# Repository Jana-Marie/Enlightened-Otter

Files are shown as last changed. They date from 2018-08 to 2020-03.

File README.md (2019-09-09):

# Enlightened-Otter

Enlightened-Otter is an Open-Source and OSHW work-light for hacker/maker events like the chaos communication congress. It is based upon a STM32F334 with its 
high resolution timer as dual boost 
converter. The main goal is to provide cordless, high CRI, high brightness, flicker-free illumination with a variable color temperature. This is achieved by using LEDs with high a CRI (>93, STW9Q14C) and 
the boost 
converter operating at a frequency of up to 850khz. The PCB also features USB-C (power profile 1) to deliver enough power to charge the 18650 type batteries as well as keep up operation of the boost converter.

Enlightened-Otter can be screwed onto an empty bottle of Mate (or similar), therefore serving with a very small footprint.

## Specs

|								| Typical Value |
| ---		| ---	|
| I*out* (per channel)	 		| 0-500mA 		|
| V*out* (per channel)			| 0-18.5V 		|
| P*out* (per channel)			| 0-7.5W*		|
| Illuminance (3500k @400mA)	| 1600lx*  		|
| Illuminance (6500k @400mA)	| 2000lx* 		|
| V*in* (USB) 					| 4.8-14V  		|
| I*in* (USB) 					| 3A  			|
| V*bat* 						| 3.8V 			|
| I*bat* (max)					| 5A  			|
| Boost frequency				| 500khz**		|
| I*ripple* (@2.5kHz)			| < 0.5mA 		|

\* Needs to be measured again
 
\** Needs to be evaluated again

## Building and flashing

Change *Inc/defines.h* to fit your desires, then build with

`make clean all`

and flash it via Ozone or st-utils

`st-flash --reset write build/*.bin 0x8000000`

## Images V2.1

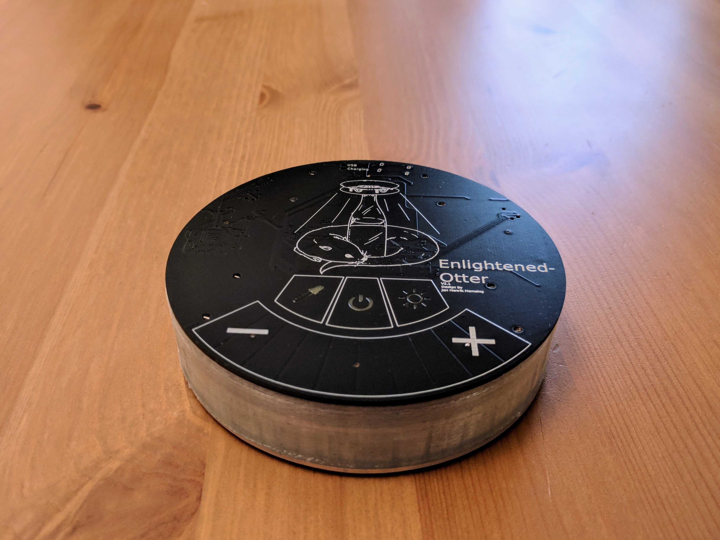
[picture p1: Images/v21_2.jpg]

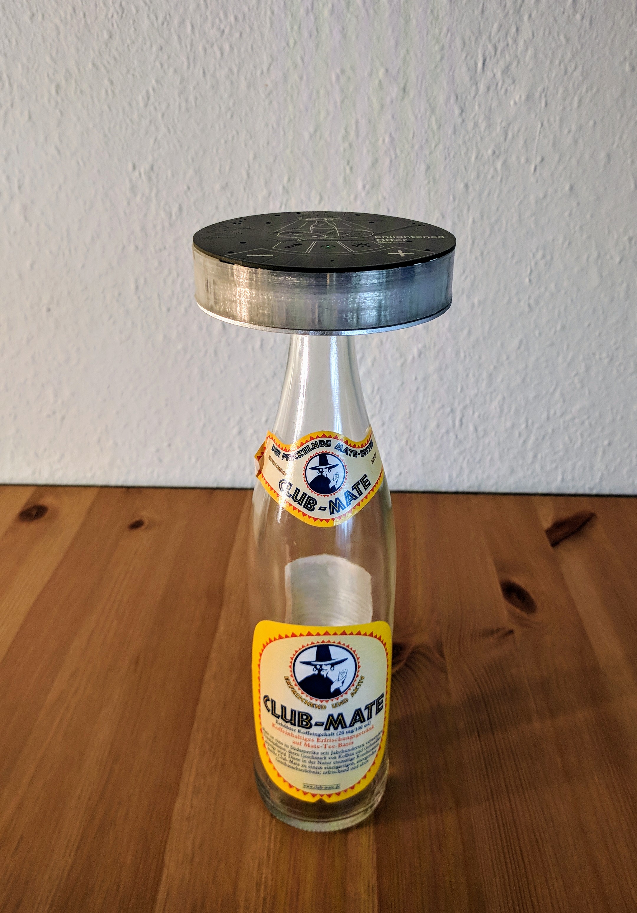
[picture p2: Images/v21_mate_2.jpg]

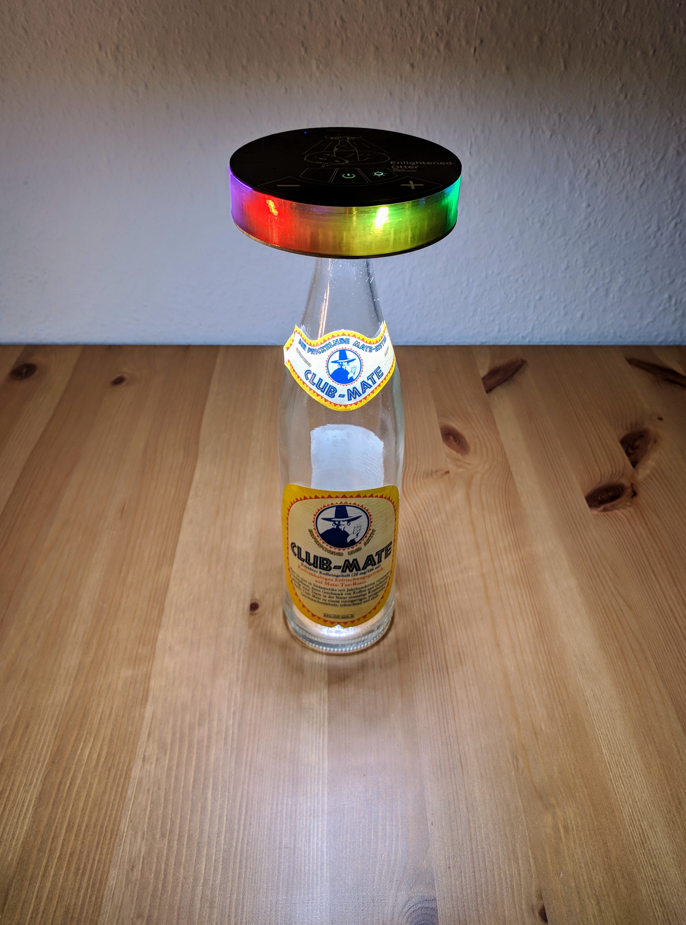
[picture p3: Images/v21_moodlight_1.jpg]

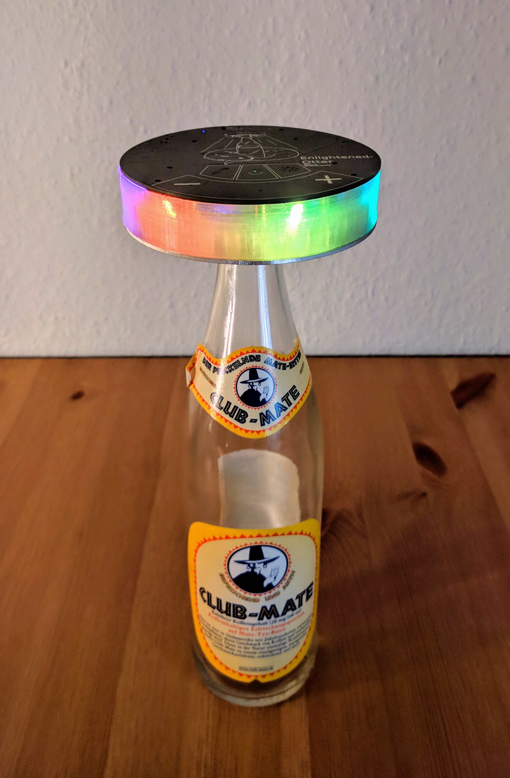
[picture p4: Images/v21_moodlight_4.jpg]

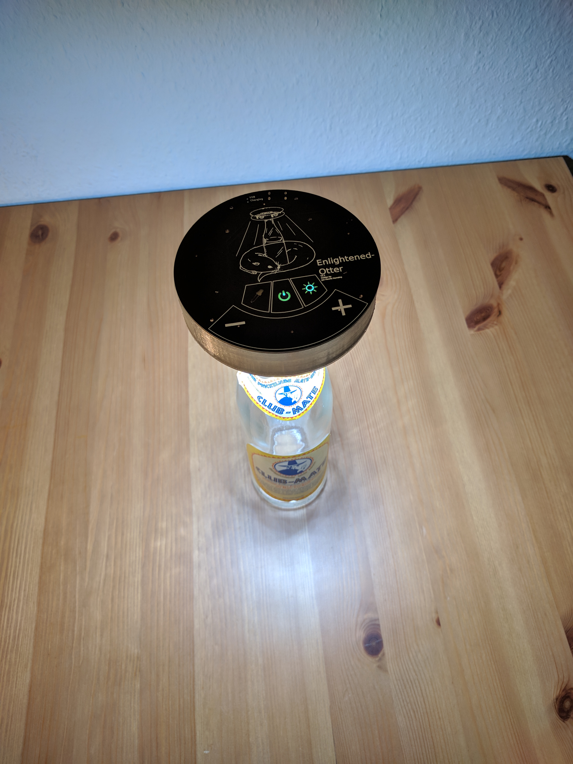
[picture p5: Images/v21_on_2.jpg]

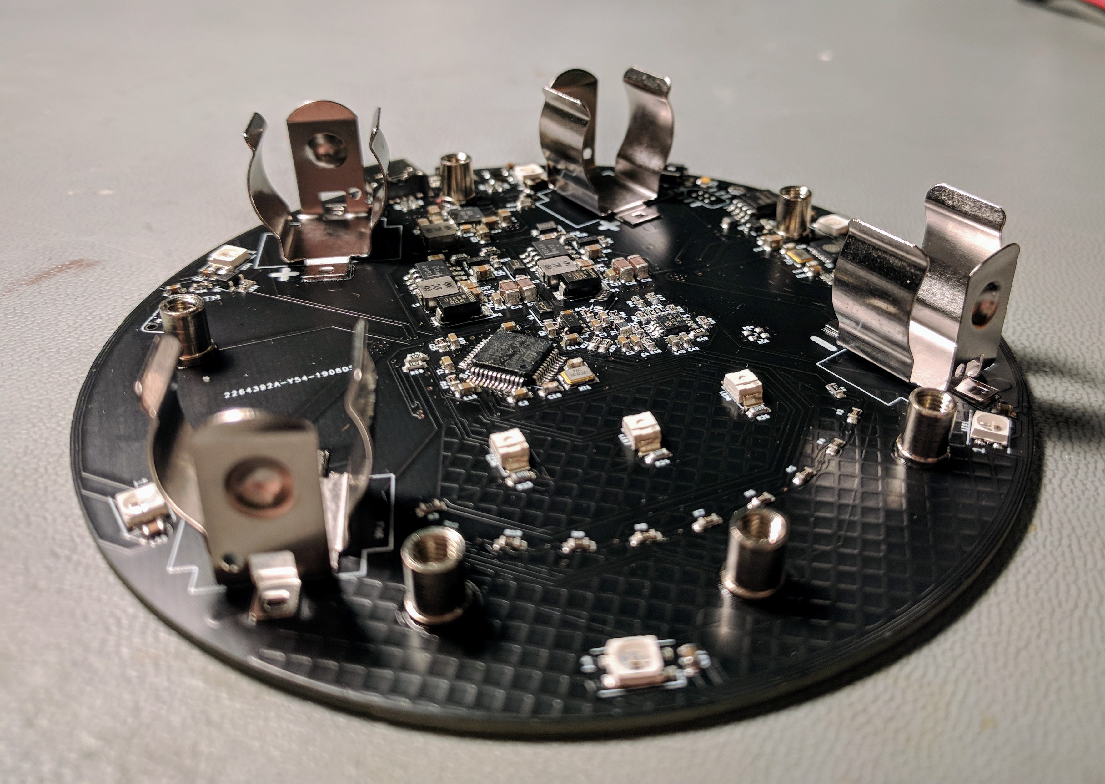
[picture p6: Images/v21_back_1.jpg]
V2.1 Back

## Images V2.0

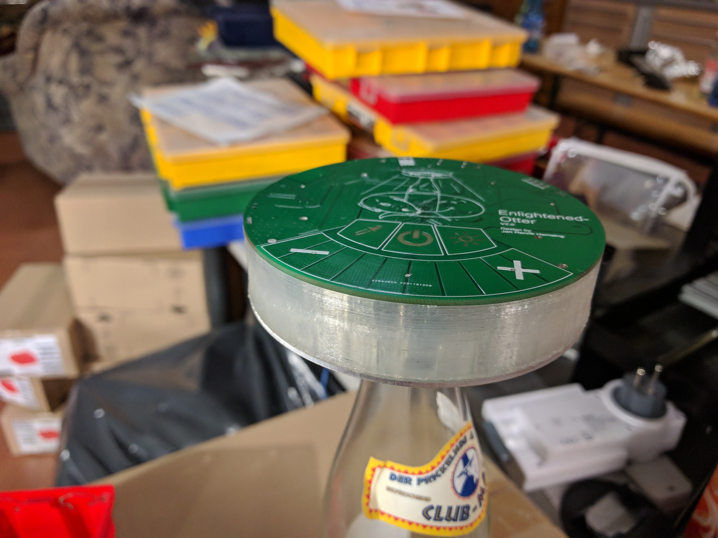
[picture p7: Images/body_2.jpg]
V2.0 Body


## Images V1.1

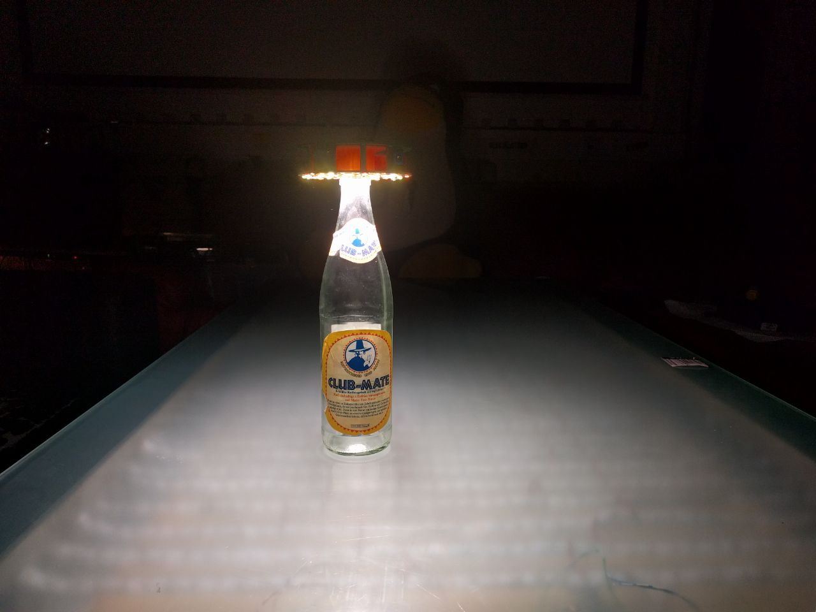
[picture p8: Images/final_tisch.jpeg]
Battery 1

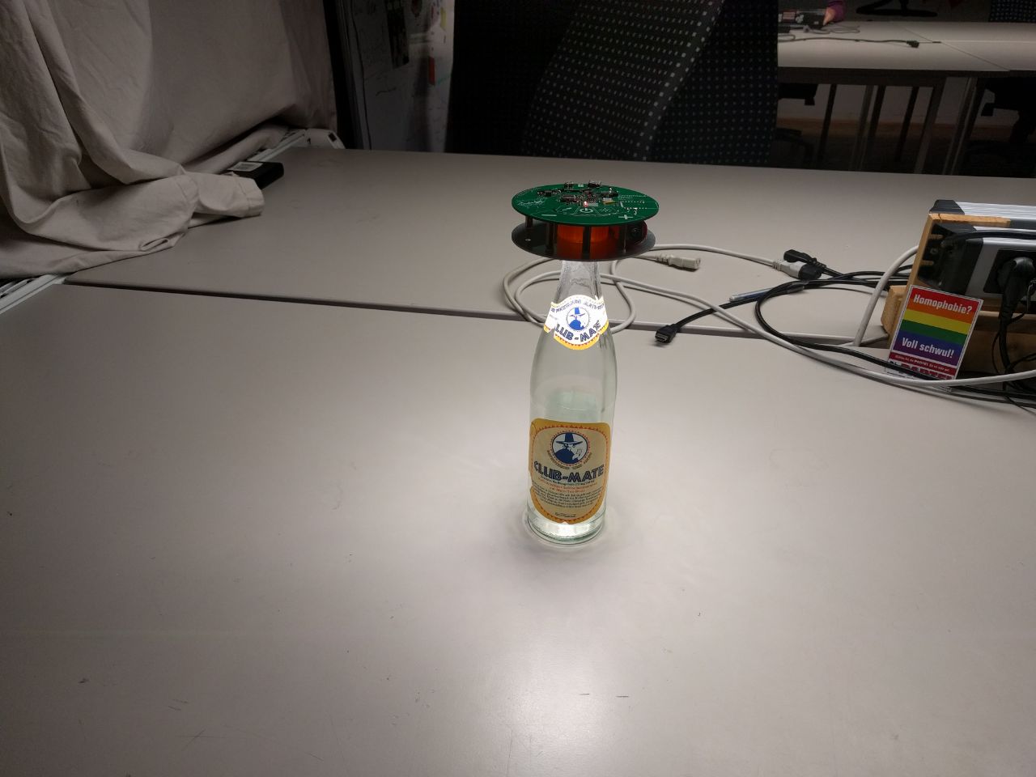
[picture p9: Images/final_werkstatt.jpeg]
Battery 2


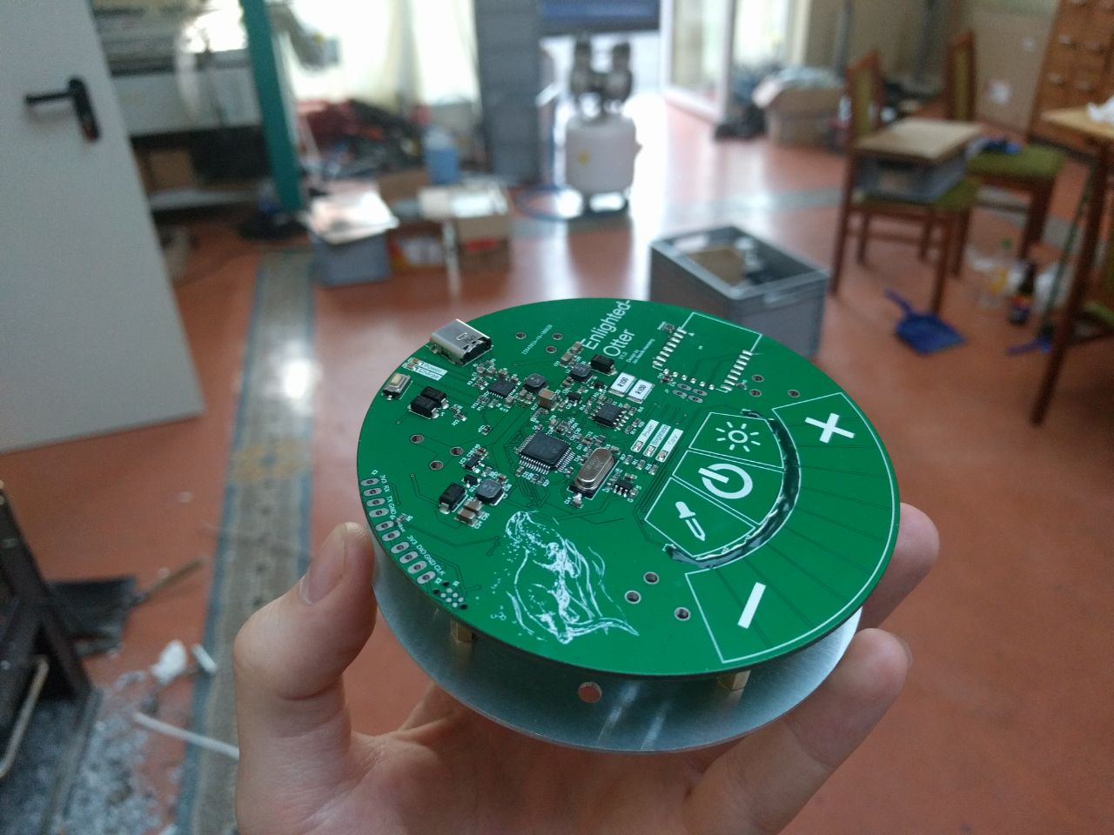
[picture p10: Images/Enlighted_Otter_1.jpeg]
Top View

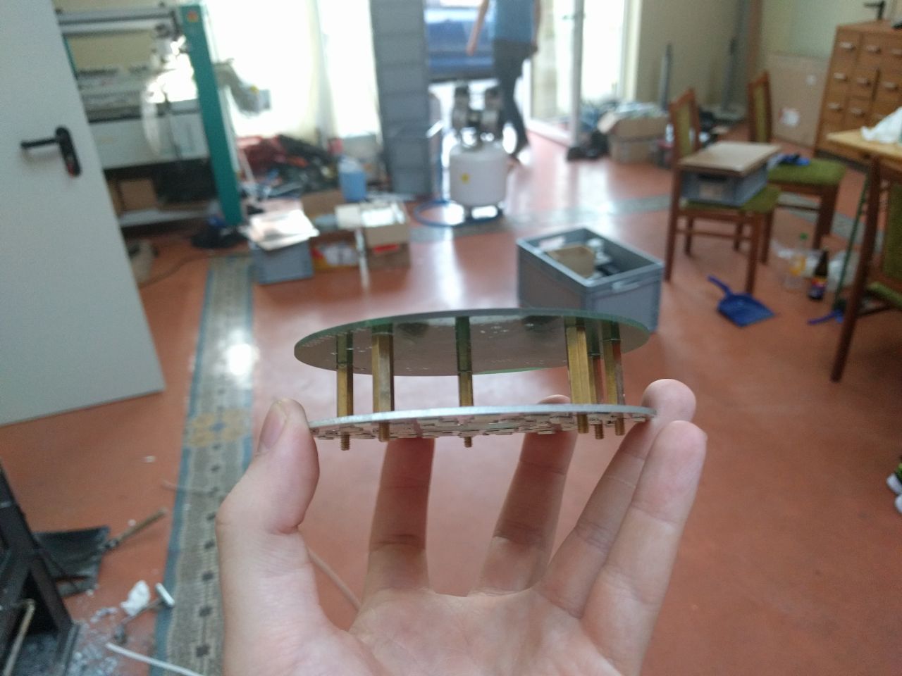
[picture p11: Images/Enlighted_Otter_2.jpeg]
Side View

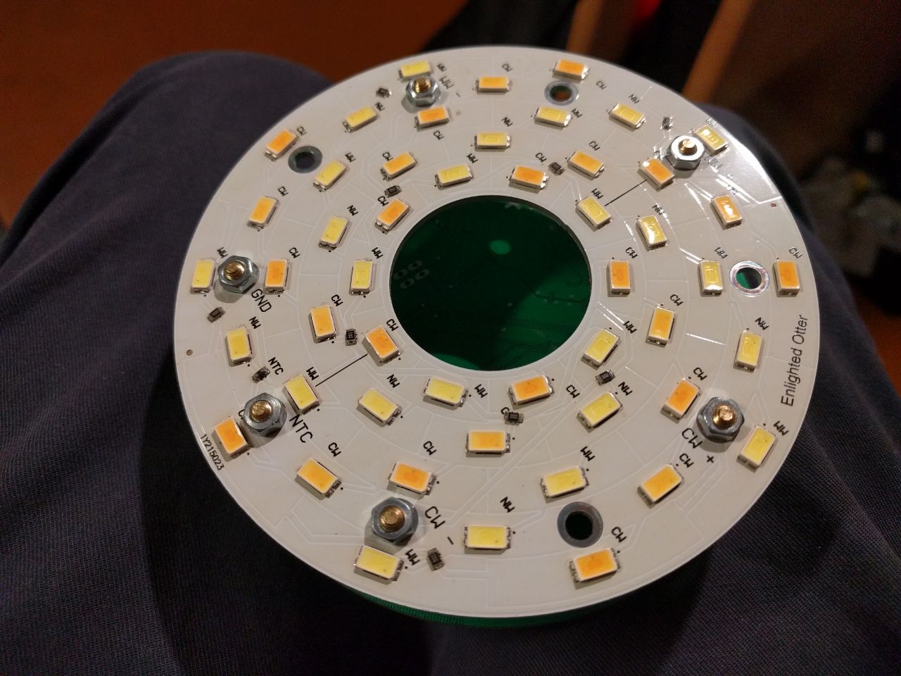
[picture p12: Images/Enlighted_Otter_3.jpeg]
Bottom View


## Videos

Click to play

#### On a Bottle

Finished Prototype (https://twitter.com/JanHenrikH/status/1033489392109797377)

#### Boost converter operation

Boost 1 (https://youtu.be/A-QjU9mWTO4)

#### TSC operation

TSC 1 (https://youtu.be/ADD4yiM9S0Q)

#### LED brightness test

LED 1 (https://youtu.be/DC_eAY72nbw)

## Known Bugs

- Touch does not work when licked (tested by @NiklasFauth)
	- Workaround: Do not lick PCB

## Planning

### Folder structure

- **Src/** : Contains the source files to build the firmware
- **Drivers/** : Contains the STM library files
- **Inc/** : Contains the header files as well as the customization file for the firmare
- **Tools/** : Contains python scripts to generate specific code
- **HW/** : Contains the Schematic, Gerber and other Hawrdware files
- **Images/** : Contains the images used in this repo
- **3D Files/** : Contains the 3D file to be printed as inlet as well as its source
- **/** : Contains other build files e.g. Makefile, linkerscript

### Current state:

PCB V2.1 is here, V2.11 is ordered.

Complete power redesign. HW is flashable, both boost converter work properly up to a current of ~500mA, current regulation works on both boost converters ( < +-0.5mA up to 500mA, regulation frequency is 2.5khz), RT9466 seems to do its job, does work properly on 
batteries, not on USB. Measuring thought the RT does not work, Power down does. LED outputs and Touch inputs work, has correct fault handling.
Advanced User interface is also working, current and color can be set via touch input. Soft on/off works fine. Gamma correcture is applied.
The whole PCB can be shut down by holding the power button.

HW regulates after boot while main loop is basically empty \o/

### To do:

- [ ] measuring throught the RT does not work
- [ ] ADC1 wrong values -> investigate
- [ ] test esp8266
- [ ] implement esp8266
- [ ] visualize battery voltage -> moodlight LEDs
- [ ] Overtemp protection
- [ ] Find more to do's

### Done:

- [x] Implement moodlight LEDs
- [x] touch slider is not super responsive -> investigate
- [x] "Mobile handling"
	- [x] Touch is not that responsive
	- [x] Added filters to touch input
	- [x] Battery low alarm/turnoff -> is implemented, doesnt work, see RT9466 measuring
- [x] everything is super slow when Itarget is 0.0 -> investigate
- [x] UVP
- [x] Port firmware to V2.1
- [x] RT cannot be turned off or cannot charge batteries - investigate
- [x] Optimize code
	- [x] make it less ugly
	- [x] now make it faster
- [x] Test I2C - broken?
	- writing works, reading is buggy, switch to dma
	- [x] implemented DMA
	- [x] Receiving data does not work properly, data is present but not written into the variable
		- switched msb and lsb -.-
- [x] rewrite gamma correction
	- [x] use old one, but interpolate between points
		- didnt work properly, will do later
	- [x] Test it
- [x] find MPP
	- is at ~500khz
- [x] Fix regulator above 180mA
	- is flickering quite alot above 180mA
	- [x] Rewrite regulation, seems to be flickering
		- was gamma correction causing that problem
- [x] HW
	-  See HW/README.md
- [x] Make user Interface more responsive
- [x] Order new PCB (V1.1)
- [x] 3D Design
- [x] get rid of flicker at 0.5-2.5mA 
- [x] temperature calculation
- [x] get rid of global variables
	- moved them into structs
- [x] make the code more Timer/Interrupt based
	- [x] HRTIM
	- [x] HRTIM FLT
	- [x] ADC
	- [x] TSC
	- [x] I2C/UART
	- [x] Regulator
	- [x] UI
- [x] gamma correction
	- [x] write tool to generate gamma correction curve
	- [x] Implement it
	- [x] Test/debug it
- [x] Fix the HRTIM FLT1 line
- [x] Test Injected ADC
	- [x] ADC tested and seems to work just fine
	- [x] Add moving average filter to smooth out ADC values
	- [x] Add JEOC Interrupt
- [x] current calculation
- [x] Fix/write TSC controller
	- [x] Add second TSC bank
	- [x] Make it interrupt based
		- [x] write code
		- [x] Test that
- [x] Fix I2C timing/Interrupt issue
- [x] Get HRTIM to run
- [x] Get the LED's to light up
- [x] Write regulator
	- [x] Write simple, working I regulator
	- [x] Make it cycle time independent
	- [x] Make regulator interrupt based
	- [x] Write a better PI regulator
- [x] Basic TSC,UART,DAC,COMP,I2C and GPIO functionality
- [x] Write the user interface
	- [x] Make it usable
- [x] Readout of touchslider
- [x] Be an otter
- [x] PCB does not burn

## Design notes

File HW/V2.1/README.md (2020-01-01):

### Assemby instructions

Everything can be assembled as per manufacturer except for the following parts.

 - LED1,LED2,LED3 are per BOM sidemounted LEDs but they have to be rotated by 90 degrees and treated as reverse mount leds.
 - The studs cannot stand by themselfes, thus they have to be supported while reflowing
 - D7,D8 are normal 0805 LEDs but also reverse mounted
 
 - After reflowing the batteries can be inserted, EO should boot up and the middle led should light up. EO can now be flashed via Tag-connect
 - before adding the LED pcb it is mandatory to turn off EO!
 - Insulating washers (TO220 isolators) have to be added to all studs except for the GND stud, a non isolating washer has to be addded here
 - Use conducting screws and don't tightem them too much, try to reduce stress introduced into the pcb

### Changelog HW 2.11:

- re-routed everything, this time with good power design
- made pads for studs larger in diameter
- switched to kicad

V2.1

### Todo list

- [x] SW 2.1
- [ ] SW 2.11
- [ ] Test LEDS and ESP
  - [x] LEDS
  - [ ] ESP

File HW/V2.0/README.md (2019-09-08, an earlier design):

### Changelog HW 2.0:

- Moved all parts to the bottom side
- Changed battery clips to SMD
- Added fuses
- Removed GND-Plane around the Touch-Pads
- Better power plane splitting
- Changed ESP footprint
- Added moodlight leds

Assembled HW 2.0, seems to be much sturdier, everything looking good. GND-Plane is broken, NTC return GND is broken. Tocuh performance is much better, analog performance seems to be much better (needs to measured). Current goes now up to 499mA

### Todo list

- [ ] SW 2.0
	- [x] fix i2c
	- [x] take measurements, configure EO
		- looks good so far
	- [x] fix auto turnoff
	- [ ] No current > 499mA (EO will turn off)
	- [ ] Test LEDS and ESP
		- [x] LEDS
		- [ ] ESP
	- [x] fix touch direction and intensity

- [x] HW 2.0
	- [x] move 254TR closer together
	- [x] move parts to the bottom side
	- [x] add esd protection resistors
		- touch
		- ntc
	- [x] fix usb plug
	- [x] Optimize values in circuit
	- [x] fix touch
		- round planes, remove ground
		- Needs to be tested
	- [ ] Fix GND-Plane
	- [ ] FIX values as in "Noted"
	- [ ] FIX NTC-GND

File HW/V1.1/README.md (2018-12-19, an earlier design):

### Changelog HW 1.1:

- Fixed tha battery clip position
- Gate drivers are now powered by the boost converters, thus they are bootstrapping themselfes
- VIN measurement is not needed anymore, hardware removed
- Added mosfet to power rail of ESP
- Fixed USB Footprint
- Added pullup to NTC
- Added Gate pulldowns
- Added USB pulldowns
- Fixed Schematic symbols and values
- Increased Gate resistors
- Added Bootstrap diodes

### Todo list

- [ ] HW 1.1 (again)
	- [ ] Optimize values in circuit
	- most 47k to 33k
	- there are too many different capacitor values
	- [x] Order MIC5504-3.0

- [x] HW 1.1
	- [x] Add bootstrap diodes to start the gate drivers
	- [x] Increase Gate resistor to at least 56 Ohm and maybe add gate capacitor
	- [x] Move 18650 clips to fit battery
	- dont fit the battery, move by 1-2mm
	- [x] Add pullup to NTC (LED)
	- 10k
	- [x] Check USB footprint
	- Part didnt fit footprint that well, already changed but not tested!
	- [x] Remove VIN measurement
	- not needed anymore
	- [x] Add CC1,CC2 pulldown resistors
	- Had only one and CC1/2 connected together, ofc that didn't work
	- [x] Check for analog design improvements
	- Analog design seems to be okay by now, will check later again :3
	- pushed something here and there, i guess its fine now
	- [x] Gate pulldowns
	- Gate driver has no pulldowns, unknown behaviour while not driven
	- [x] Reduce Boost inductance
	- 15uH is too high, 3.3uH is better, also increase dc-current, maybe use this inductor https://de.rs-online.com/web/p/drahtgewickelte-smd-induktivitaten/9236194/
	- [x] Change voltage regulator to 3.0V type
	- Is still 3.3V type in schematic, 3.0V was used for testing
	- [x] Divide Vin voltage divider resistance by 10
	- ~~Resistance seems to be too high, measuring falsifies the result~~ measured to fast, meh! Is fixed now
	- [x] Add Mosfet to turn ESP off
	- ESP will be turned on all the time, add sleepmode and/or switched power 
	- [x] Check schematic symbols
	- Mosfets and inductors have the wrong part numbers (mosfet has to be DMN3404L-7, inductor to be determined)
	- [ ] Export PCB design files to kicad and publish
	- Also export Gerber?
	- [x] Fix OTG mode
		- ~~Device enters not automatically OTG mode, can be done in software or with hardware IO. Problem: OTG/USB voltage is needed for the mosfet drivers. Thus USB has to be rpesent or OTG has 
to be turned on. OTG being turned on means, that on USB power it can't know that it has to move abck to charger mode. Idea 1: use a diode behind the USB plug drive OTG mode from IO and set IO with VUSB 
-> meh Idea 2: move Vgatedriver to VMID, VMID has OTG capabilities~~
		- VSupply of the Gate driver aro to be connected to the outputs of the boost converters. Circuitry gets more effizient when boost converter is running
		- maybe check if there is a cheaper battery management IC as OTG is not needed anymore

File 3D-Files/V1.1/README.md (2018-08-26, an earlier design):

## 3D printed insert

The 3D printed insert should fit a "Club Mate" bottle as well as most glass limonade bottles.

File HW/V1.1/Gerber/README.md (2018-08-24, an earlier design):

## Gerber V1.1

Gerber files are provided "as is" and without warranty.

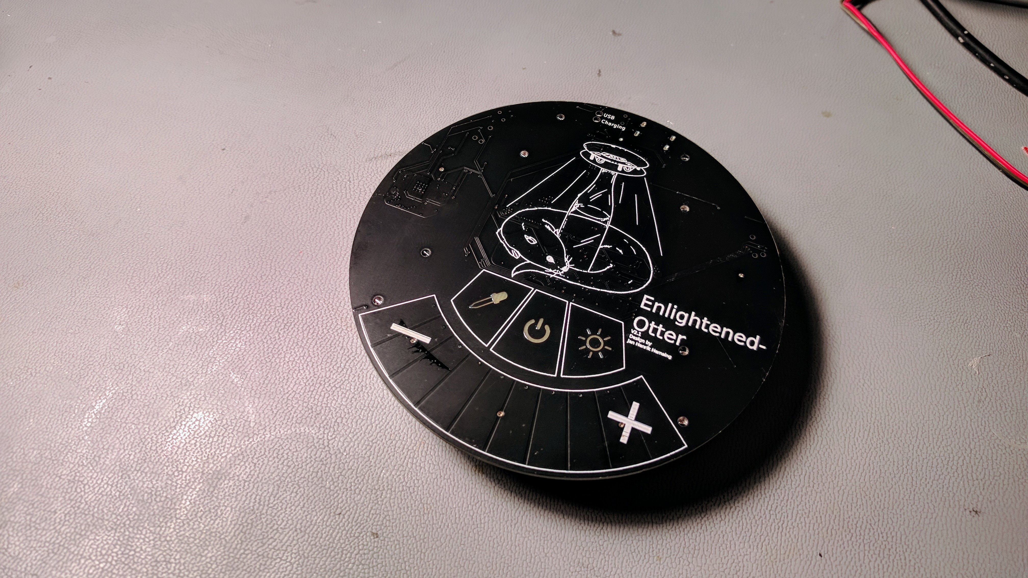
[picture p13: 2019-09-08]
Images/v21_front_1.jpg

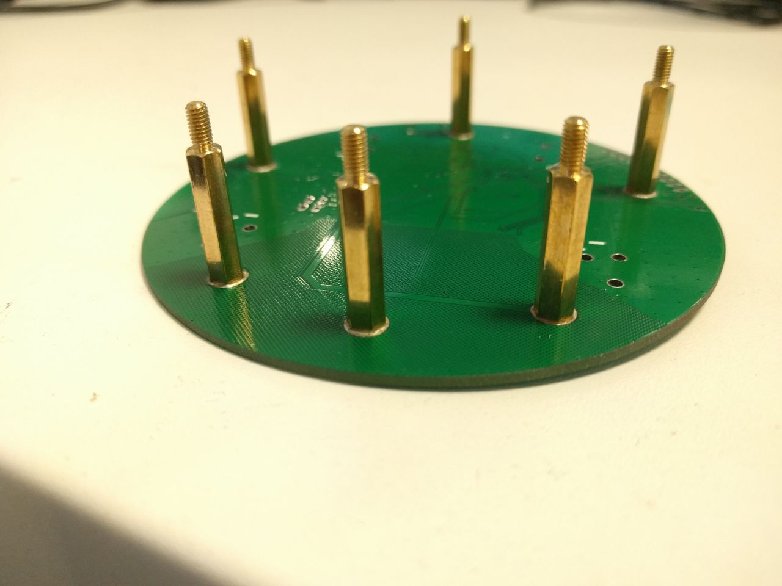
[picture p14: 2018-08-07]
Images/spacer_2.jpeg

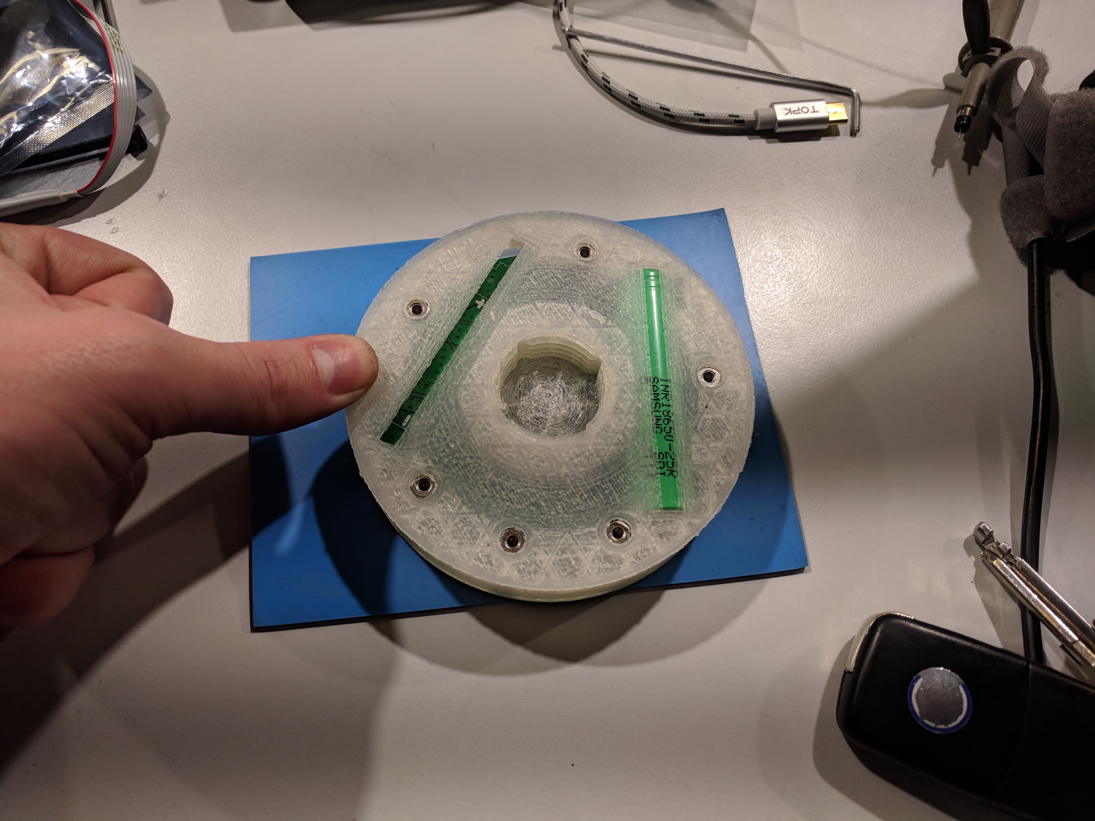
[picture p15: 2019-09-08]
Images/body_1.jpg

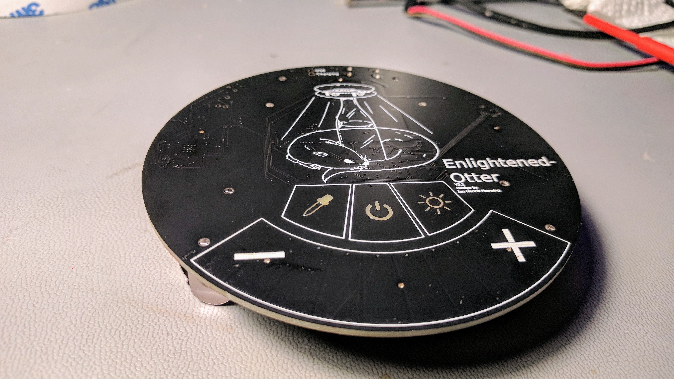
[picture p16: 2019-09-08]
Images/v21_front_2.jpg

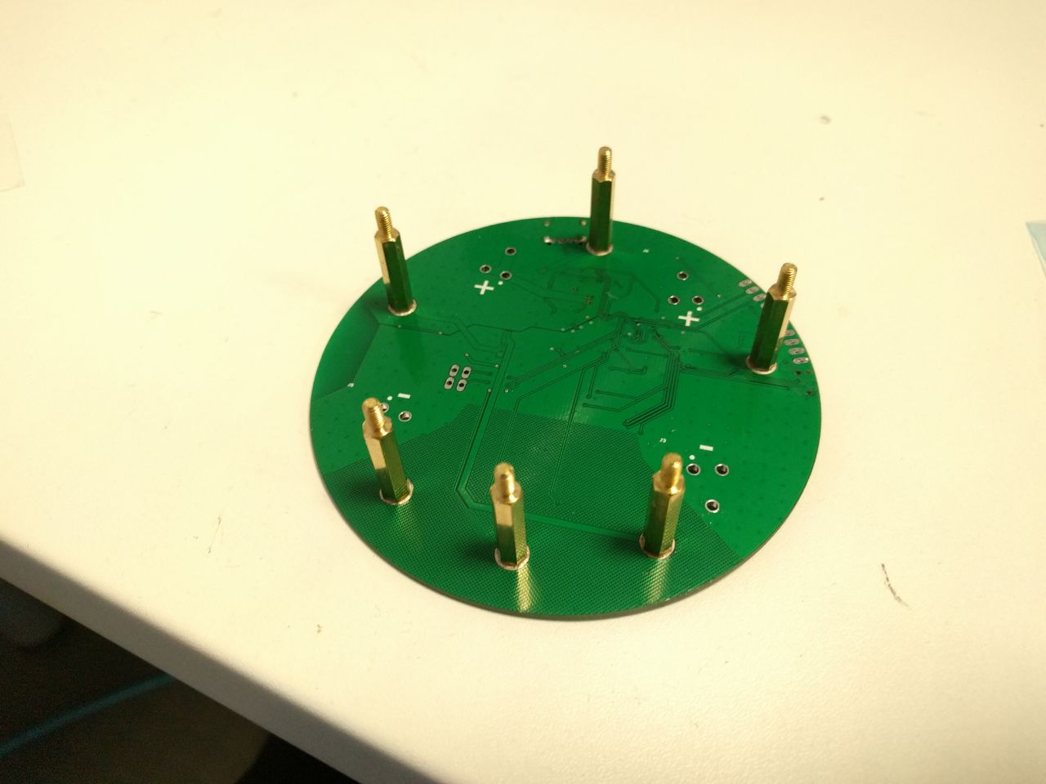
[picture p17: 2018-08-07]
Images/spacer_1.jpeg

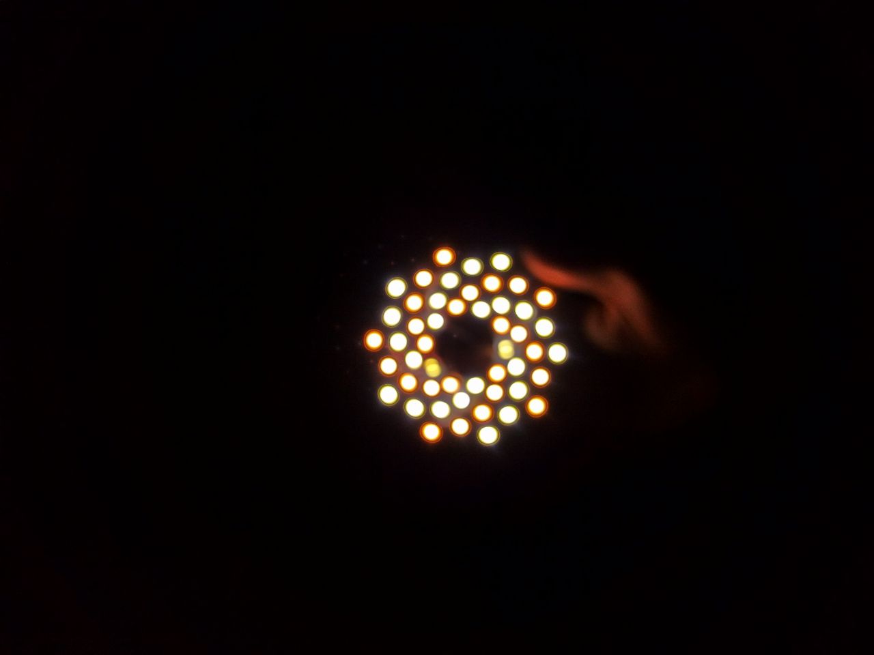
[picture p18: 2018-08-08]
Images/led_1.jpeg

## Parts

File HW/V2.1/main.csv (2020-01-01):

Comment | Designator | Footprint | LCSC
254 Keystone | 254_1,254_2 | otter:254
AN9520 | ANT1 | otter:AN9520_Rainsun
M3 Screw | AnodeW1,AnodeC1,KathodeW1,KathodeC1,gnd1,ntc1 | otter:M3_Screw
18p 50V | C12,C10,C9,C44,C39,C46 | Capacitor_SMD:C_0603_1608Metric
82n | C15,C11 | Capacitor_SMD:C_0603_1608Metric
47nF 16V | C18 | Capacitor_SMD:C_0603_1608Metric
10u 25V | C21,C24,C23,C19,C20,C17,C33,C54,C52,C53,C26,C51,C32,C22,C14 | Capacitor_SMD:C_0805_2012Metric
100n 50V | C25,C37,C30,C34,C27,C49,C47,C45,C43,C31,C57,C4,C16,C1,C2,C5,C6,C13,C48,C50,C56,C55,C38,C58 | Capacitor_SMD:C_0603_1608Metric
4.7u 50V | C28,C29,C35,C36 | Capacitor_SMD:C_1206_3216Metric
1u 25v | C3,C7 | Capacitor_SMD:C_0603_1608Metric
10n 50V | C41,C40,C42 | Capacitor_SMD:C_0603_1608Metric
1u 25V | C8 | Capacitor_SMD:C_0603_1608Metric
SS310 | D1,D3 | Diode_SMD:D_SMA
SK210 | D2,D4,D6,D5,D10 | Diode_SMD:D_SOD-123F
Red 0805 | D8,D7 | otter:LED_Reverse
Red 0603 | D9 | LED_SMD:LED_0603_1608Metric
Ferret | FB1,FB2 | Inductor_SMD:L_0805_2012Metric
RT9466 | IC1 | Package_DFN_QFN:QFN-24-1EP_4x4mm_P0.5mm_EP2.6x2.6mm
MIC4416 | IC3,IC2 | Package_TO_SOT_SMD:SOT-143
USB-C 6 Pin | J4 | otter:USB-C_Power
4.7u 3.5A 74438357047 | L3,L2, L1 | Inductor_SMD:L_Taiyo-Yuden_MD-4040
SK6812 Mini | LED1,LED2,LED3,LED4,LED5,LED9 | otter:sk6812mini
99-213SUBP/S3052/TR8 | LED6,LED7,LED8 | otter:LED_1206_3216_BACK
DNP | NTC1 | Resistor_SMD:R_0603_1608Metric
FDN360P | Q1,Q4 | Package_TO_SOT_SMD:SOT-23
NTMS4816NR2G | Q2,Q3 | Package_SO:SO-8_3.9x4.9mm_P1.27mm
1.5k | R27,R28 | Resistor_SMD:R_0603_1608Metric
300 | R29 | Resistor_SMD:R_0603_1608Metric
28k | R3,R4,R5,R11,R10,R9,R8,R7,R6 | Resistor_SMD:R_0603_1608Metric
5.1k | R30,R26,R50,R1,R2 | Resistor_SMD:R_0603_1608Metric
0 | R31,R34 | Resistor_SMD:R_1206_3216Metric
220k | R33,R32,R45,R44,R39,R36 | Resistor_SMD:R_0603_1608Metric
6.2 | R35,R38 | Resistor_SMD:R_0603_1608Metric
1k | R42,R41,R25,R24,R23,R51 | Resistor_SMD:R_0603_1608Metric
47k | R43,R37,R40,R58,R57,R21,R18 | Resistor_SMD:R_0603_1608Metric
220m | R47,R46 | Resistor_SMD:R_0603_1608Metric
12k | R49,R48,R53,R12,R14,R15,R16,R52 | Resistor_SMD:R_0603_1608Metric
0 | R55,R54 | Resistor_SMD:R_0603_1608Metric
10k | RT1,RT2,R20,R22,R19,R17,R13,R56 | Resistor_SMD:R_0603_1608Metric
Panasonic EVQPUL EVQPUC | T2 | Button_Switch_SMD:Panasonic_EVQPUL_EVQPUC
STM32F334C8T6 | U1 | Package_QFP:TQFP-48_7x7mm_P0.5mm
MIC5501-3.0V | U2 | Package_TO_SOT_SMD:SOT-23-5
BY25Q64ASSIG | U3 | otter:SSOP-8_5.25x5.24mm_P1.27mm_WIDE_MULTI
MCP6L2T-E/MS | U4 | Package_SO:MSOP-8_3x3mm_P0.65mm
ESP8266EX | U5 | Package_DFN_QFN:QFN-32-1EP_5x5mm_P0.5mm_EP3.45x3.45mm
BS801B | U6 | Package_TO_SOT_SMD:SOT-23-6
6.00MHz 3225 | XT1,XT2 | otter:Oscillator_3225

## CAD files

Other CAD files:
3D-Files/V1.1/thread.scad

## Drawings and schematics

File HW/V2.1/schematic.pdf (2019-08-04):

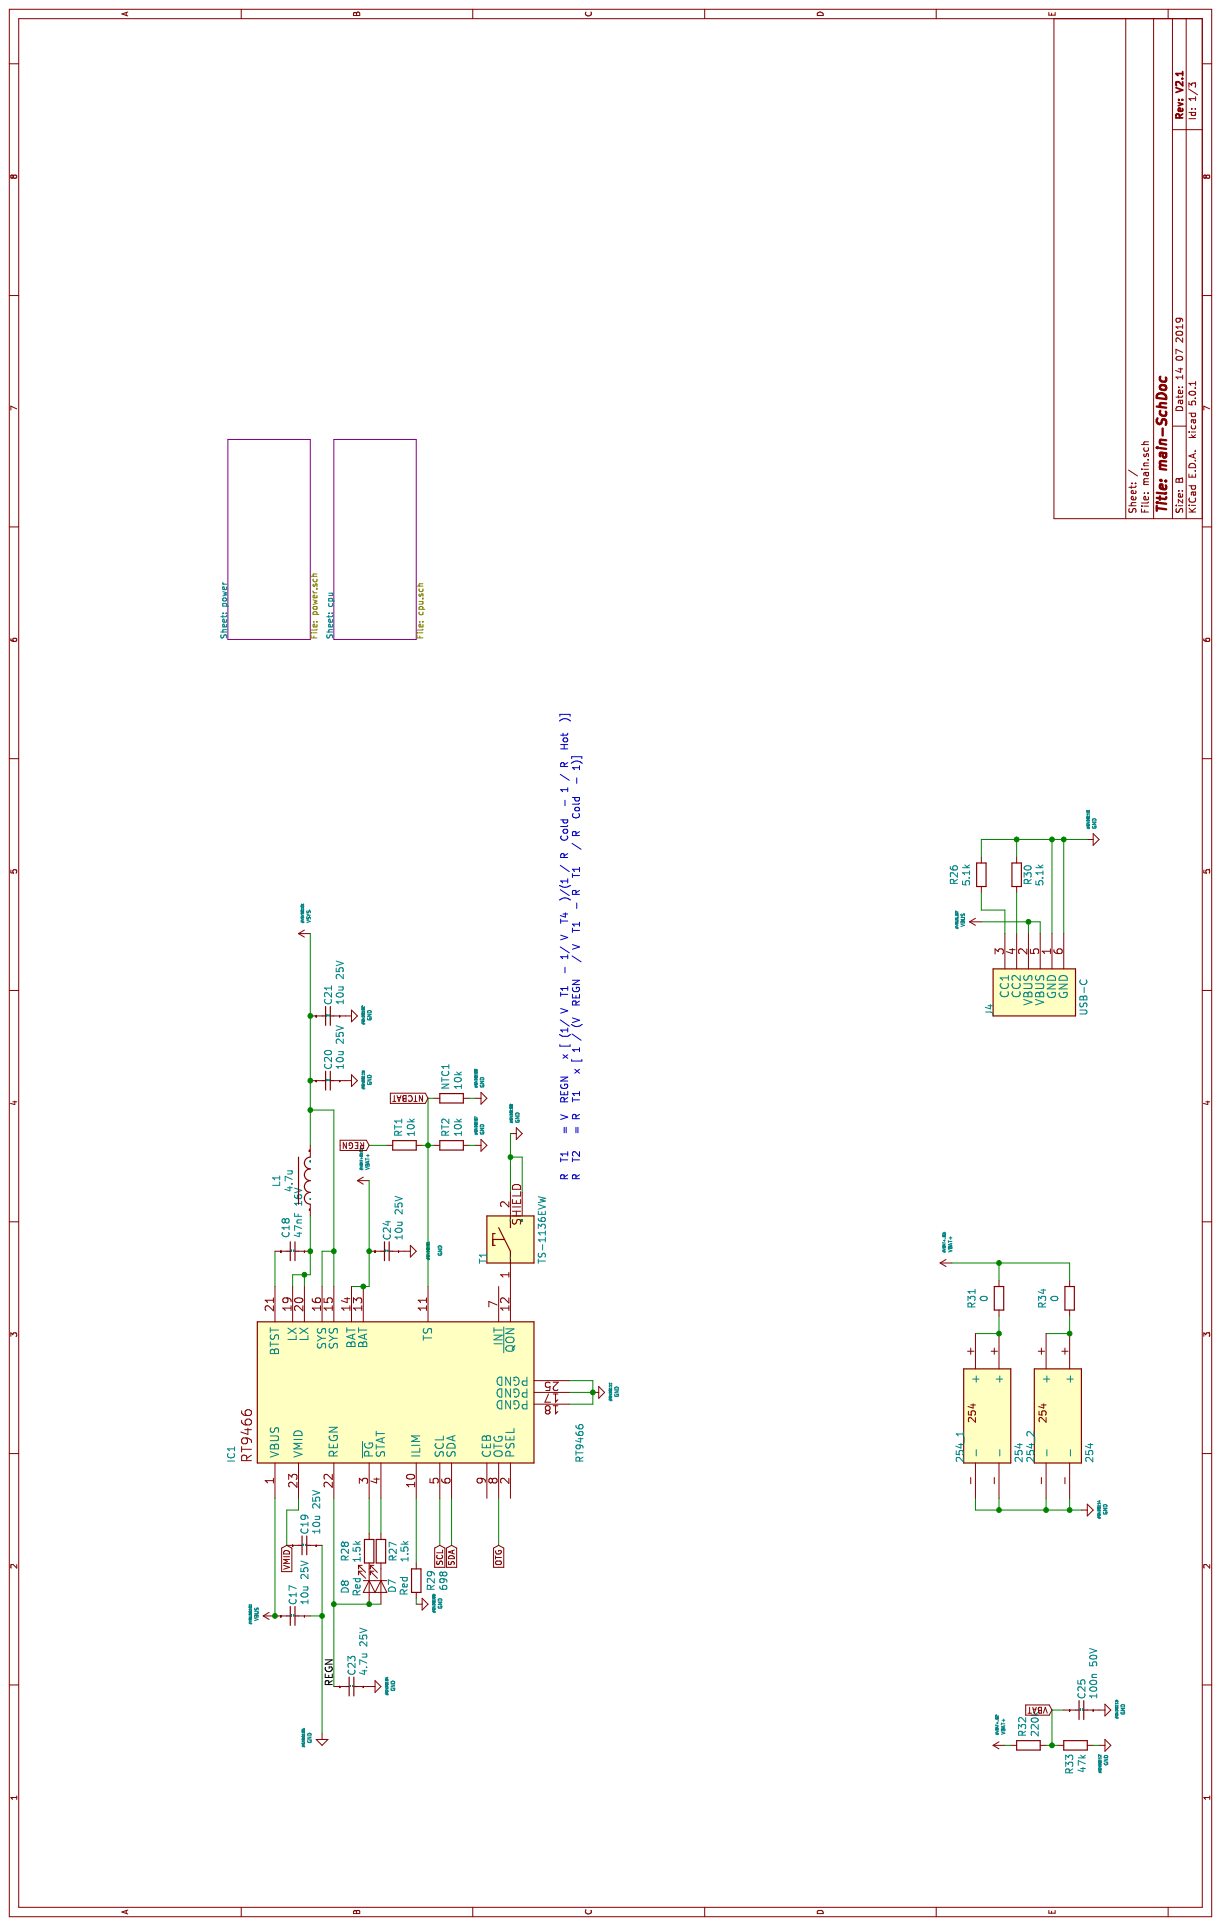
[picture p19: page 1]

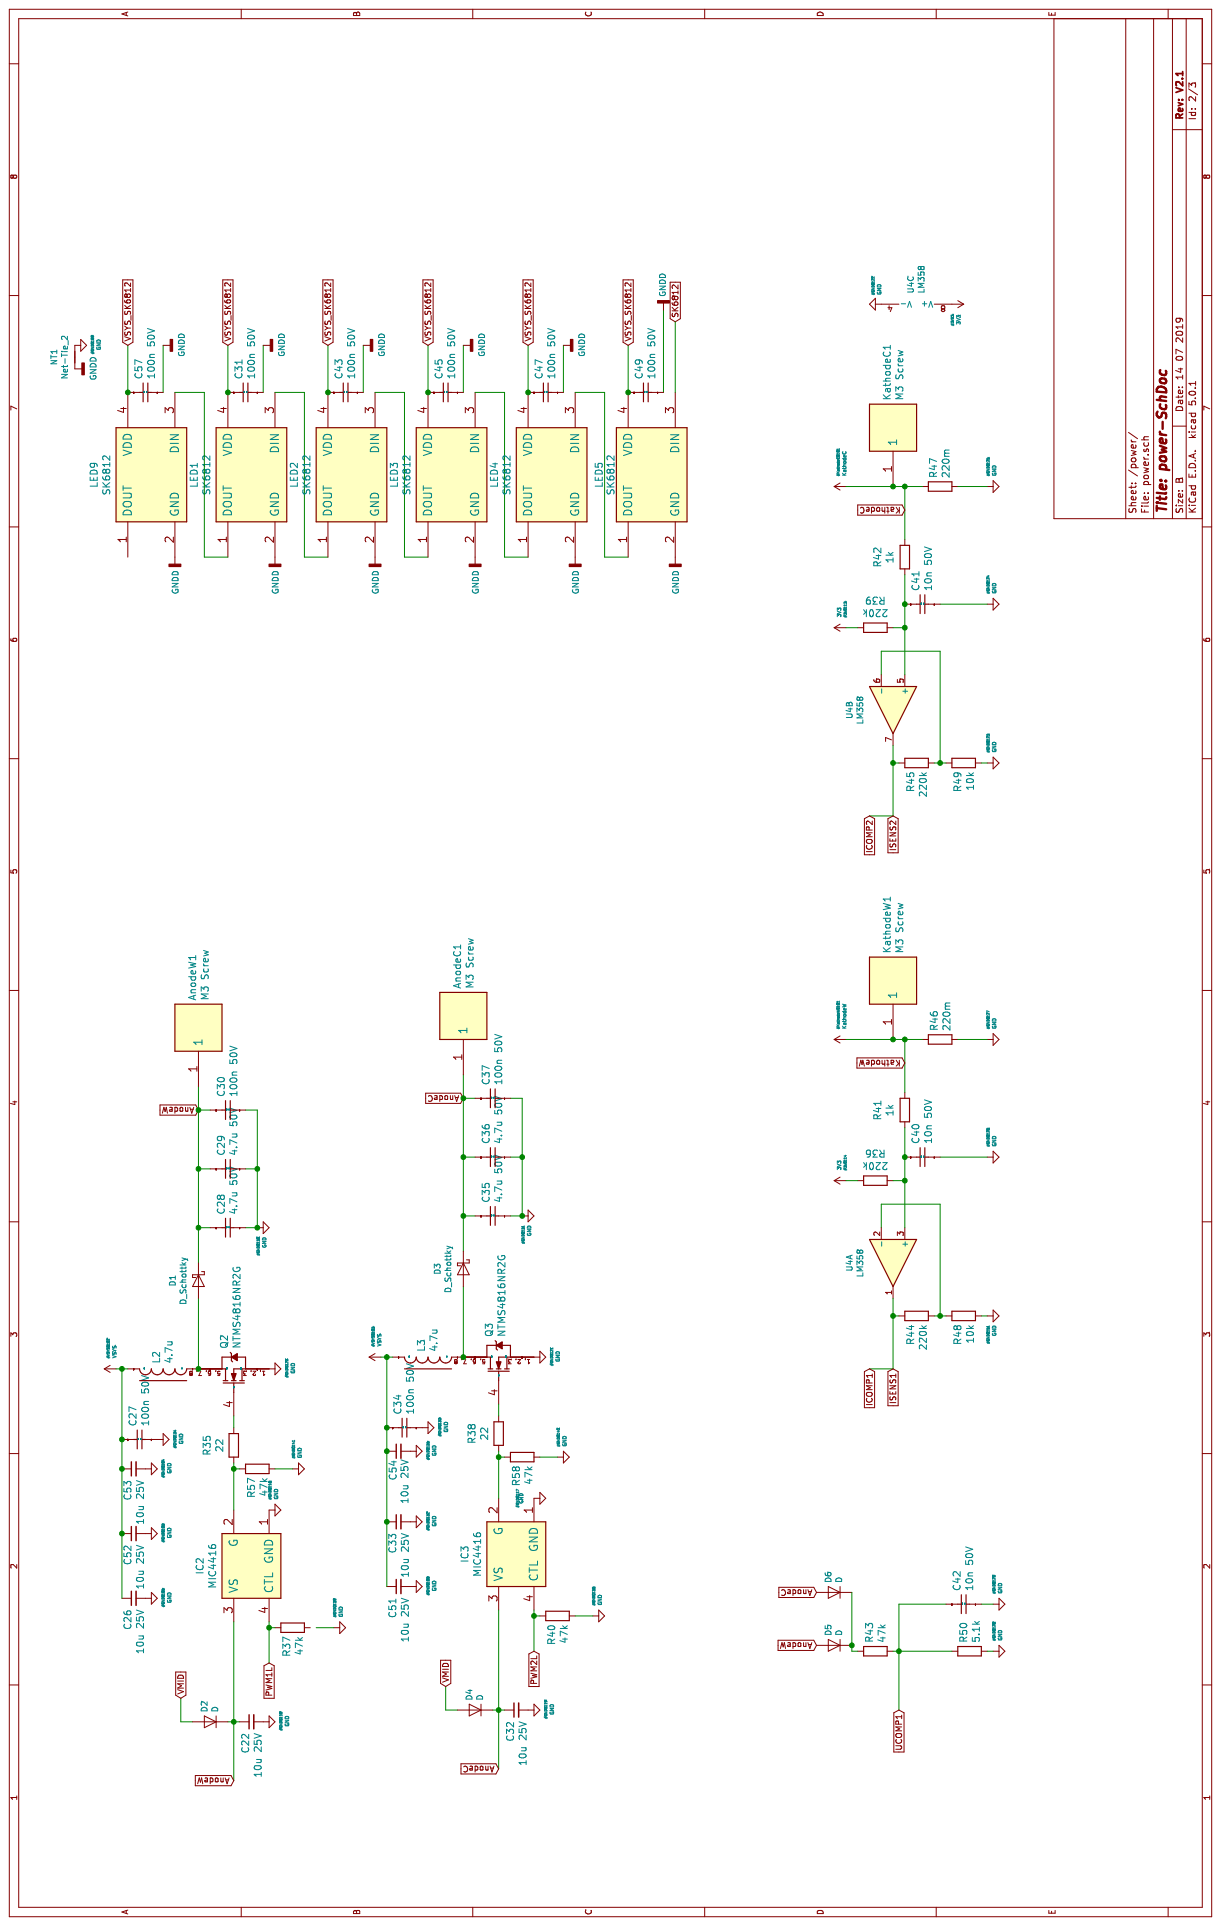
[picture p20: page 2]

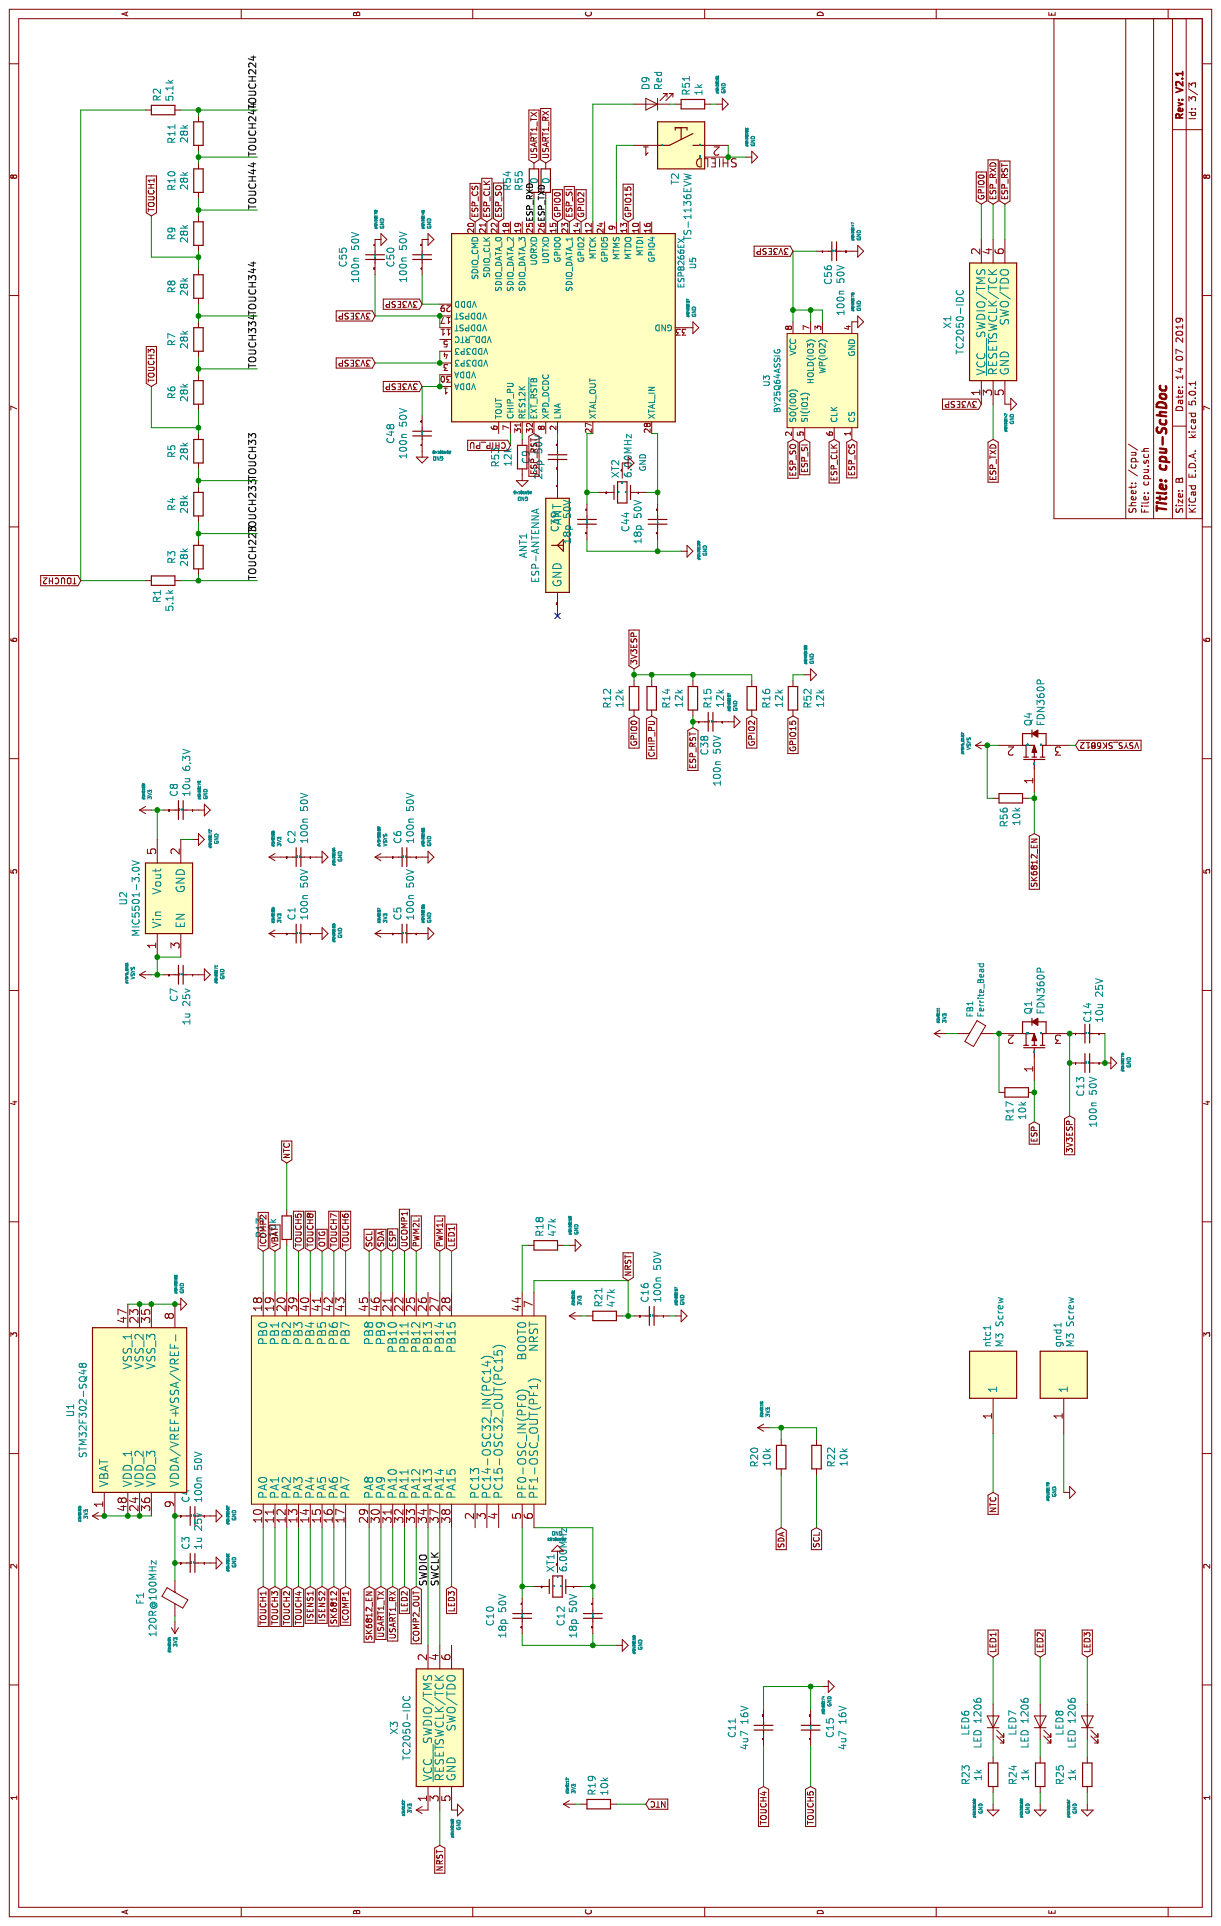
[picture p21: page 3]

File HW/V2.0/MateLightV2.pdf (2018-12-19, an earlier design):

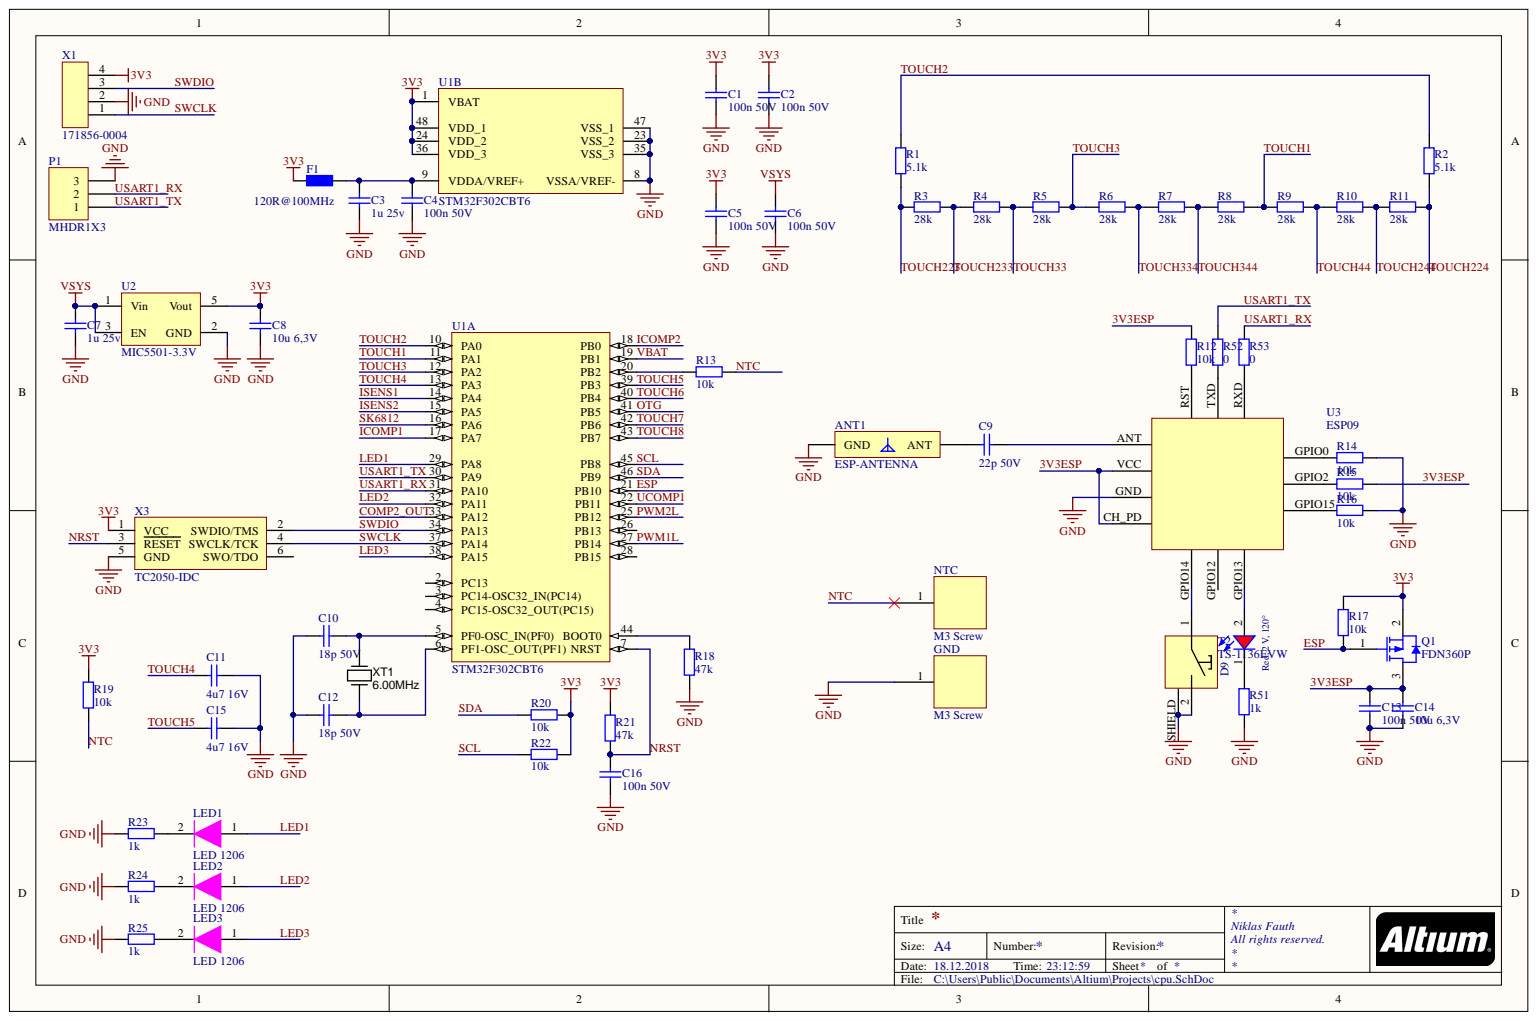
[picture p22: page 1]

2 VCC 1 GND

* Title | * Niklas Fauth All rights reserved. * *

Size: A4 | Number: * | Revision: *
Date: 18.12.2018 Time: 23:12:59 | | Sheet * of *

C:\Users\Public\Documents\Altium\Projects\cpu.SchDoc

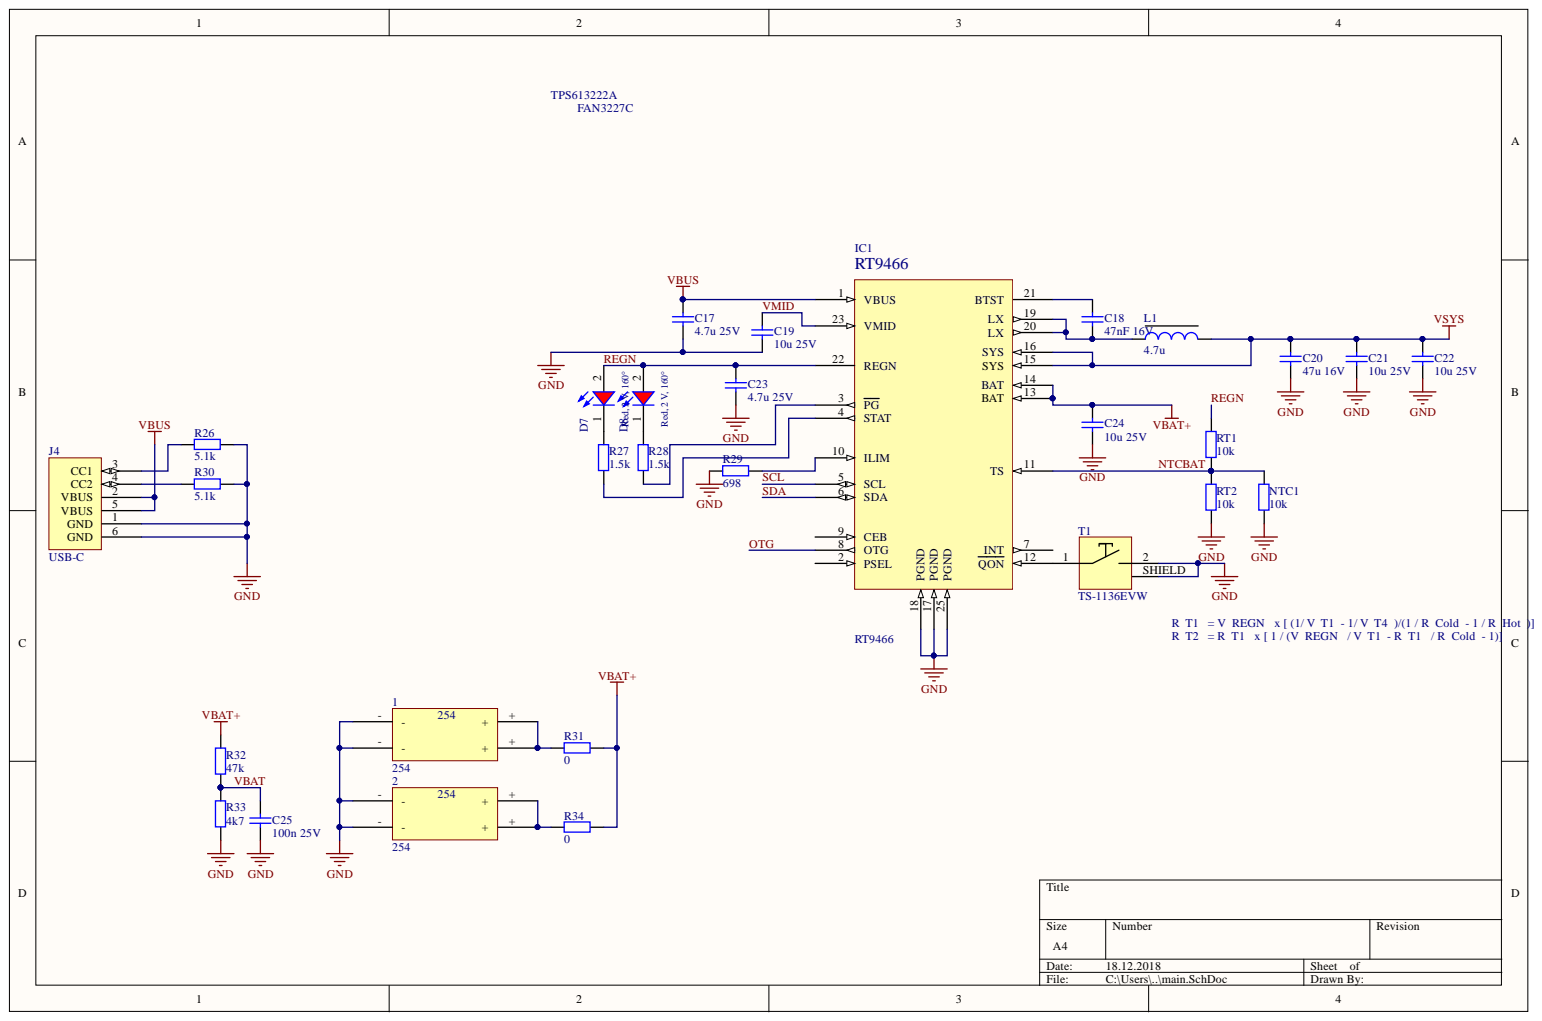
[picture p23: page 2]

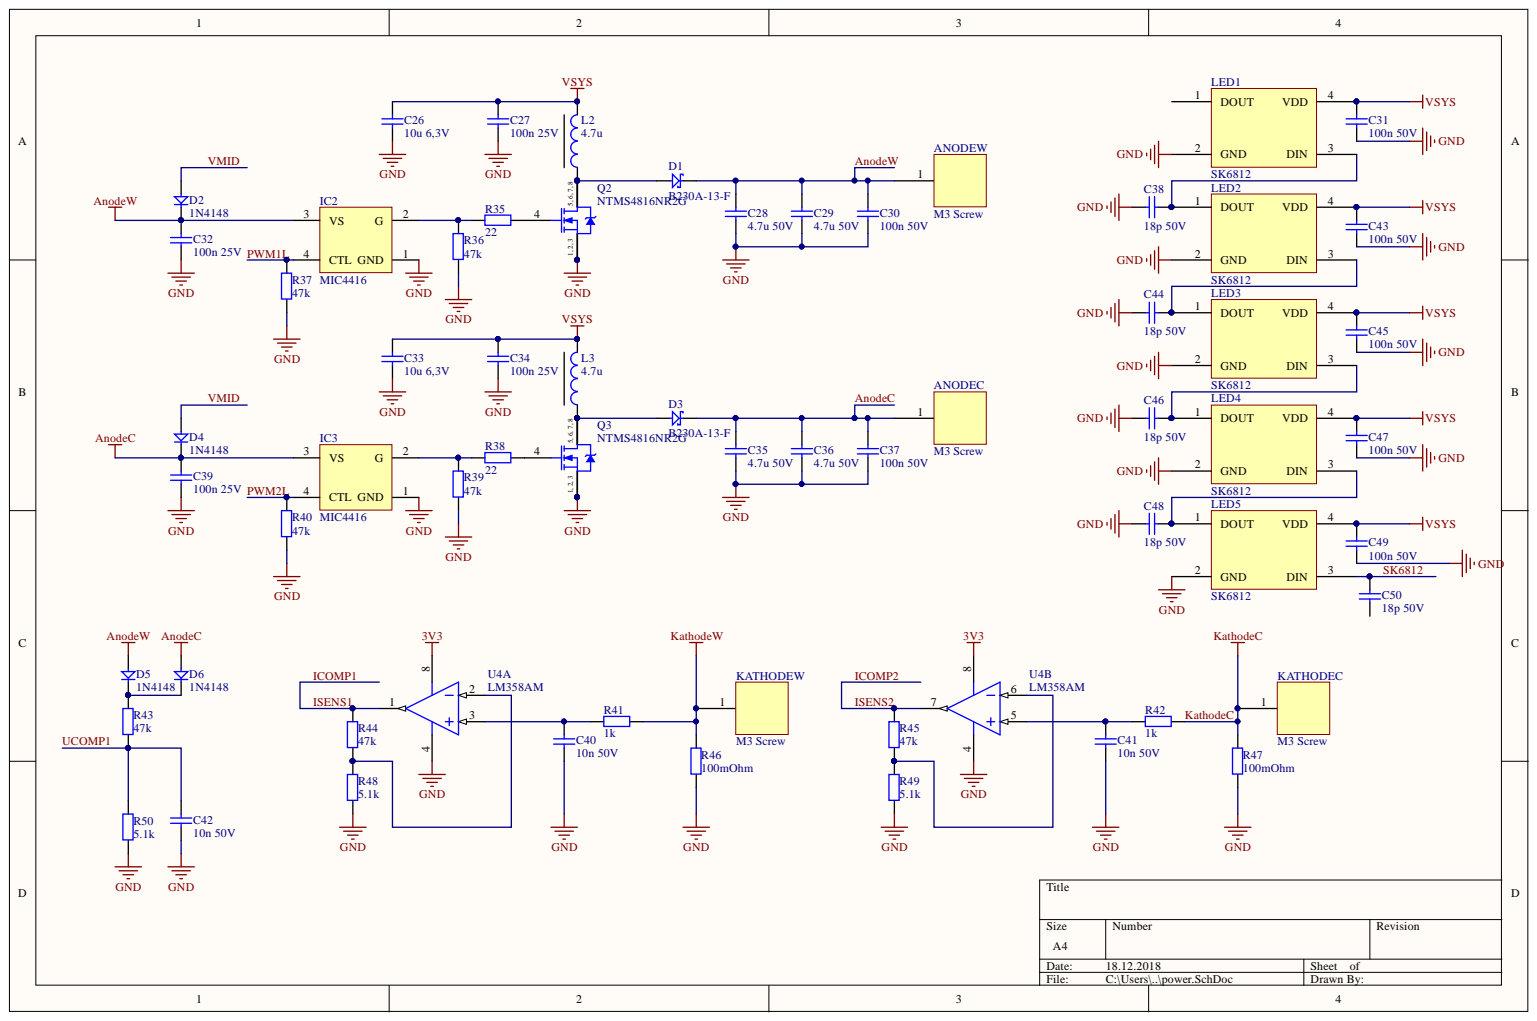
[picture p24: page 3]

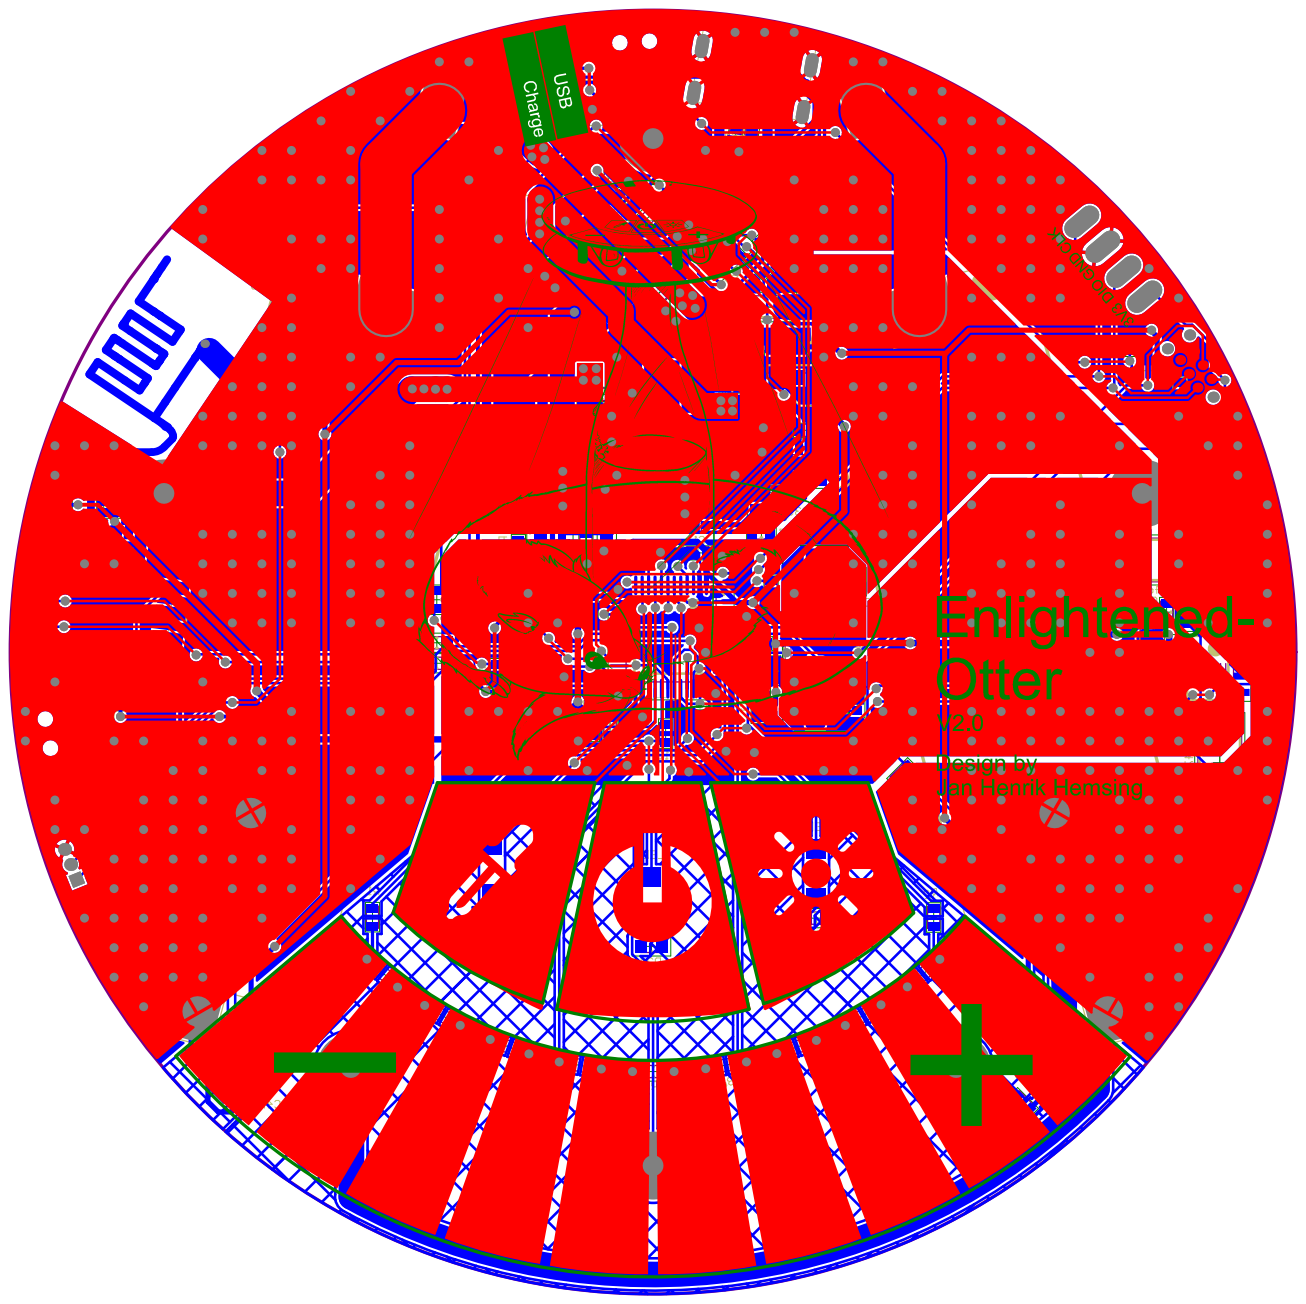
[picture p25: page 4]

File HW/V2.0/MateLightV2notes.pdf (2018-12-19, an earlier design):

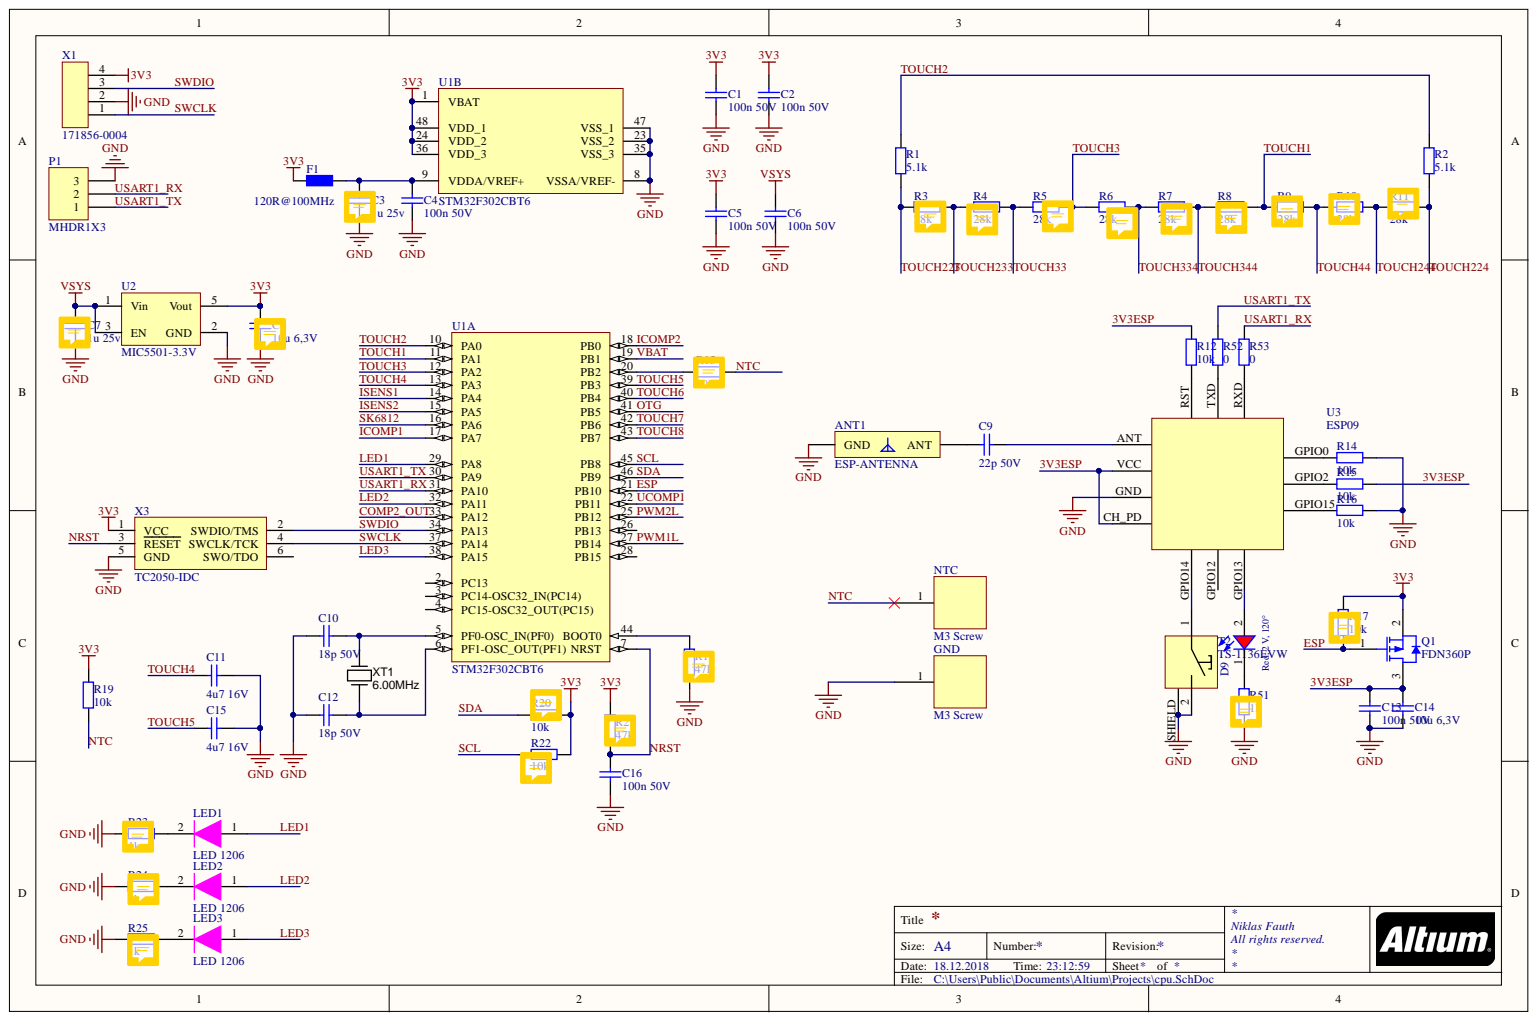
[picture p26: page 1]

2 VCC 1 GND

* Title | * Niklas Fauth All rights reserved. * *

Size: A4 | Number: * | Revision: *
Date: 18.12.2018 Time: 23:12:59 | | Sheet * of *

C:\Users\Public\Documents\Altium\Projects\cpu.SchDoc

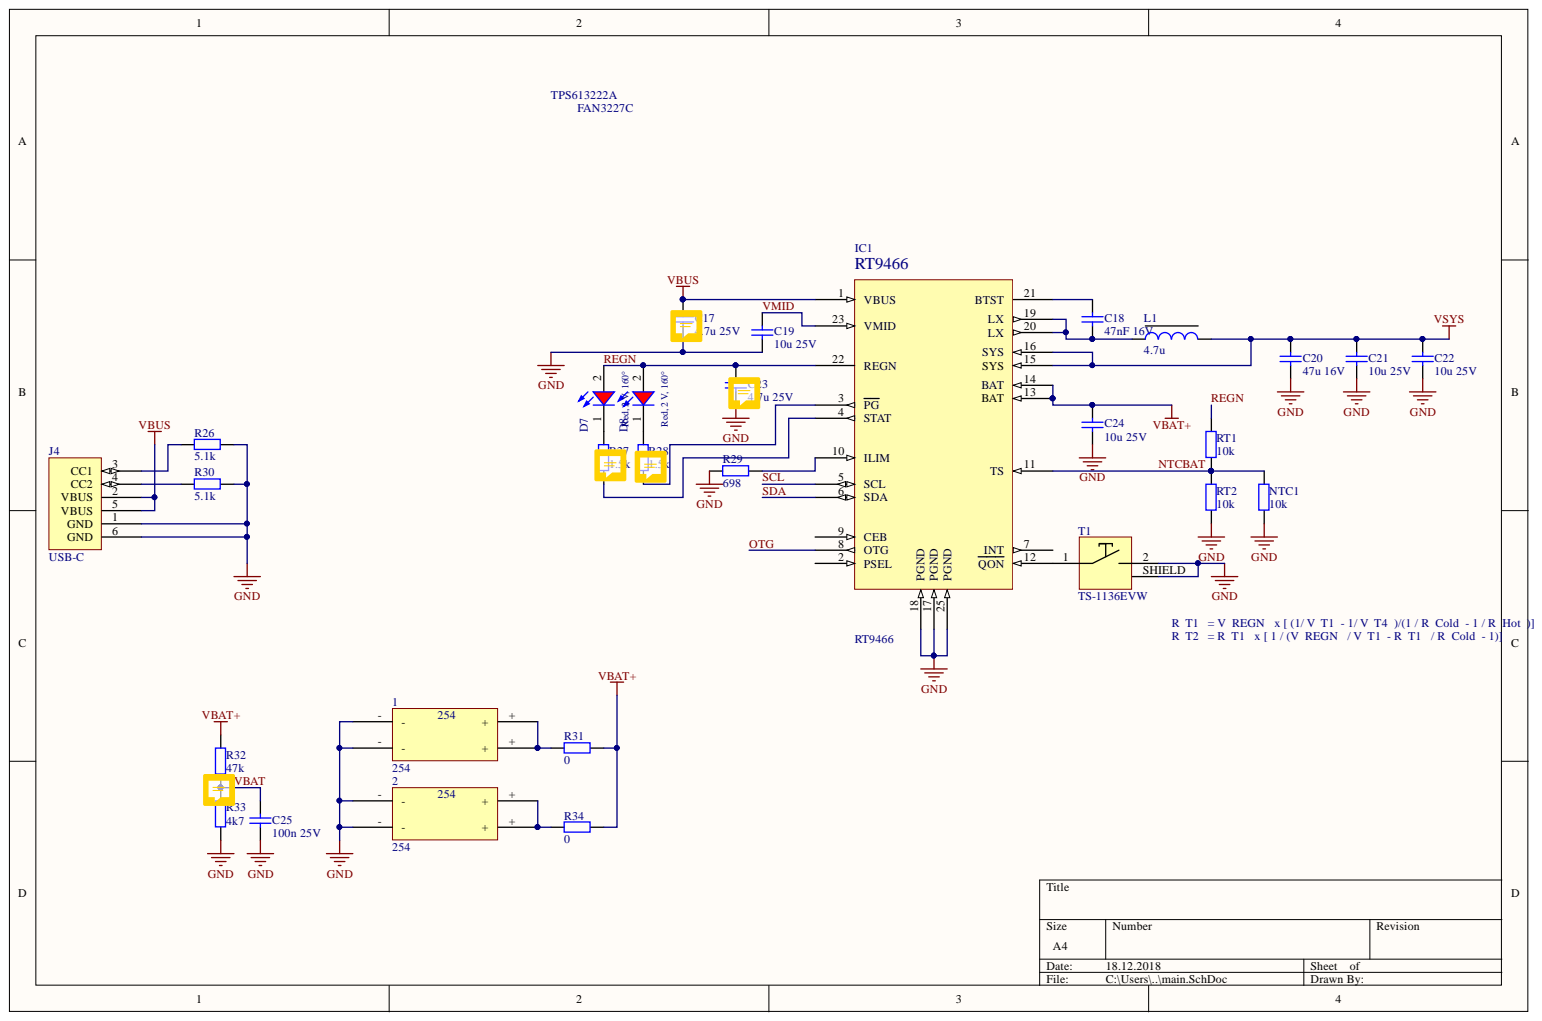
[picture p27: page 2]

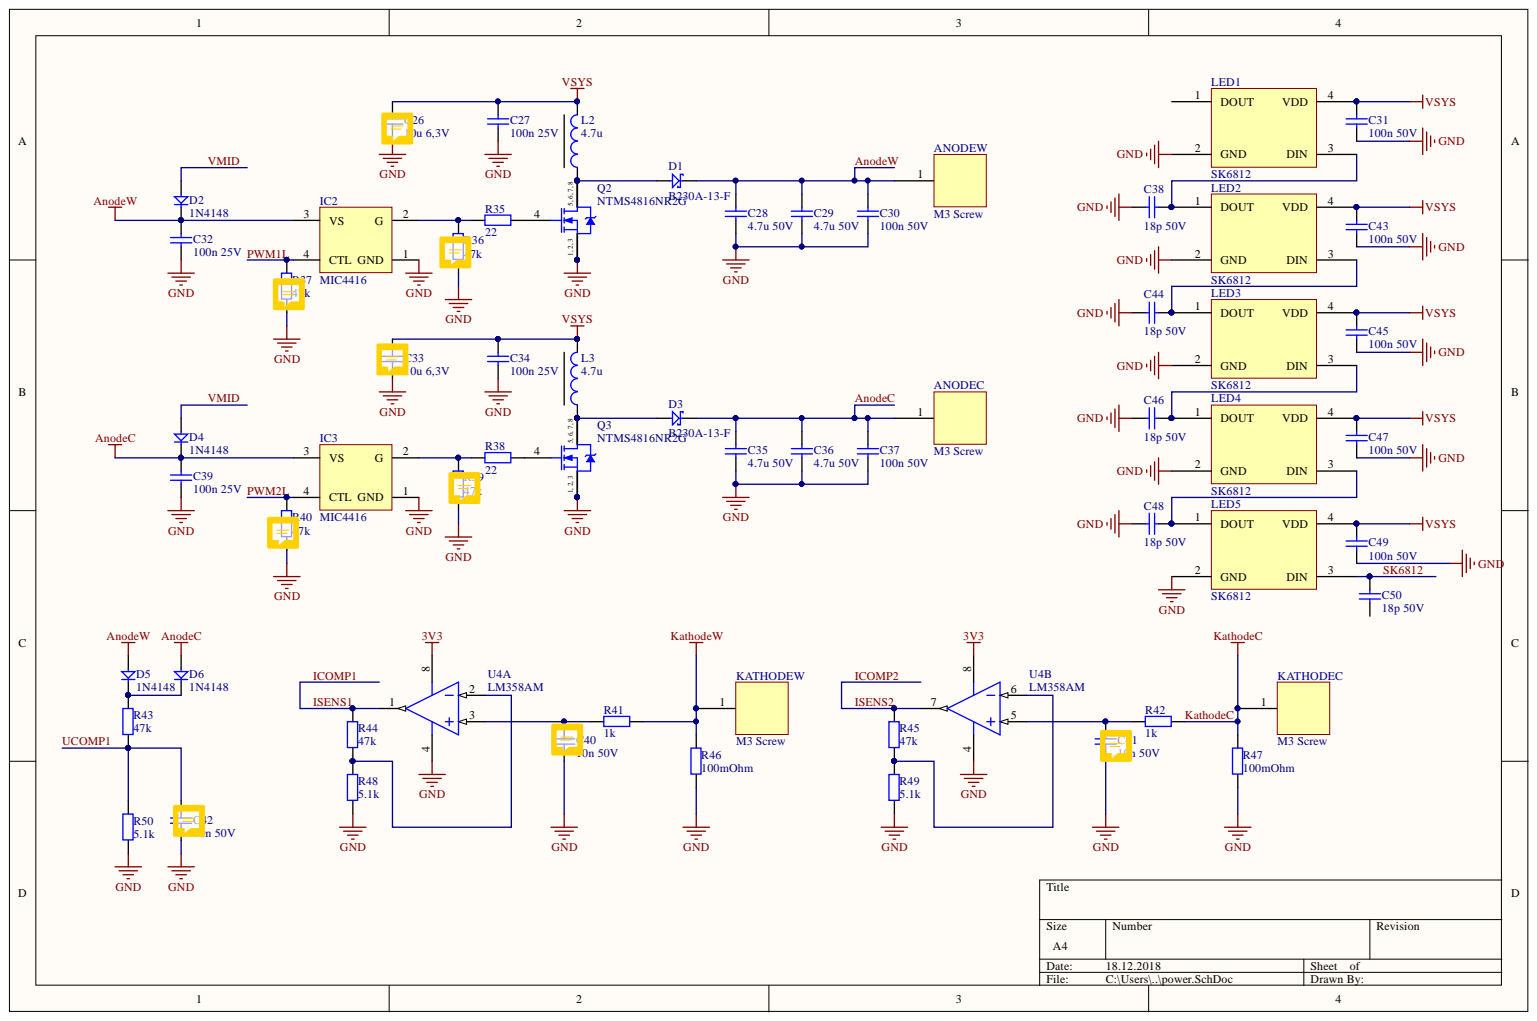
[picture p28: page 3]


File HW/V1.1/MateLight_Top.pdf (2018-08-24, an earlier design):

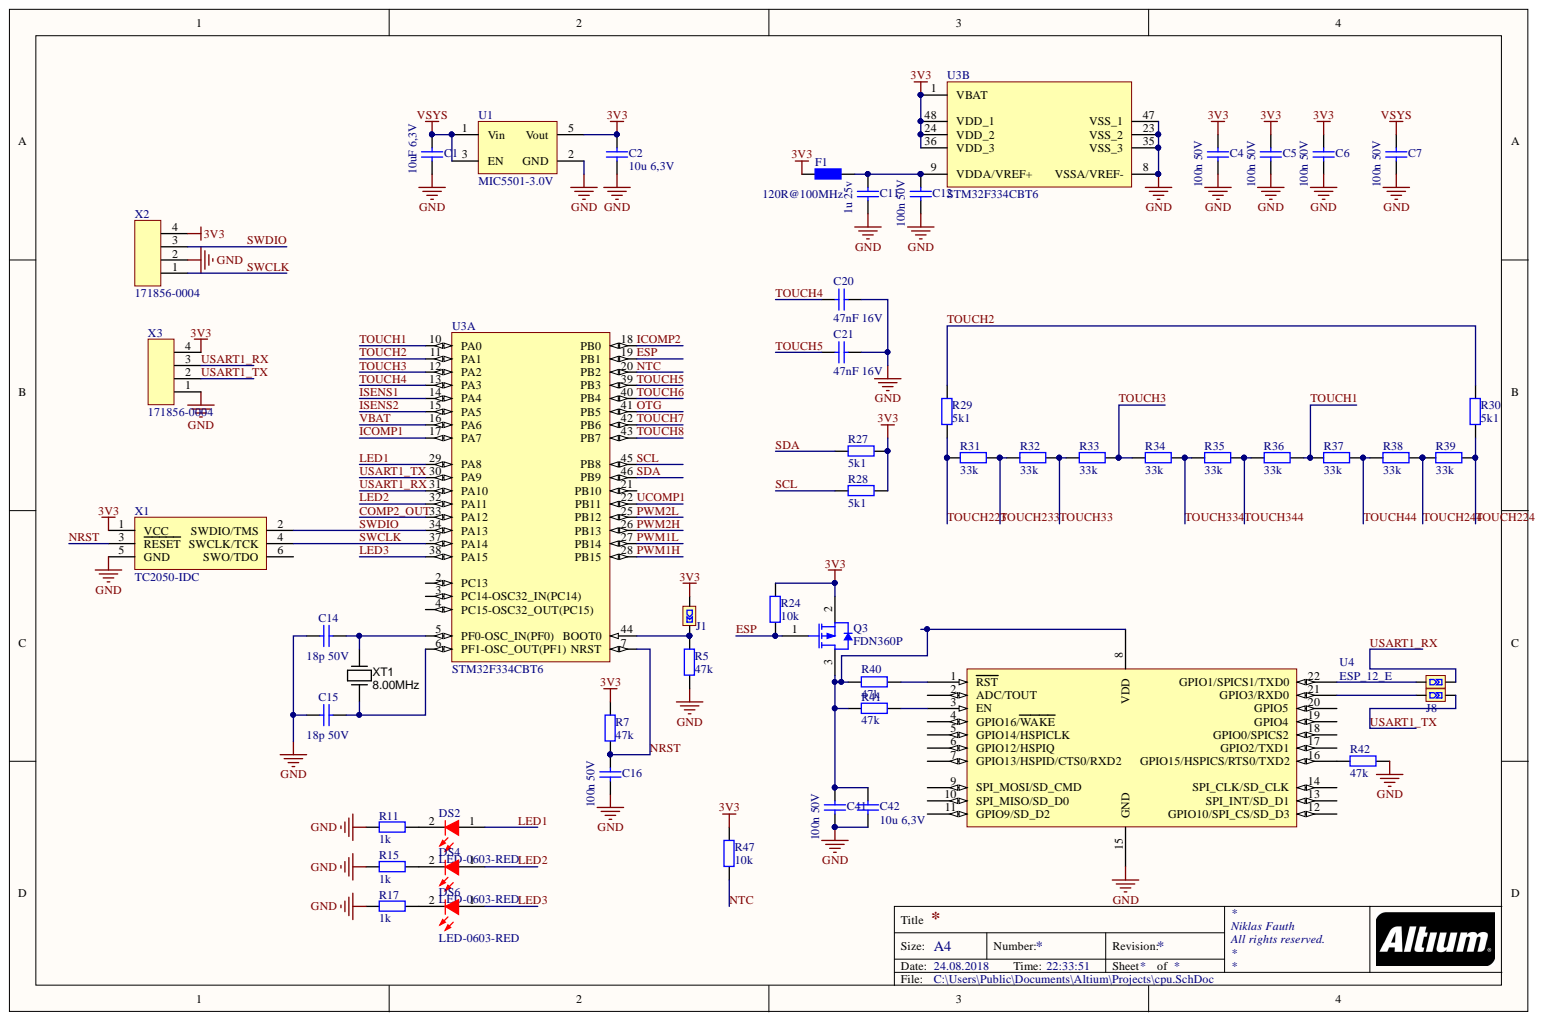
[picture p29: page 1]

R41 47k | ADC/TOUT 2 | J7

EN 3 | | USART1_TX

* Title | * Niklas Fauth All rights reserved. * *

Size: A4 | Number: * | Revision: *
Date: 24.08.2018 Time: 22:33:51 | | Sheet * of *

C:\Users\Public\Documents\Altium\Projects\cpu.SchDoc

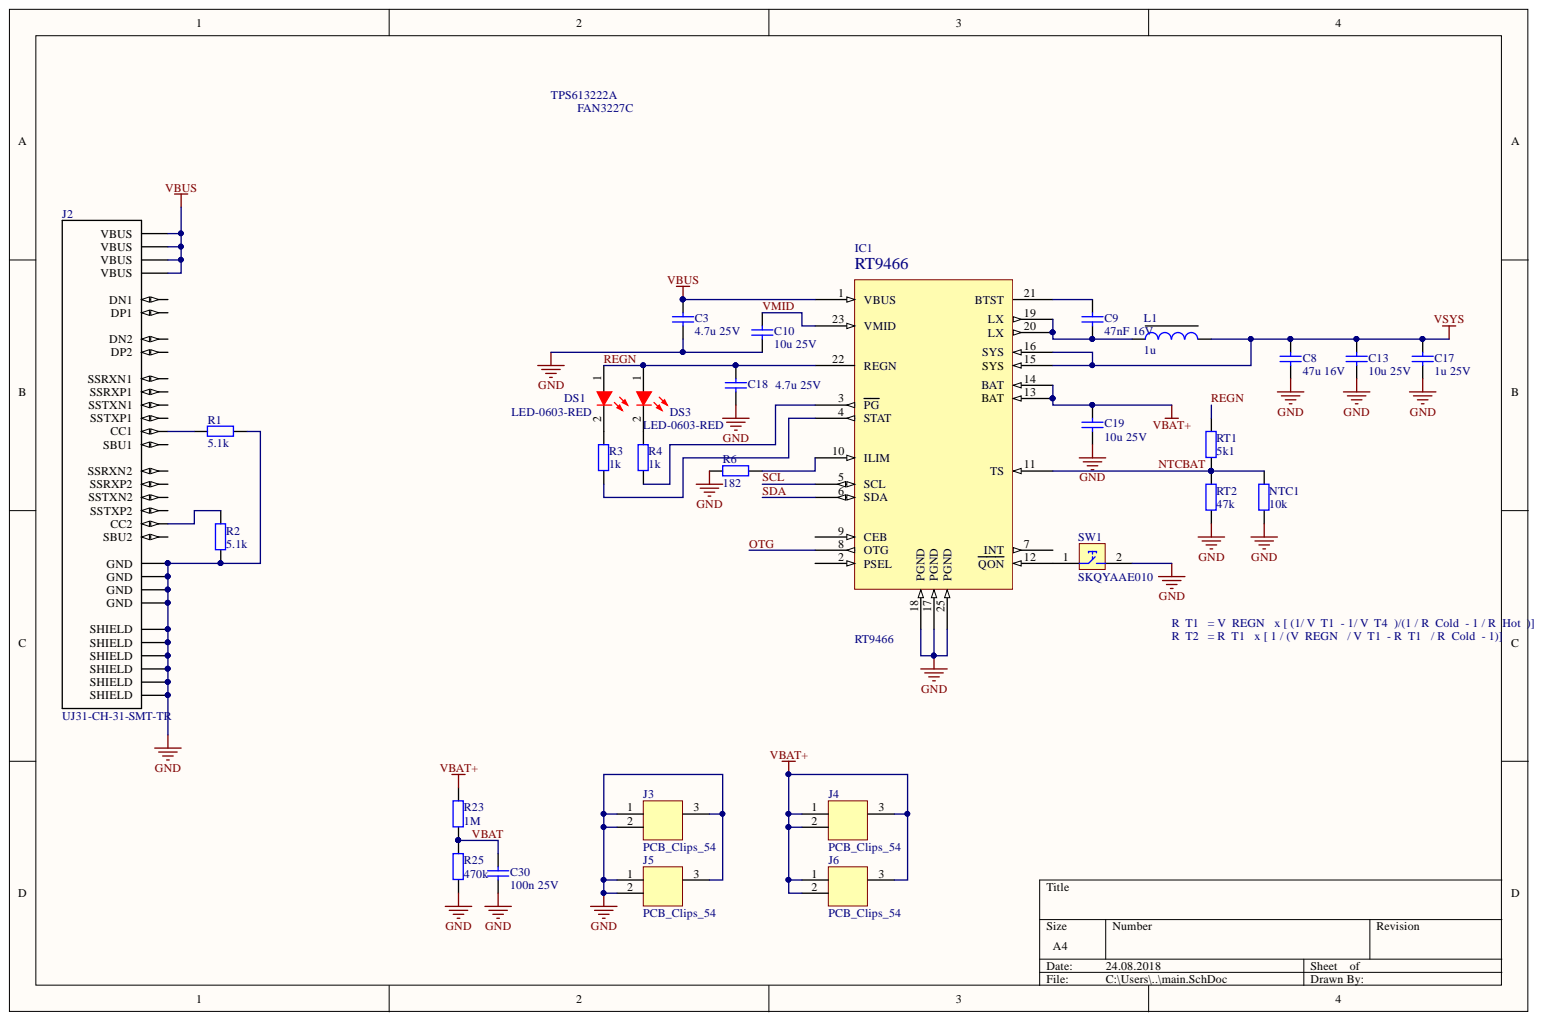
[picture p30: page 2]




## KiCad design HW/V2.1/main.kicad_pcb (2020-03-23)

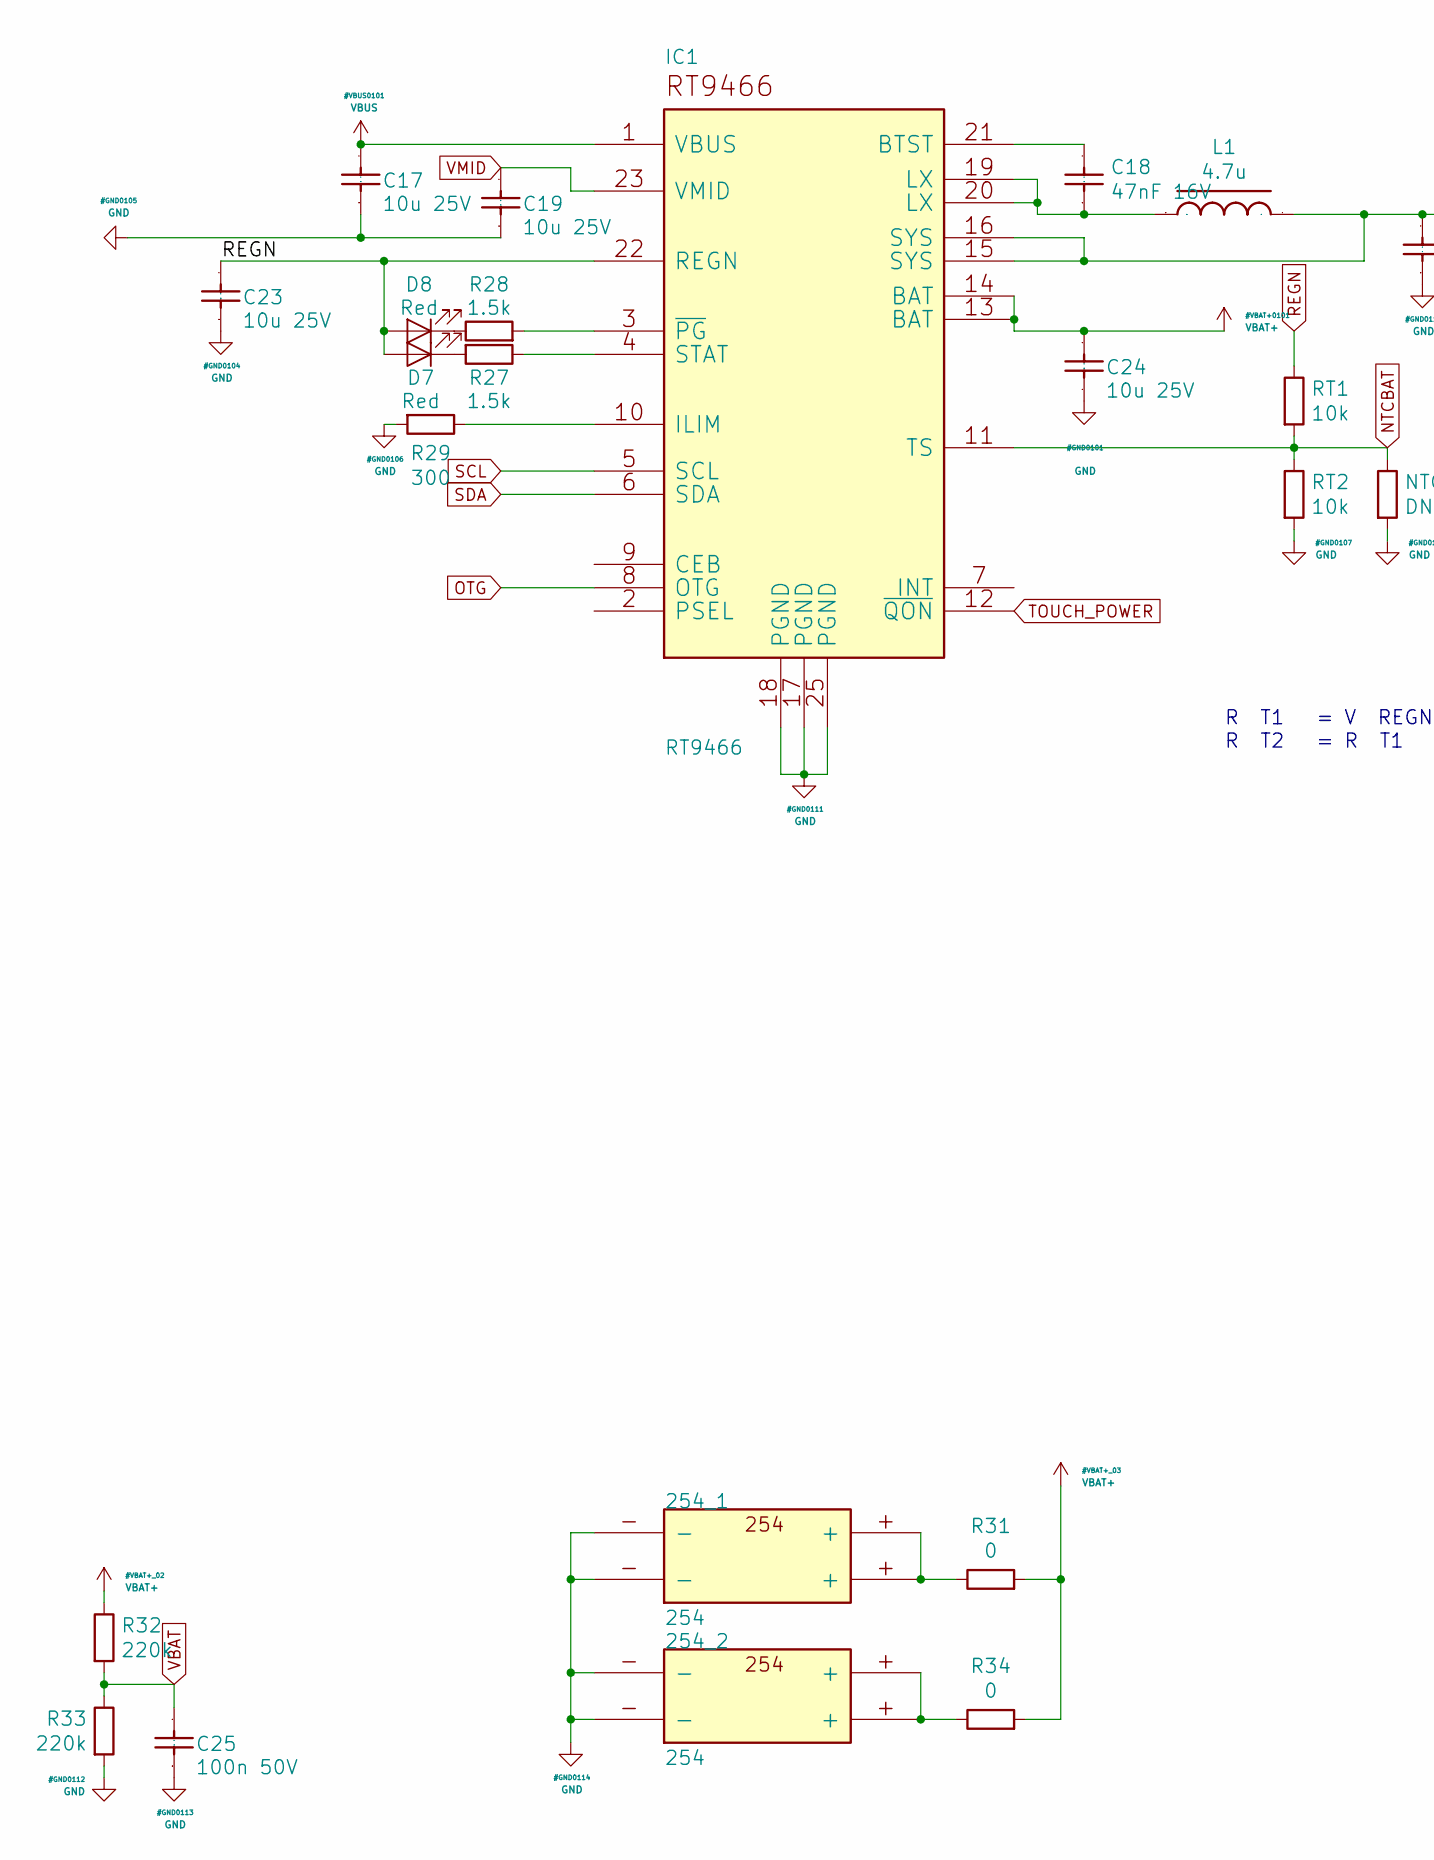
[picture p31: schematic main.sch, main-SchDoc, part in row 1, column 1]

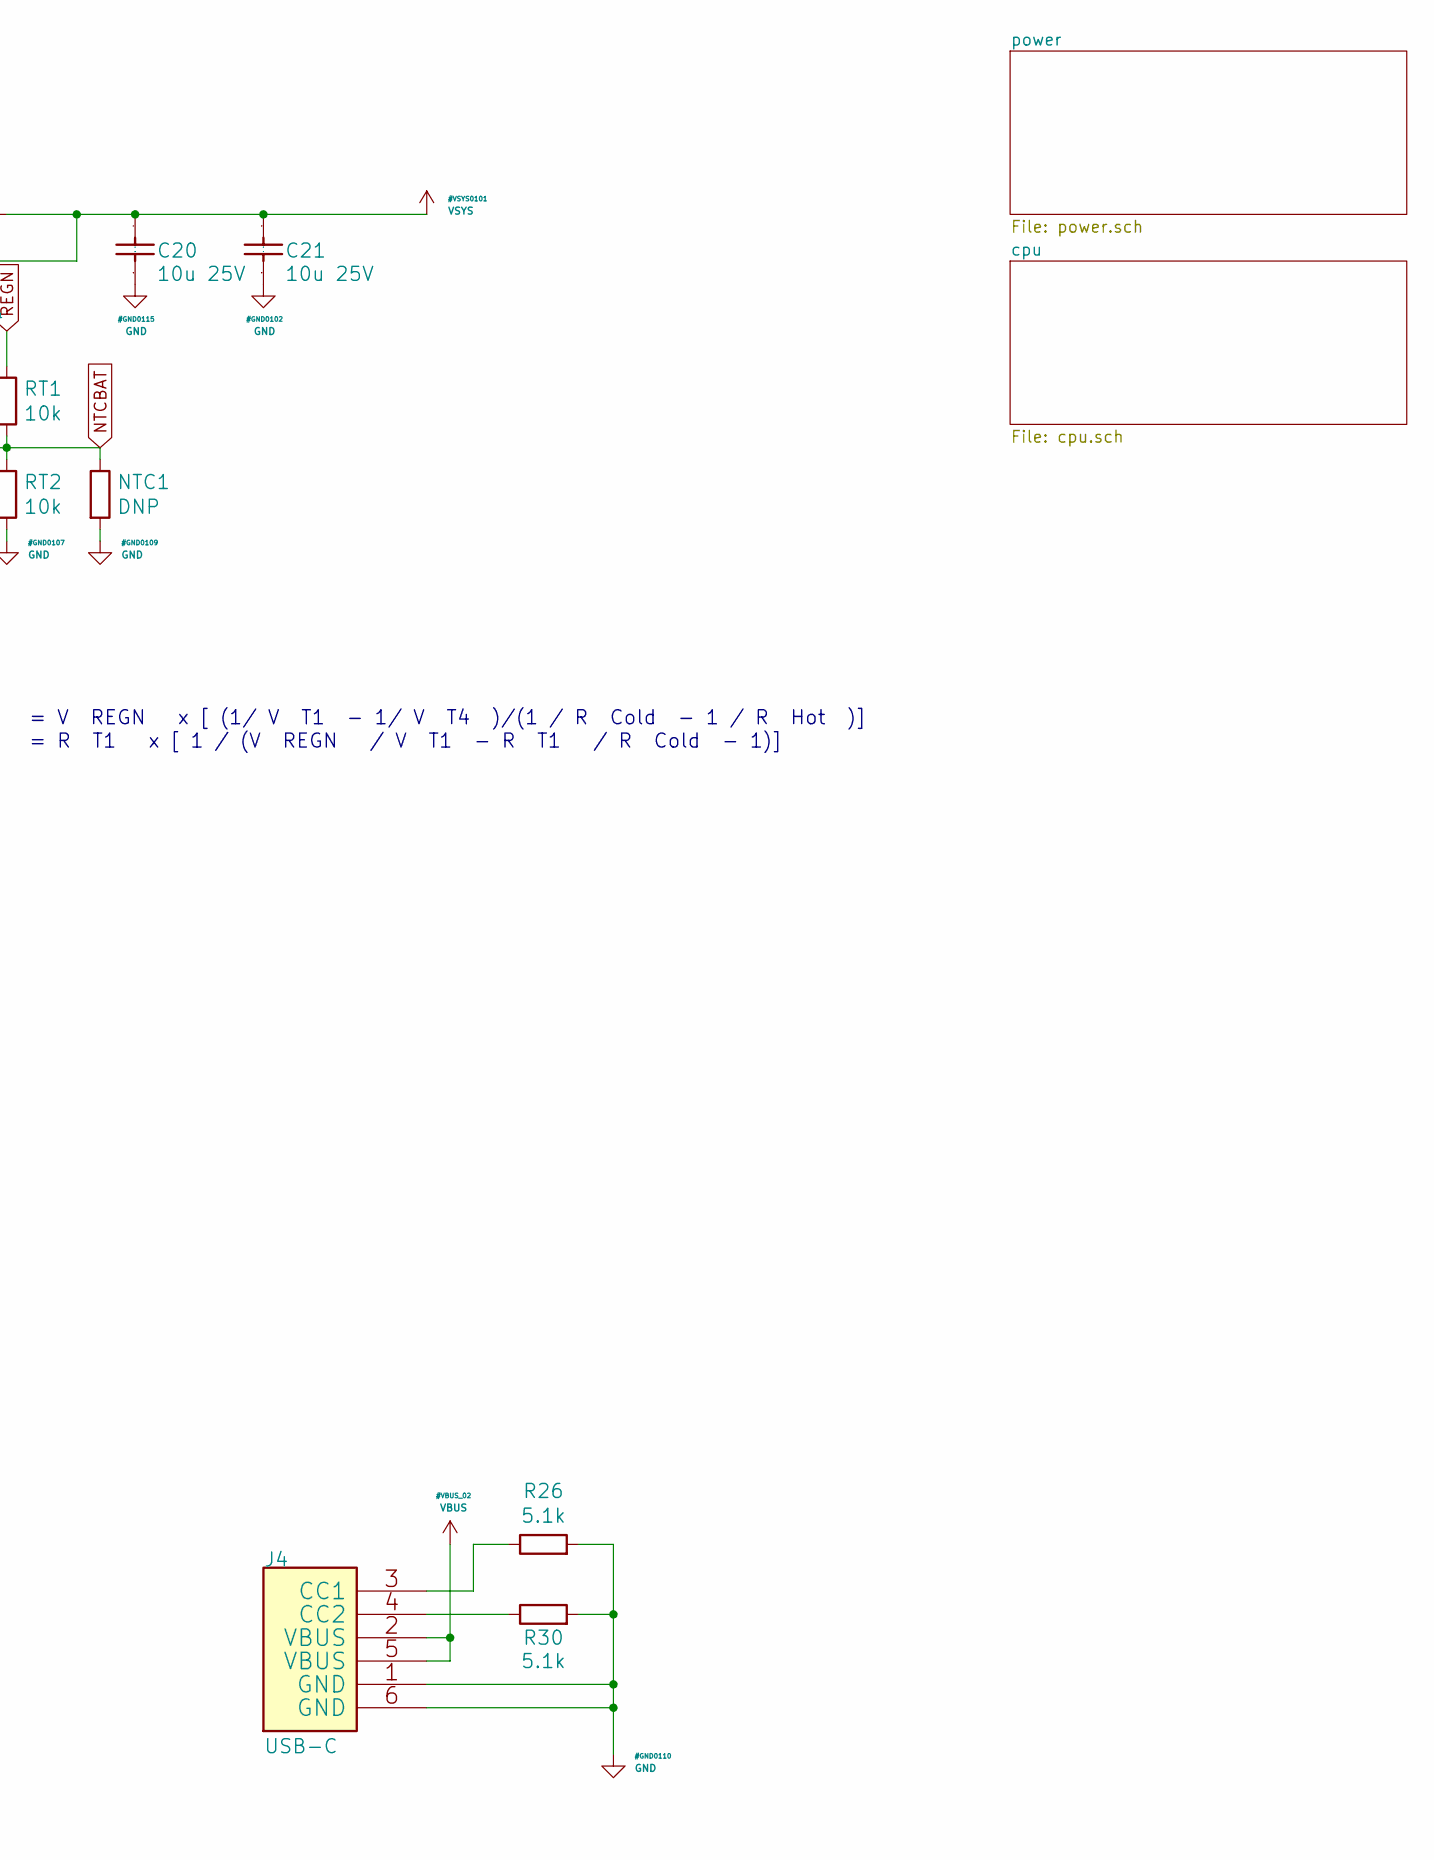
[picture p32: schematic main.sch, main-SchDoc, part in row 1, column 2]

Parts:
254_1, 254_2: 254
C17, C19, C20, C21, C23, C24: 10u 25V; C_0805_2012Metric
C18: 47nF 16V; C_0603_1608Metric
C25: 100n 50V; C_0603_1608Metric
D7, D8: Red; LED_Reverse
IC1: RT9466; QFN-24-1EP_4x4mm_P0.5mm_EP2.6x2.6mm
J4: USB-C; USB-C_Power
L1: 4.7u; L_Taiyo-Yuden_MD-4040
NTC1: DNP; R_0603_1608Metric
R26, R30: 5.1k; R_0603_1608Metric
R27, R28: 1.5k; R_0603_1608Metric
R29: 300; R_0603_1608Metric
R31, R34: 0; R_1206_3216Metric
R32, R33: 220k; R_0603_1608Metric
RT1, RT2: 10k; R_0603_1608Metric

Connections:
GND: 254_1.-, 254_2.-, C17.1, C19.1, C20.1, C21.1, C23.1, C24.1, C25.1, IC1.17 (PGND), IC1.18 (PGND), IC1.25 (PGND), J4.1 (GND), J4.6 (GND), NTC1.2, R26.2, R29.2, R30.2, R33.2, RT2.2; also elsewhere on the board
NTCBAT: IC1.11 (TS), NTC1.1, RT1.2, RT2.1
unnamed: 254_1.+, R31.1
unnamed: 254_2.+, R34.1
unnamed: C18.1, IC1.19 (LX), IC1.20 (LX), L1.1
unnamed: C18.2, IC1.21 (BTST)
unnamed: D7.1 (K), R27.2
unnamed: D8.1 (K), R28.1
unnamed: IC1.3 (~PG), R28.2
unnamed: IC1.4 (STAT), R27.1
unnamed: IC1.10 (ILIM), R29.1
unnamed: J4.3 (CC1), R26.1
unnamed: J4.4 (CC2), R30.1
OTG: IC1.8 (OTG); also elsewhere on the board
REGN: C23.2, D7.2 (A), D8.2 (A), IC1.22 (REGN), RT1.1
SCL: IC1.5 (SCL); also elsewhere on the board
SDA: IC1.6 (SDA); also elsewhere on the board
TOUCH_POWER: IC1.12 (~QON); also elsewhere on the board
VBAT: C25.2, R32.2, R33.1; also elsewhere on the board
VBAT+: C24.2, IC1.13 (BAT), IC1.14 (BAT), R31.2, R32.1, R34.2; also elsewhere on the board
VBUS: C17.2, IC1.1 (VBUS), J4.2 (VBUS), J4.5 (VBUS)
VMID: C19.2, IC1.23 (VMID); also elsewhere on the board
VSYS: C20.2, C21.2, IC1.15 (SYS), IC1.16 (SYS), L1.2; also elsewhere on the board

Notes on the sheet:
R T1 = V REGN x [ (1/ V T1 - 1/ V T4 )/(1 / R Cold - 1 / R Hot )]
R T2 = R T1 x [ 1 / (V REGN / V T1 - R T1 / R Cold - 1)]

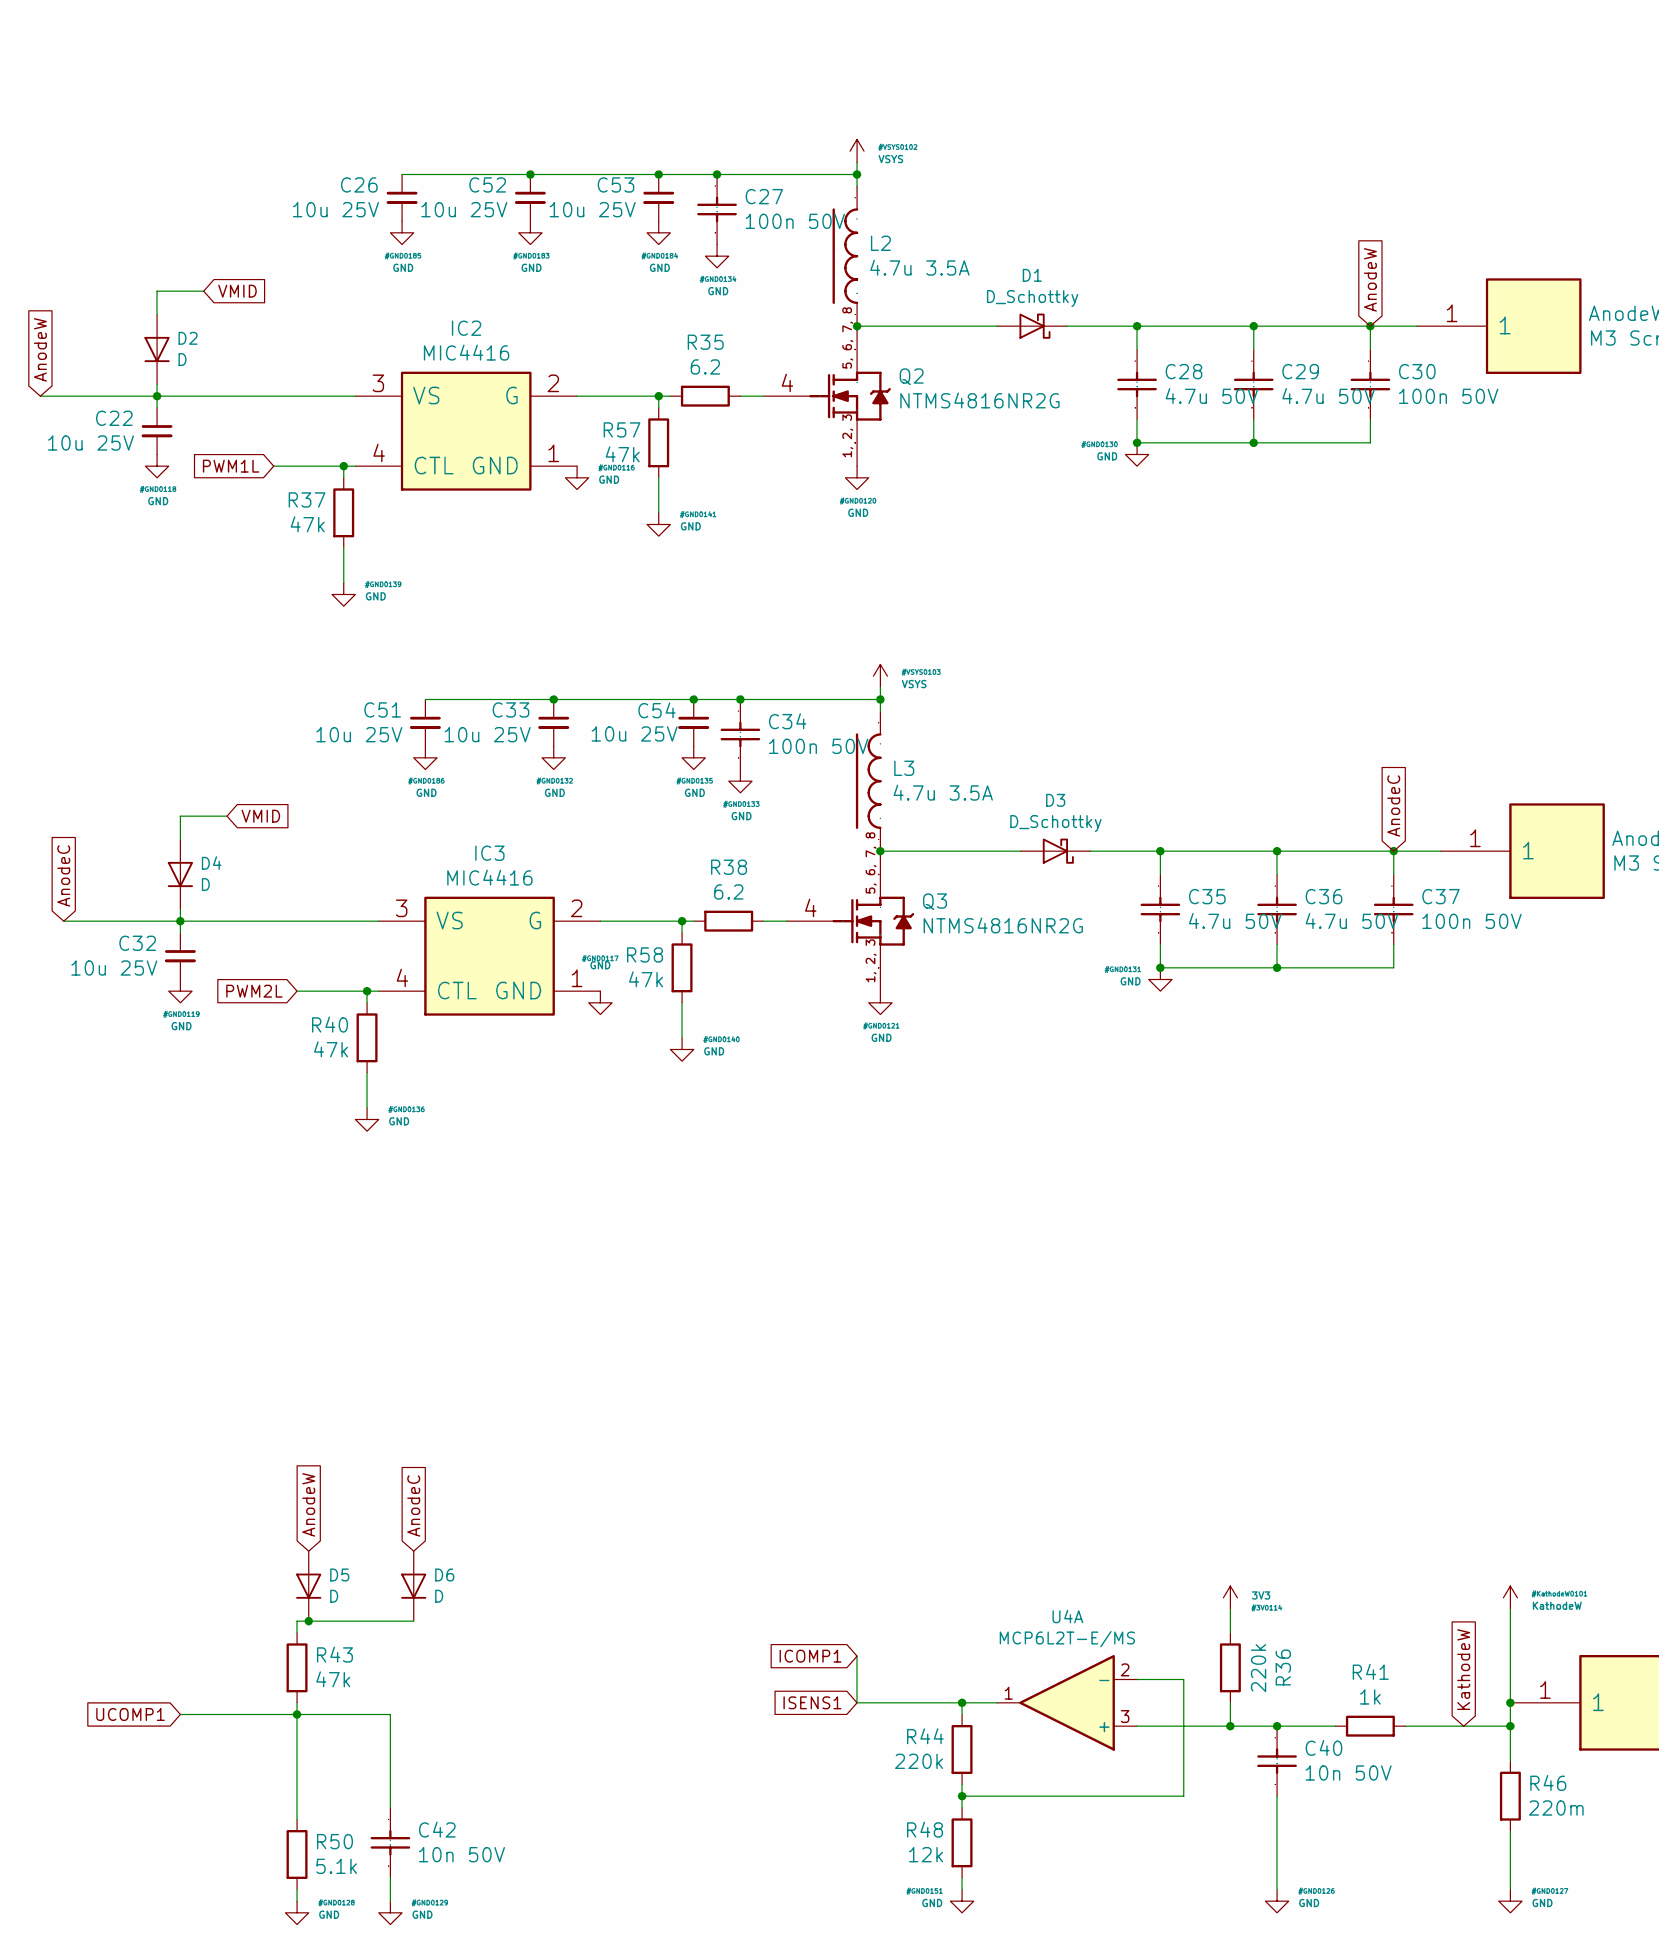
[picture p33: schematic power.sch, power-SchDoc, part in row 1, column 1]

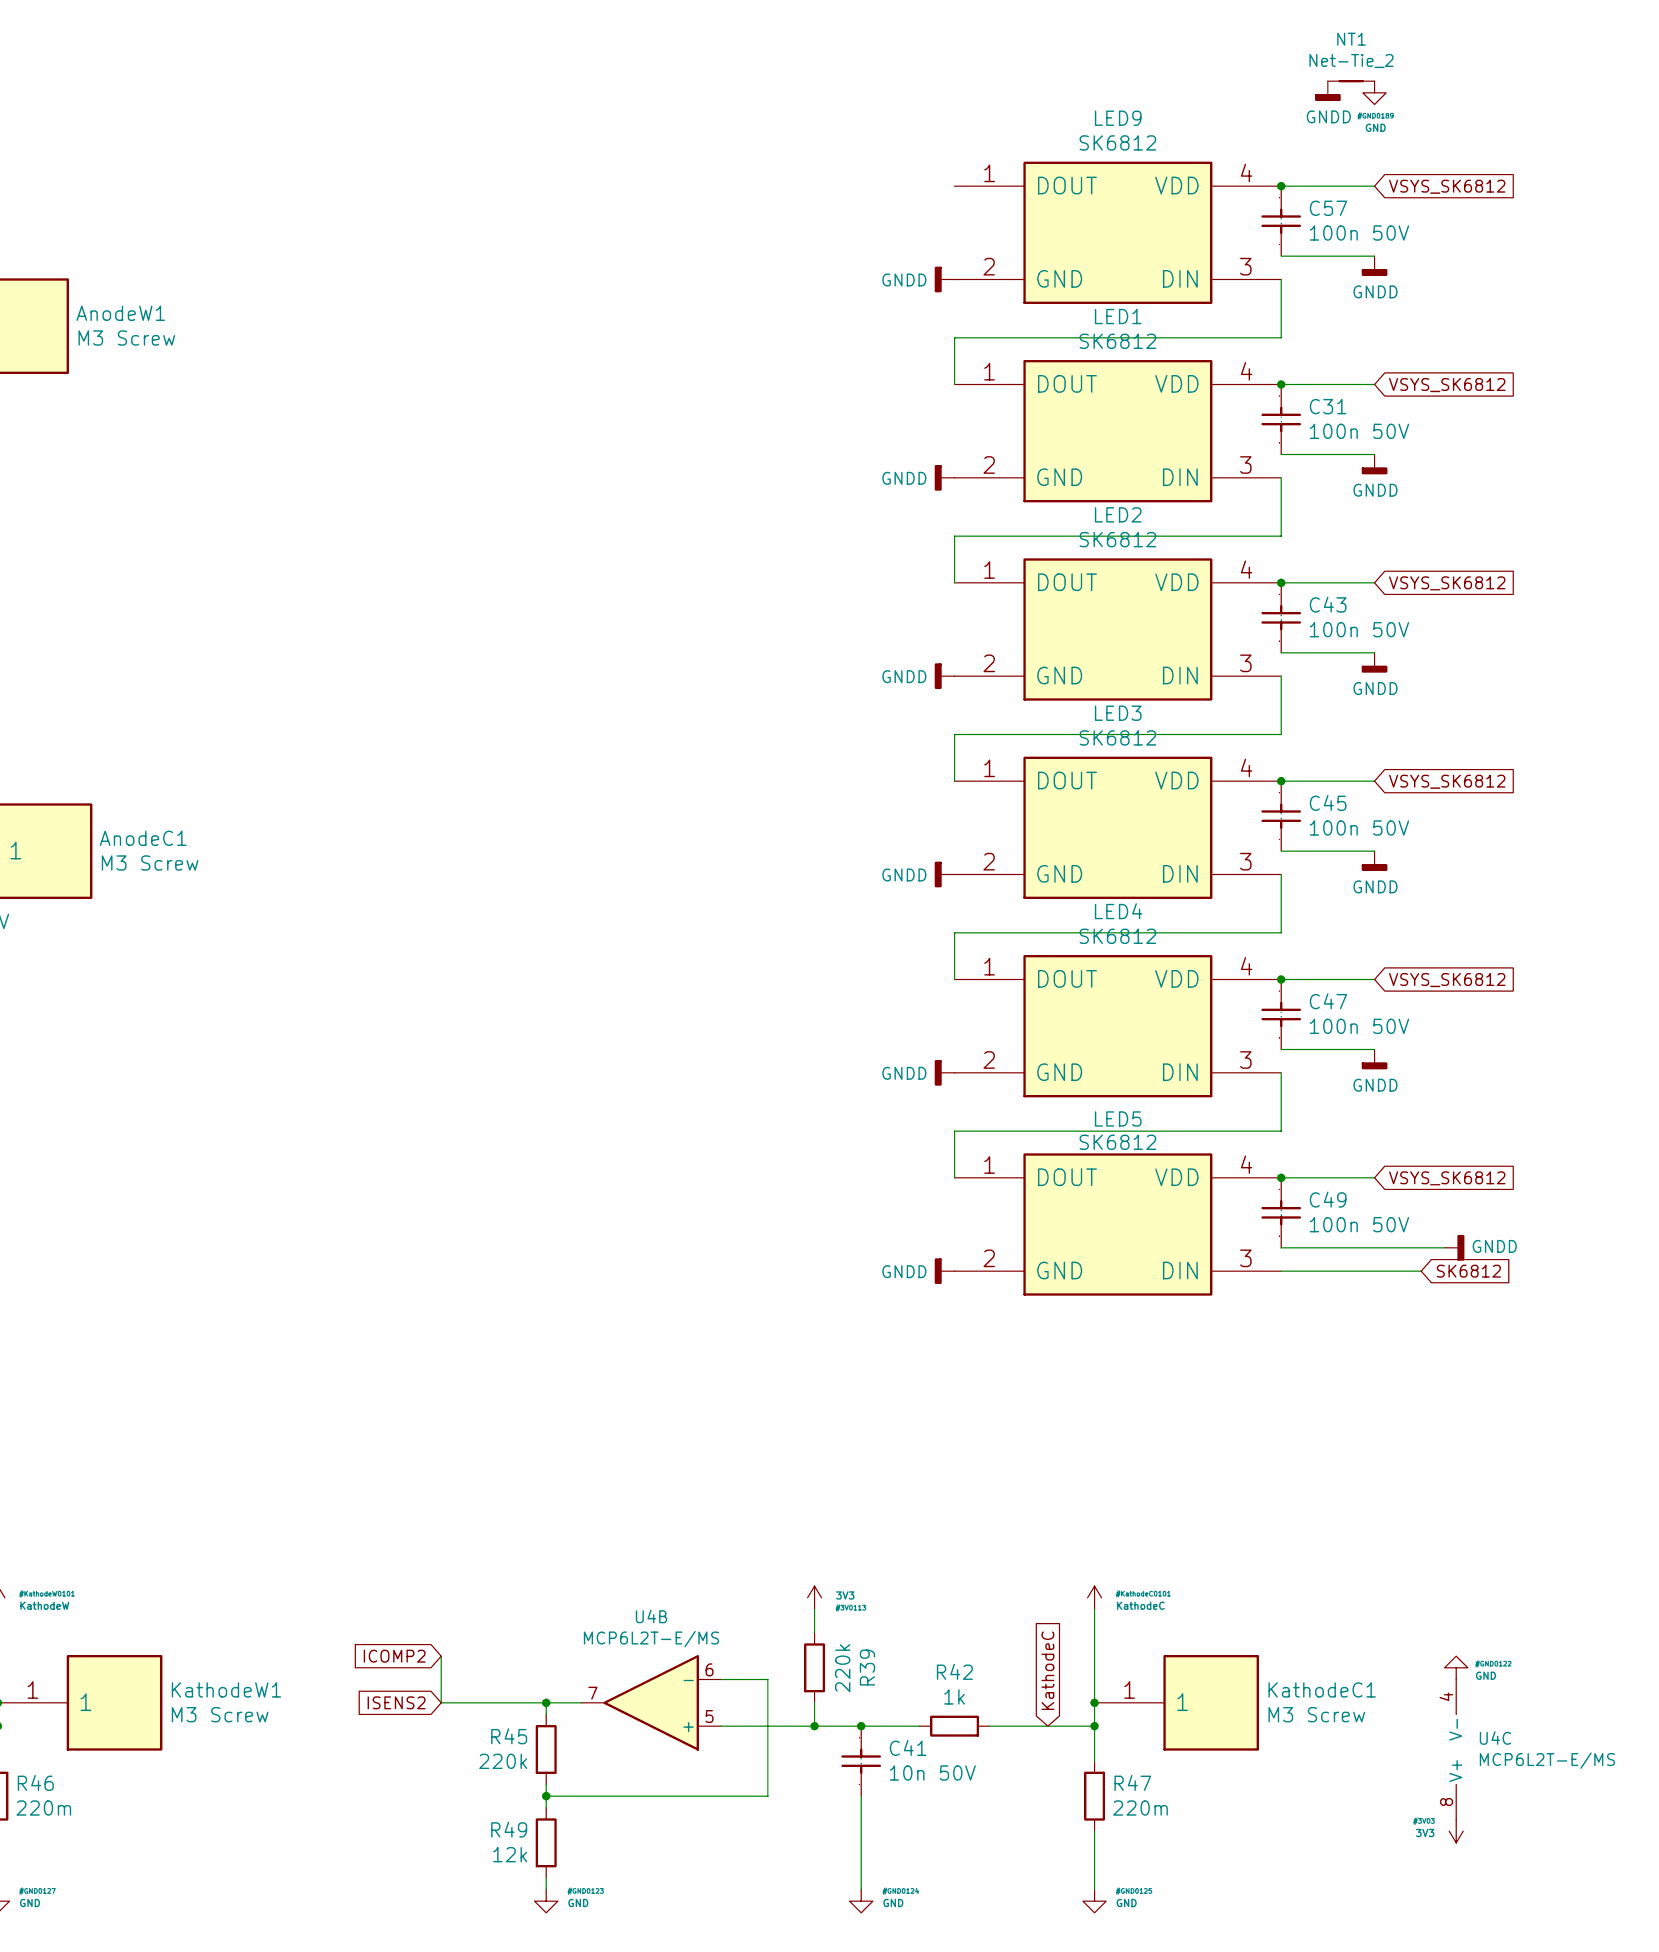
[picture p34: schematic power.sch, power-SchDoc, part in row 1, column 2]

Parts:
AnodeC1: M3 Screw; M3_Screw
AnodeW1: M3 Screw; M3_Screw
C22, C26, C32, C33, C51, C52, C53, C54: 10u 25V; C_0805_2012Metric
C27, C30, C31, C34, C37, C43, C45, C47, C49, C57: 100n 50V; C_0603_1608Metric
C28, C29, C35, C36: 4.7u 50V; C_1206_3216Metric
C40, C41, C42: 10n 50V; C_0603_1608Metric
D1, D3: D_Schottky; D_SMA
D2, D4, D5, D6: D; D_SOD-123F
IC2, IC3: MIC4416; SOT-143
KathodeC1: M3 Screw; M3_Screw
KathodeW1: M3 Screw; M3_Screw
L2, L3: 4.7u 3.5A; L_Taiyo-Yuden_MD-4040
LED1, LED2, LED3, LED4, LED5, LED9: SK6812; sk6812mini
NT1: Net-Tie_2; NetTie-2_SMD_Pad0.5mm
Q2, Q3: NTMS4816NR2G; SO-8_3.9x4.9mm_P1.27mm
R35, R38: 6.2; R_0603_1608Metric
R36, R39, R44, R45: 220k; R_0603_1608Metric
R37, R40, R43, R57, R58: 47k; R_0603_1608Metric
R41, R42: 1k; R_0603_1608Metric
R46, R47: 220m; R_0603_1608Metric
R48, R49: 12k; R_0603_1608Metric
R50: 5.1k; R_0603_1608Metric
U4: MCP6L2T-E/MS; MSOP-8_3x3mm_P0.65mm

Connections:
3V3: R36.1, R39.1, U4.8 (V+); also elsewhere on the board
AnodeC: AnodeC1.1, C32.1, C35.2, C36.2, C37.2, D3.1 (K), D4.1 (K), D6.2 (A), IC3.3 (VS)
AnodeW: AnodeW1.1, C22.1, C28.2, C29.2, C30.2, D1.1 (K), D2.1 (K), D5.2 (A), IC2.3 (VS)
GND: C22.2, C26.2, C27.1, C28.1, C29.1, C30.1, C32.2, C33.2, C34.1, C35.1, C36.1, C37.1, C40.1, C41.1, C42.1, C51.2, C52.2, C53.2, C54.2, IC2.1 (GND), IC3.1 (GND), NT1.2, Q2.1 (S), Q2.2 (S), Q2.3 (S), Q3.1 (S), Q3.2 (S), Q3.3 (S), R37.2, R40.2, R46.2, R47.1, R48.2, R49.2, R50.2, R57.2, R58.2, U4.4 (V-); also elsewhere on the board
GNDD: C31.1, C43.1, C45.1, C47.1, C49.1, C57.1, LED1.2 (GND), LED2.2 (GND), LED3.2 (GND), LED4.2 (GND), LED5.2 (GND), LED9.2 (GND), NT1.1
ICOMP1: R44.1, U4.1; also elsewhere on the board
ICOMP2: R45.1, U4.7; also elsewhere on the board
KathodeC: KathodeC1.1, R42.2, R47.2
KathodeW: KathodeW1.1, R41.2, R46.1
unnamed: C40.2, R36.2, R41.1, U4.3 (+)
unnamed: C41.2, R39.2, R42.1, U4.5 (+)
unnamed: D1.2 (A), L2.1, Q2.5 (D), Q2.6 (D), Q2.7 (D), Q2.8 (D)
unnamed: D3.2 (A), L3.1, Q3.5 (D), Q3.6 (D), Q3.7 (D), Q3.8 (D)
unnamed: D5.1 (K), D6.1 (K), R43.1
unnamed: IC2.2 (G), R35.2, R57.1
unnamed: IC3.2 (G), R38.2, R58.1
unnamed: LED1.1 (DOUT), LED9.3 (DIN)
unnamed: LED1.3 (DIN), LED2.1 (DOUT)
unnamed: LED2.3 (DIN), LED3.1 (DOUT)
unnamed: LED3.3 (DIN), LED4.1 (DOUT)
unnamed: LED4.3 (DIN), LED5.1 (DOUT)
unnamed: Q2.4 (G), R35.1
unnamed: Q3.4 (G), R38.1
unnamed: R44.2, R48.1, U4.2 (-)
unnamed: R45.2, R49.1, U4.6 (-)
PWM1L: IC2.4 (CTL), R37.1; also elsewhere on the board
PWM2L: IC3.4 (CTL), R40.1; also elsewhere on the board
SK6812: LED5.3 (DIN); also elsewhere on the board
UCOMP1: C42.2, R43.2, R50.1; also elsewhere on the board
VMID: D2.2 (A), D4.2 (A); also elsewhere on the board
VSYS: C26.1, C27.2, C33.1, C34.2, C51.1, C52.1, C53.1, C54.1, L2.2, L3.2; also elsewhere on the board
VSYS_SK6812: C31.2, C43.2, C45.2, C47.2, C49.2, C57.2, LED1.4 (VDD), LED2.4 (VDD), LED3.4 (VDD), LED4.4 (VDD), LED5.4 (VDD), LED9.4 (VDD); also elsewhere on the board

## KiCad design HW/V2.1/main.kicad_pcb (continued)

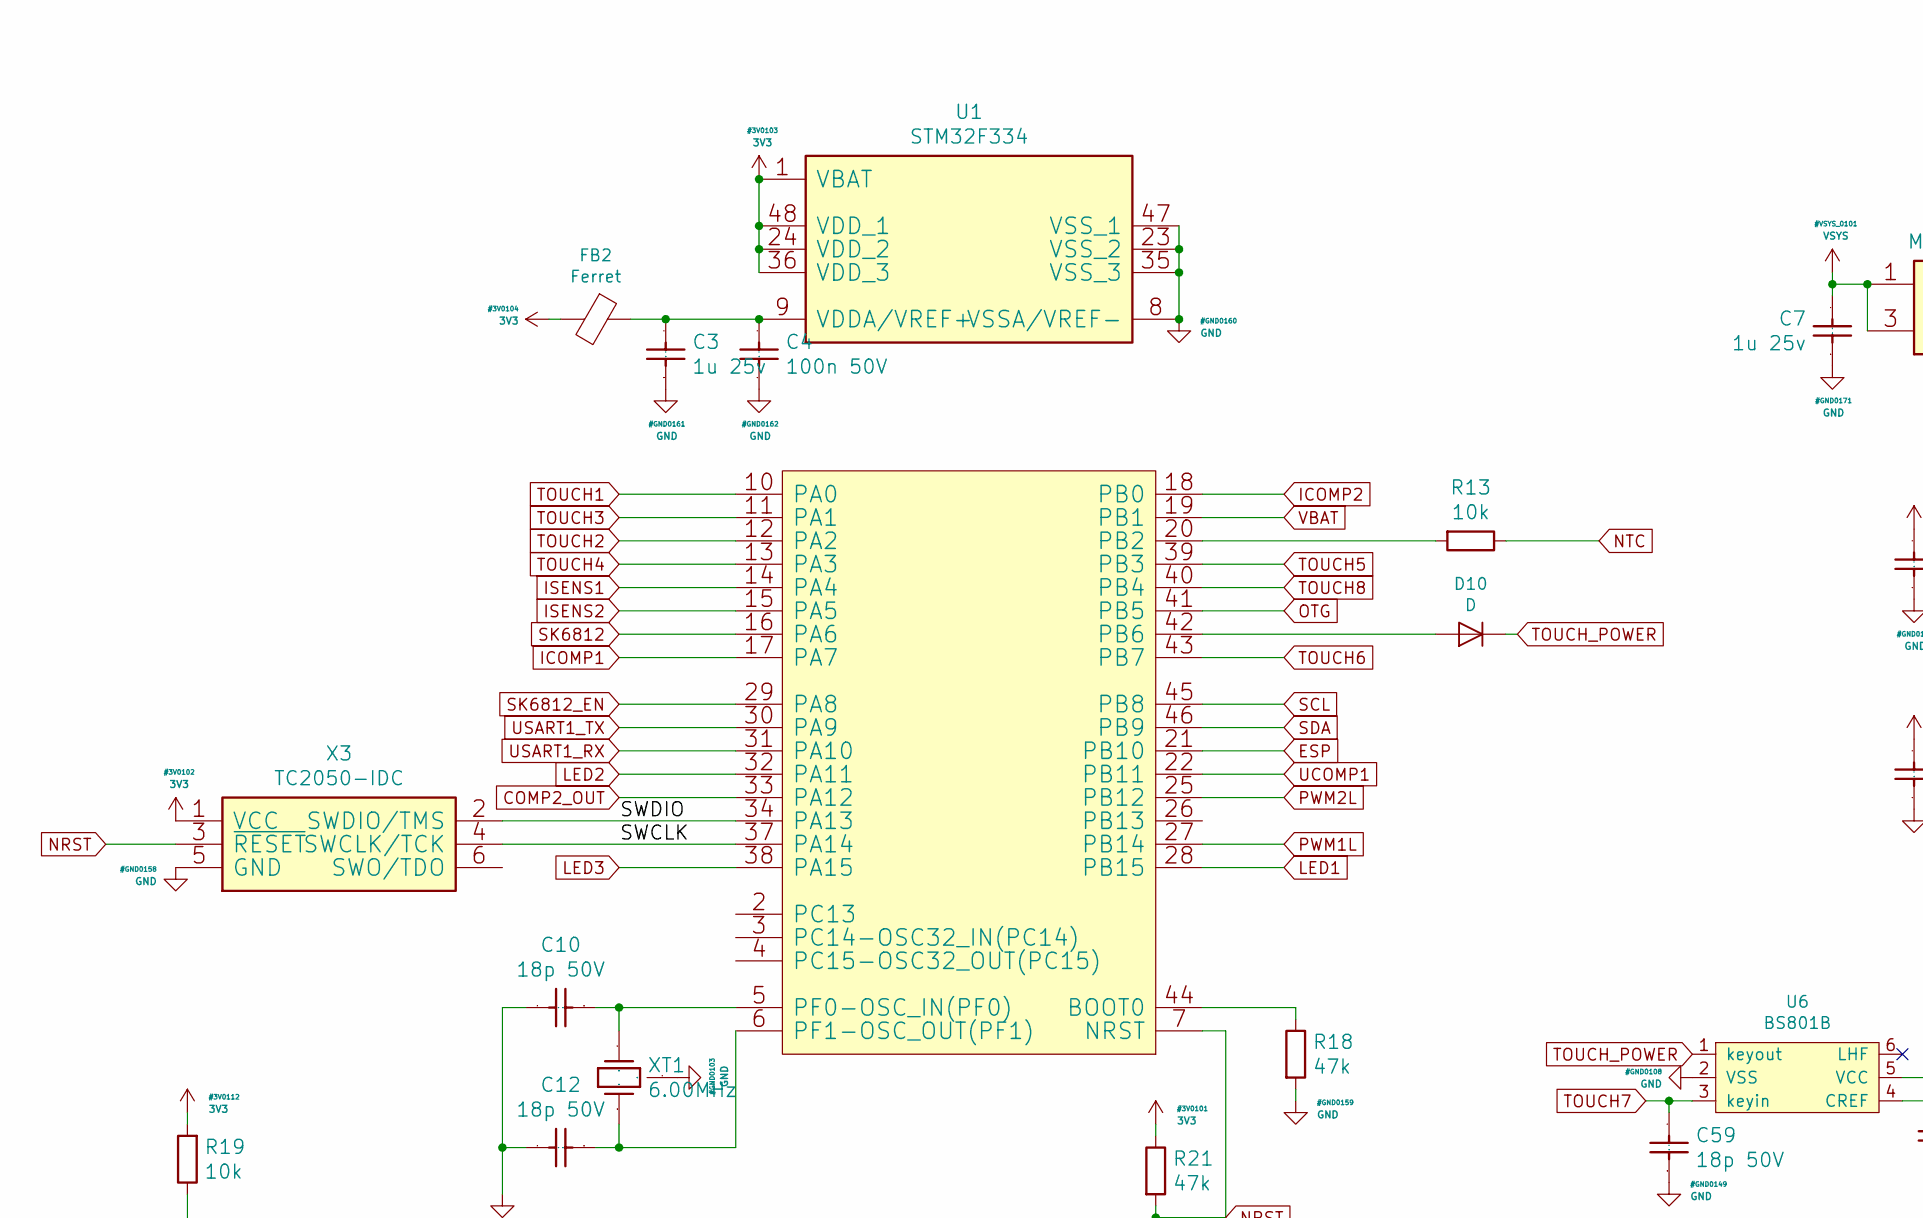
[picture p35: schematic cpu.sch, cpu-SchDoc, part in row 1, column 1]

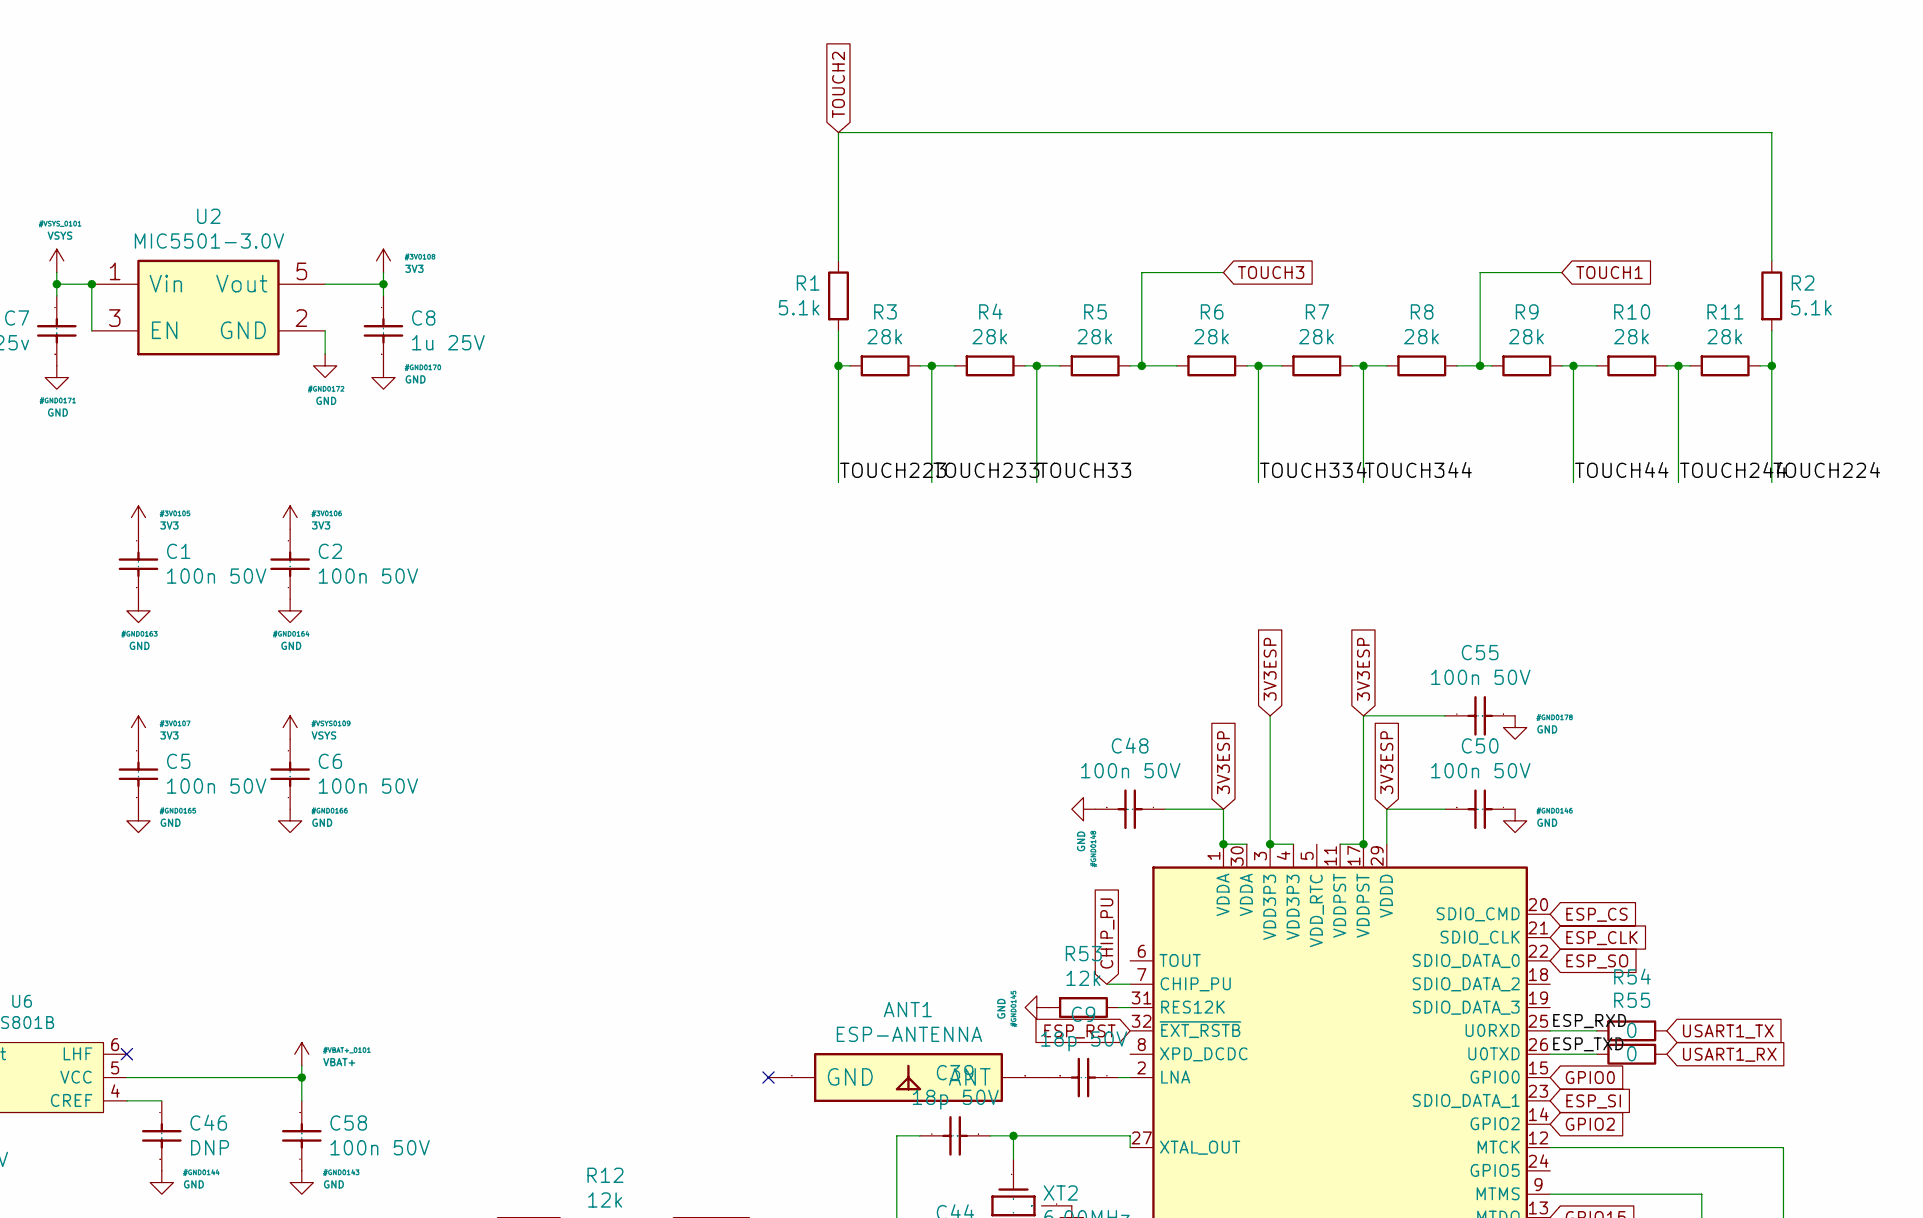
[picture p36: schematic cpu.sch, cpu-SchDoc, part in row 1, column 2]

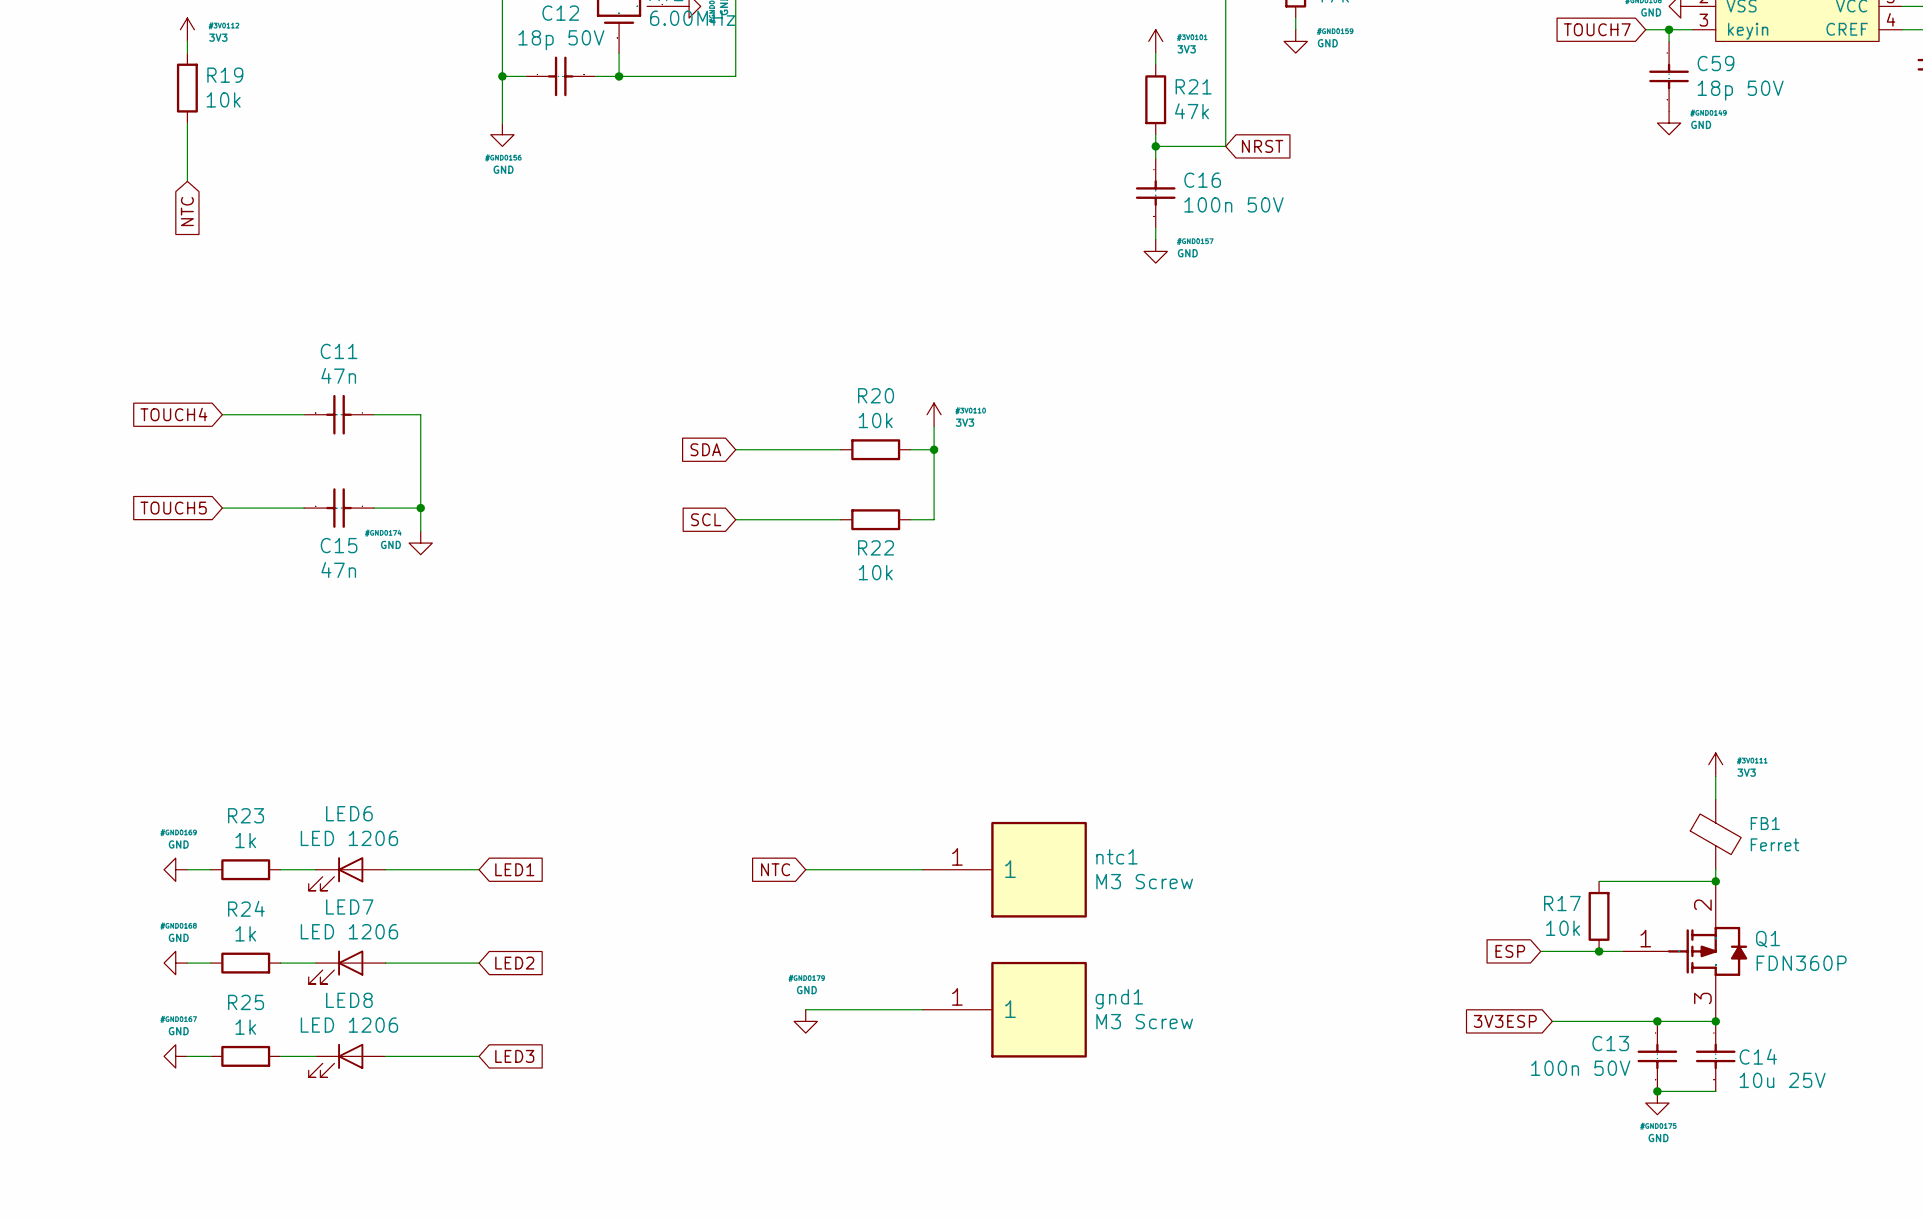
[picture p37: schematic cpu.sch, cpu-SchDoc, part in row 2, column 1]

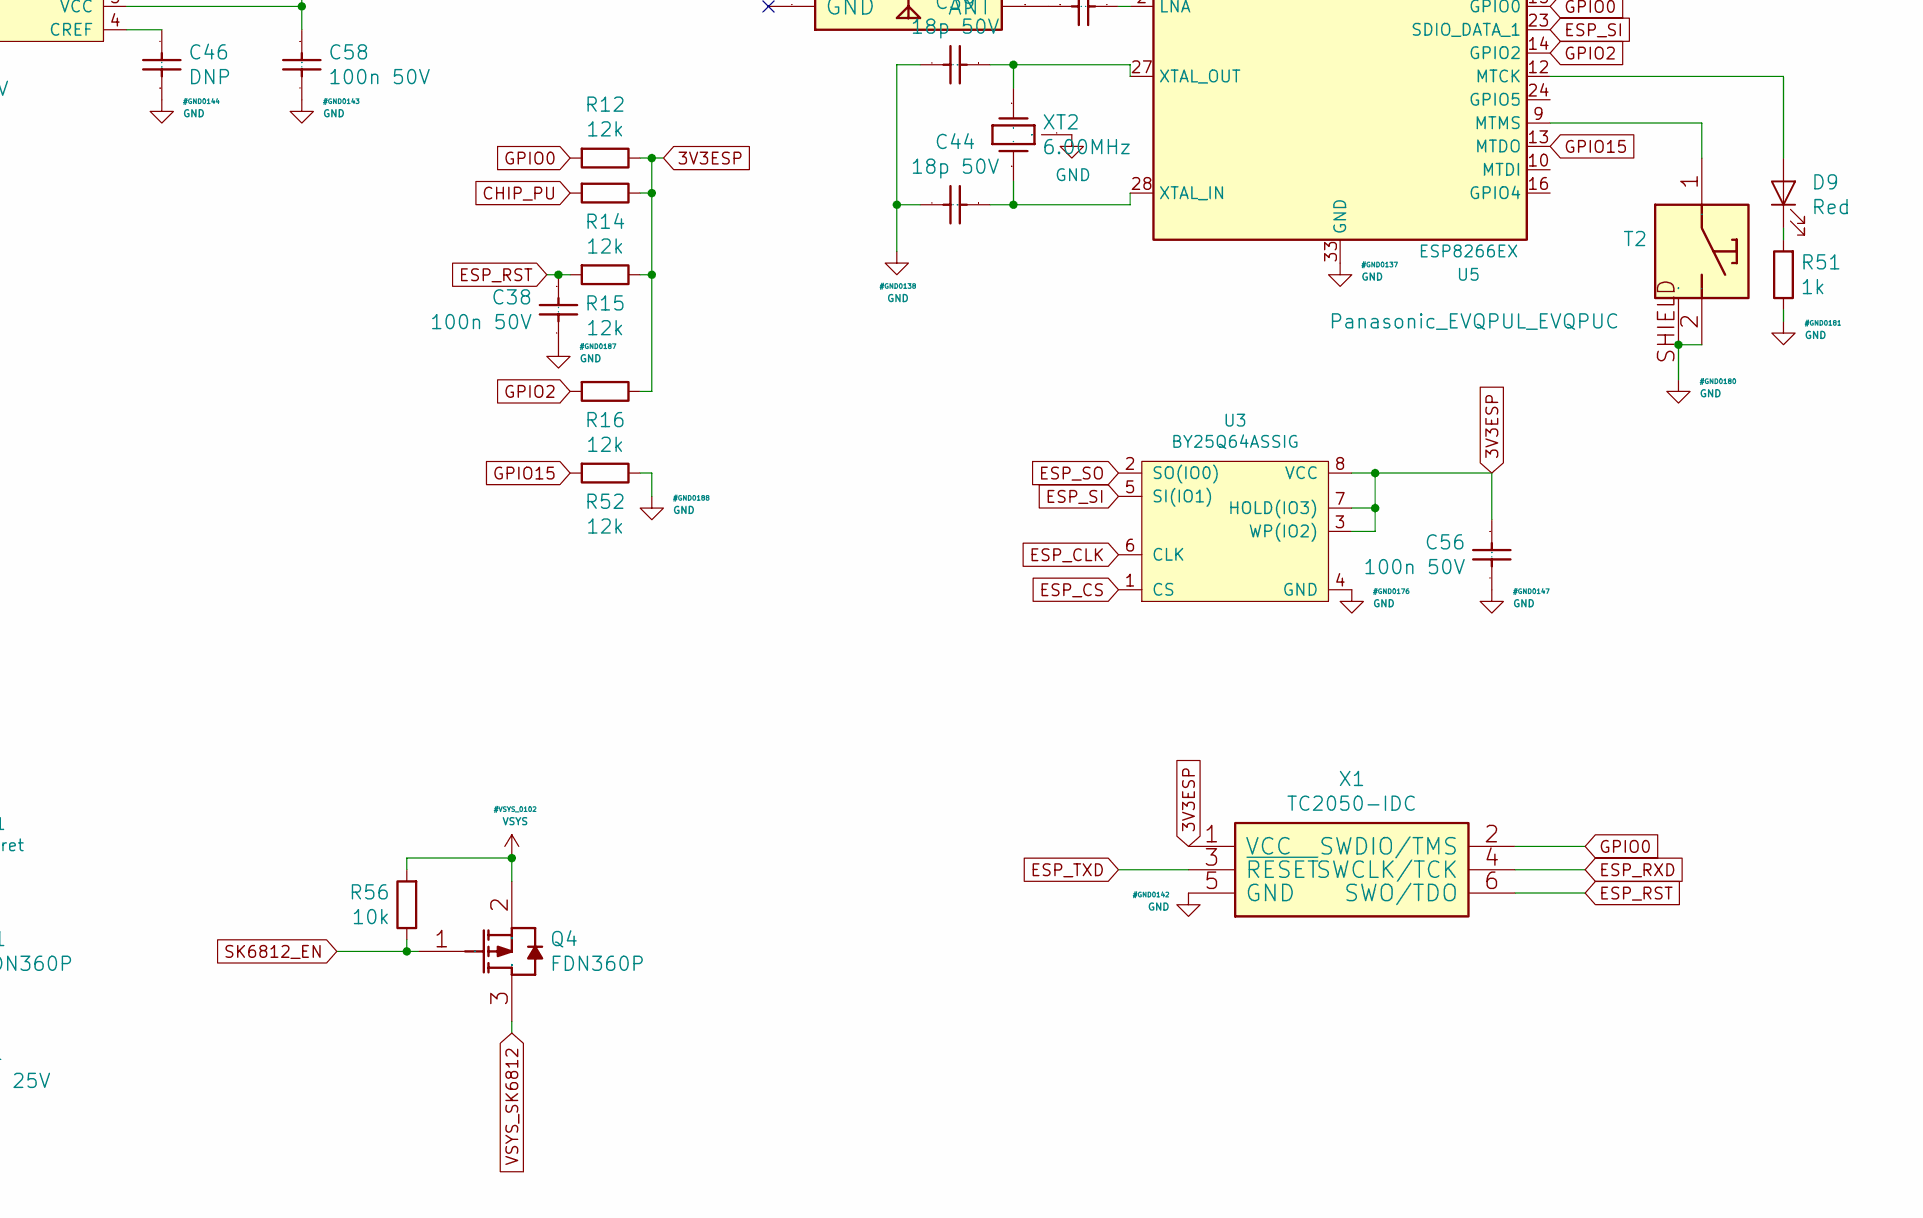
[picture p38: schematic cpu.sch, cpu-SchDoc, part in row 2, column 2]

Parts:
ANT1: ESP-ANTENNA; AN9520_Rainsun
C1, C2, C4, C5, C6, C13, C16, C38, C48, C50, C55, C56, C58: 100n 50V; C_0603_1608Metric
C3, C7: 1u 25v; C_0603_1608Metric
C8: 1u 25V; C_0603_1608Metric
C9, C10, C12, C39, C44, C59: 18p 50V; C_0603_1608Metric
C11, C15: 47n; C_0603_1608Metric
C14: 10u 25V; C_0805_2012Metric
C46: DNP; C_0603_1608Metric
D9: Red; LED_0603_1608Metric
D10: D; D_SOD-123F
FB1, FB2: Ferret; L_0805_2012Metric
LED6, LED7, LED8: LED 1206; LED_1206_3216_BACK
Q1, Q4: FDN360P; SOT-23
R1, R2: 5.1k; R_0603_1608Metric
R3, R4, R5, R6, R7, R8, R9, R10, R11: 28k; R_0603_1608Metric
R12, R14, R15, R16, R52, R53: 12k; R_0603_1608Metric
R13, R17, R19, R20, R22, R56: 10k; R_0603_1608Metric
R18, R21: 47k; R_0603_1608Metric
R23, R24, R25, R51: 1k; R_0603_1608Metric
R54, R55: 0; R_0603_1608Metric
T2: Panasonic_EVQPUL_EVQPUC
U1: STM32F334; TQFP-48_7x7mm_P0.5mm
U2: MIC5501-3.0V; SOT-23-5
U3: BY25Q64ASSIG; SSOP-8_5.25x5.24mm_P1.27mm_WIDE_MULTI
U5: ESP8266EX; QFN-32-1EP_5x5mm_P0.5mm_EP3.45x3.45mm
U6: BS801B; SOT-23-6
X1, X3: TC2050-IDC; TC2030
XT1, XT2: 6.00MHz; Oscillator_3225
gnd1: M3 Screw; M3_Screw
ntc1: M3 Screw; M3_Screw

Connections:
3V3: C1.2, C2.2, C5.2, C8.2, FB1.1, FB2.2, R19.2, R20.1, R21.1, R22.1, U1.1 (VBAT), U1.24 (VDD_2), U1.36 (VDD_3), U1.48 (VDD_1), U2.5 (Vout), X3.1 (VCC); also elsewhere on the board
3V3ESP: C13.2, C14.2, C48.2, C50.1, C55.2, C56.1, Q1.3 (DRAIN), R12.1, R14.1, R15.1, R16.1, U3.3 (WP(IO2)), U3.7 (HOLD(IO3)), U3.8 (VCC), U5.1 (VDDA), U5.3 (VDD3P3), U5.4 (VDD3P3), U5.11 (VDDPST), U5.17 (VDDPST), U5.29 (VDDD), U5.30 (VDDA), X1.1 (VCC)
/cpu/SWCLK: U1.37 (PA14), X3.4 (SWCLK/TCK)
/cpu/SWDIO: U1.34 (PA13), X3.2 (SWDIO/TMS)
/cpu/TOUCH33: R4.1, R5.2
/cpu/TOUCH44: R9.1, R10.2
/cpu/TOUCH223: R1.2, R3.2
/cpu/TOUCH224: R2.2, R11.1
/cpu/TOUCH233: R3.1, R4.2
/cpu/TOUCH244: R10.1, R11.2
/cpu/TOUCH334: R6.1, R7.2
/cpu/TOUCH344: R7.1, R8.2
CHIP_PU: R14.2, U5.7 (CHIP_PU)
COMP2_OUT: U1.33 (PA12)
ESP: Q1.1 (GATE), R17.1, U1.21 (PB10)
ESP_CLK: U3.6 (CLK), U5.21 (SDIO_CLK)
ESP_CS: U3.1 (CS), U5.20 (SDIO_CMD)
ESP_RST: C38.1, R15.2, U5.32 (~EXT_RSTB~), X1.6 (SWO/TDO)
ESP_RXD: R54.2, U5.25 (U0RXD), X1.4 (SWCLK/TCK)
ESP_SI: U3.5 (SI(IO1)), U5.23 (SDIO_DATA_1)
ESP_SO: U3.2 (SO(IO0)), U5.22 (SDIO_DATA_0)
ESP_TXD: R55.2, U5.26 (U0TXD), X1.3 (~RESET)
GND: C1.1, C2.1, C3.1, C4.1, C5.1, C6.1, C7.1, C8.1, C10.2, C11.2, C12.2, C13.1, C14.1, C15.2, C16.1, C38.2, C39.2, C44.2, C46.1, C48.1, C50.2, C55.1, C56.2, C58.2, C59.1, R18.2, R23.1, R24.1, R25.1, R51.1, R52.1, R53.2, T2.2, T2.SHIELD, U1.8 (VSSA/VREF-), U1.23 (VSS_2), U1.35 (VSS_3), U1.47 (VSS_1), U2.2 (GND), U3.4 (GND), U5.33 (GND), U6.2 (VSS), X1.5 (GND), X3.5 (GND), XT1.2 (OUT), XT1.4 (OUT), XT2.2 (OUT), XT2.4 (OUT), gnd1.1; also elsewhere on the board
GPIO0: R12.2, U5.15 (GPIO0), X1.2 (SWDIO/TMS)
GPIO2: R16.2, U5.14 (GPIO2)
GPIO15: R52.2, U5.13 (MTDO)
ICOMP1: U1.14 (PA4), U1.17 (PA7); also elsewhere on the board
ICOMP2: U1.15 (PA5), U1.18 (PB0); also elsewhere on the board
LED1: LED6.2 (A), U1.28 (PB15)
LED2: LED7.2 (A), U1.32 (PA11)
LED3: LED8.2 (A), U1.38 (PA15)
NRST: C16.2, R21.2, U1.7 (NRST), X3.3 (~RESET)
NTC: R13.1, R19.1, ntc1.1
unnamed: ANT1.1 (ANT), C9.1
unnamed: C3.2, C4.2, FB2.1, U1.9 (VDDA/VREF+)
unnamed: C9.2, U5.2 (LNA)
unnamed: C10.1, U1.5 (PF0-OSC_IN(PF0)), XT1.3 (IN)
unnamed: C12.1, U1.6 (PF1-OSC_OUT(PF1)), XT1.1 (IN)
unnamed: C39.1, U5.27 (XTAL_OUT), XT2.3 (IN)
unnamed: C44.1, U5.28 (XTAL_IN), XT2.1 (IN)
unnamed: C46.2, U6.4 (CREF)
unnamed: D9.1 (K), R51.2
unnamed: D9.2 (A), U5.12 (MTCK)
unnamed: D10.2 (A), U1.42 (PB6)
unnamed: FB1.2, Q1.2 (SOURCE), R17.2
unnamed: LED6.1 (K), R23.2
unnamed: LED7.1 (K), R24.2
unnamed: LED8.1 (K), R25.2
unnamed: R13.2, U1.20 (PB2)
unnamed: R18.1, U1.44 (BOOT0)
unnamed: R53.1, U5.31 (RES12K)
unnamed: T2.1, U5.9 (MTMS)
OTG: U1.41 (PB5); also elsewhere on the board
PWM1L: U1.27 (PB14); also elsewhere on the board
PWM2L: U1.25 (PB12); also elsewhere on the board
SCL: R22.2, U1.45 (PB8); also elsewhere on the board
SDA: R20.2, U1.46 (PB9); also elsewhere on the board
SK6812: U1.16 (PA6); also elsewhere on the board
SK6812_EN: Q4.1 (GATE), R56.1, U1.29 (PA8)
TOUCH1: R8.1, R9.2, U1.10 (PA0)
TOUCH2: R1.1, R2.1, U1.12 (PA2)
TOUCH3: R5.1, R6.2, U1.11 (PA1)
TOUCH4: C11.1, U1.13 (PA3)
TOUCH5: C15.1, U1.39 (PB3)
TOUCH6: U1.43 (PB7)
TOUCH7: C59.2, U6.3 (keyin)
TOUCH8: U1.40 (PB4)
TOUCH_POWER: D10.1 (K), U6.1 (keyout); also elsewhere on the board
UCOMP1: U1.22 (PB11); also elsewhere on the board
USART1_RX: R55.1, U1.31 (PA10)
USART1_TX: R54.1, U1.30 (PA9)
VBAT: U1.19 (PB1); also elsewhere on the board
VBAT+: C58.1, U6.5 (VCC); also elsewhere on the board
VSYS: C6.2, C7.2, Q4.2 (SOURCE), R56.2, U2.1 (Vin), U2.3 (EN); also elsewhere on the board
VSYS_SK6812: Q4.3 (DRAIN); also elsewhere on the board

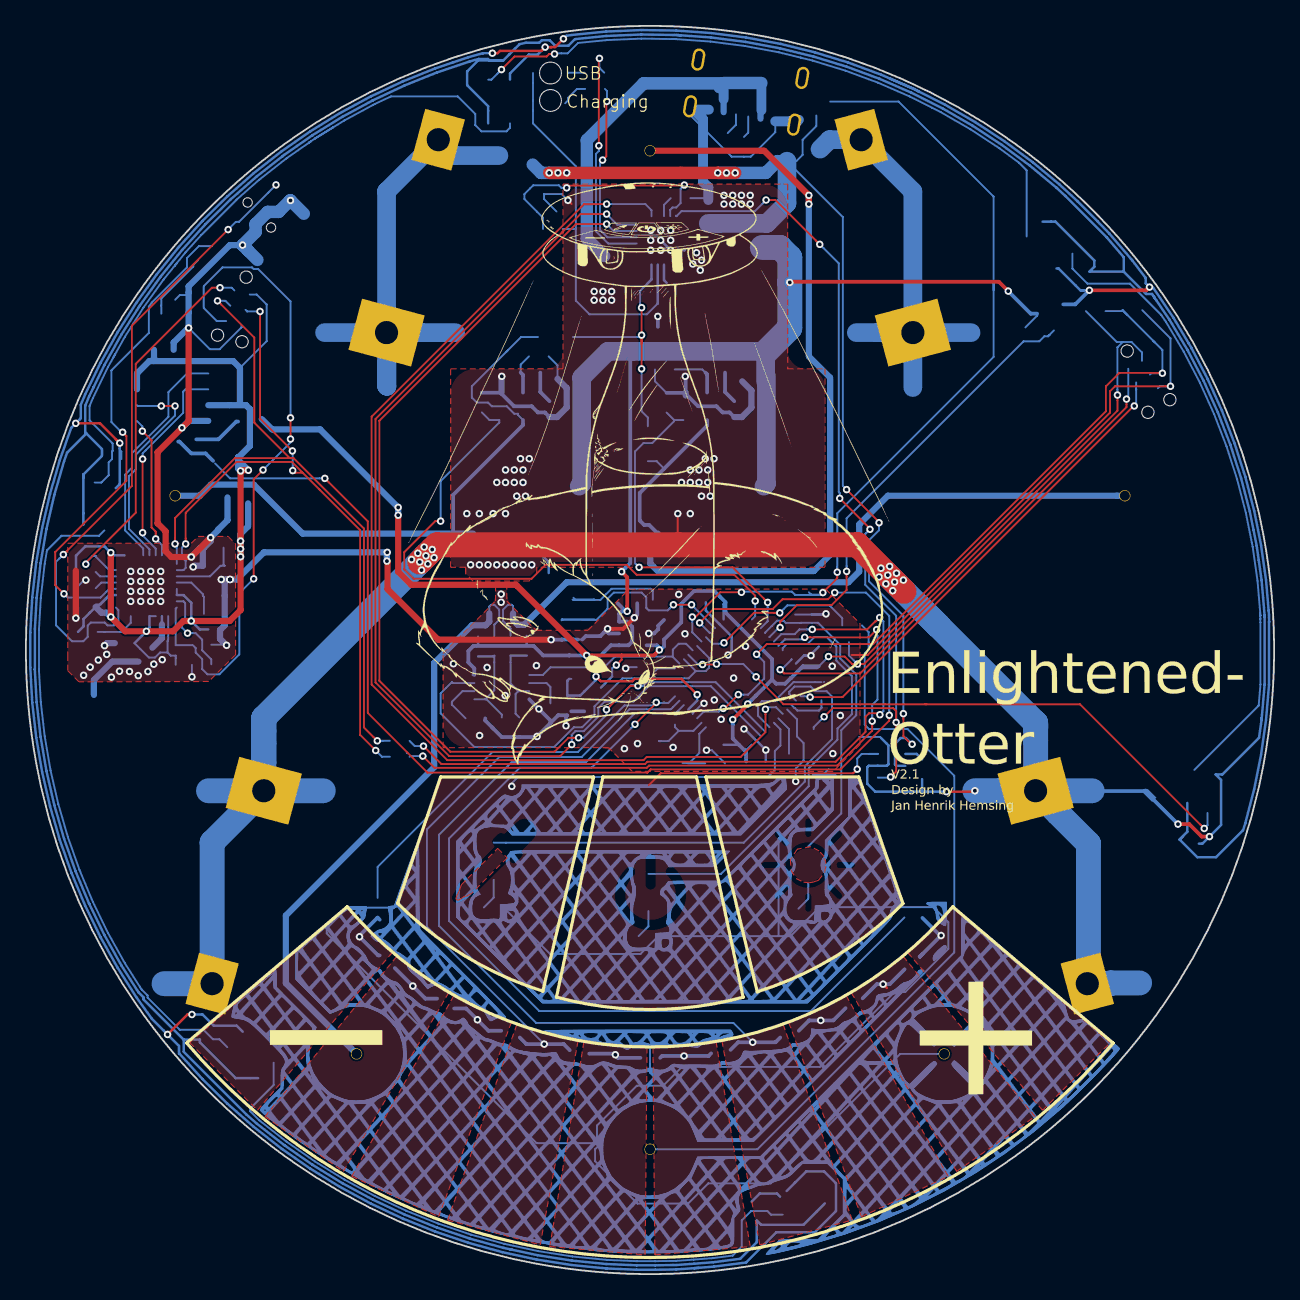
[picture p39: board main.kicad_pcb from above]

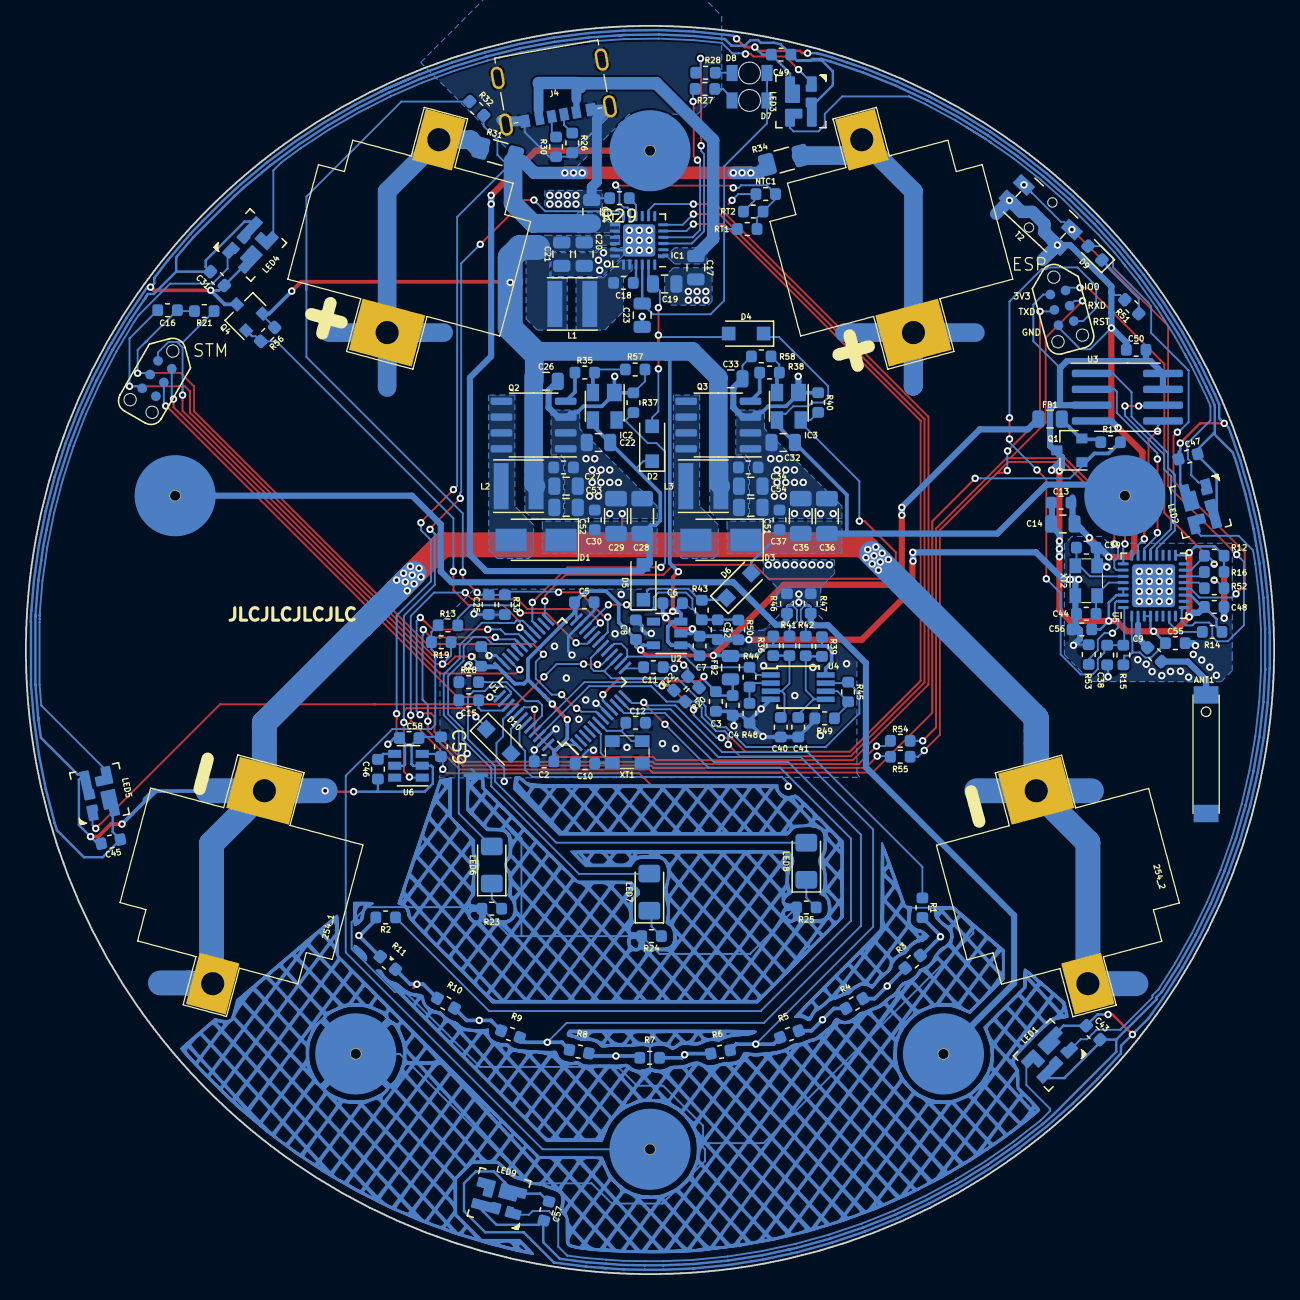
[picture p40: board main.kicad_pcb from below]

Board: 2 copper layers, 100.0 x 100.0 mm, 174 parts (173 on the bottom side), 108 nets.

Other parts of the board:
G1: LOGO; power_0707

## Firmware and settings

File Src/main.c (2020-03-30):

/*
 * Enlightened-Otter  -  Stm32f334 based mobile worklight.
 * Copyright (C) 2019 Jan Henrik Hemsing
 *
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
 * You should have received a copy of the GNU General Public License along with
 * this program.  If not, see <http://www.gnu.org/licenses/>.
 */

#include <math.h>
#include <string.h>
#include "main.h"
#include "stm32f3xx_hal.h"
#include "init_functions.h"
#include "defines.h"
#include "utils.h"
#include "variables.h"
#include "sk6812.h"

extern ADC_HandleTypeDef hadc2;
extern ADC_HandleTypeDef hadc1;

extern COMP_HandleTypeDef hcomp2;
extern COMP_HandleTypeDef hcomp4;
extern COMP_HandleTypeDef hcomp6;

extern DAC_HandleTypeDef hdac1;
extern DAC_HandleTypeDef hdac2;

extern HRTIM_HandleTypeDef hhrtim1;

extern TIM_HandleTypeDef htim1;
extern TIM_HandleTypeDef htim15;
extern TIM_HandleTypeDef htim16;

extern I2C_HandleTypeDef hi2c1;

extern TSC_HandleTypeDef htscs;        // Touch slider handle
extern TSC_IOConfigTypeDef IoConfigs;

extern TSC_HandleTypeDef htscb;        // Touch button handle
extern TSC_IOConfigTypeDef IoConfigb;

extern UART_HandleTypeDef huart1;

void slider_task(void);
void button_task(void);
void UI_task(void);
void TSC_task(void);
void LED_task(void);
void boost_reg();

struct touch_t t = {.IdxBank = 0, .slider.offsetValue = {1000, 1200, 1400}, .button.offsetValue = {1, 2700, 3300}, .button.CBSwitch = 0, .button.state = 1};
struct reg_t r = {.Magiekonstante = (KI * (1.0f / (HRTIM_FREQUENCY_KHZ * 1000.0f) * REG_CNT)), .WW.target = 0.0f, .CW.target = 0.0f};
struct UI_t ui = {.color = 0.7, .colorLast = {0.7,0.7,0.7,0.7}, .brightness = 40, .brightnessLast = {40,40,40,40}};
struct status_t stat = {.vBat = 4.2};
extern uint16_t write_buffer[LED_BUFFER_SIZE];

hsv otter;
rgb otter_rgb;
uint8_t moodlight = 0;
uint8_t party = 0;
double colorOffset;
uint32_t standby = 0;

int main(void)
{
  HAL_Init();
  SystemClock_Config();

  GPIO_Init();
  DMA_Init();
  ADC1_Init();
  ADC2_Init();
  COMP2_Init();
  COMP4_Init();
  COMP6_Init();
  HRTIM1_Init();
  TSC_Init();
  I2C1_Init();
  USART1_UART_Init();
  DAC1_Init();
  DAC2_Init();
  TIM1_Init();
  TIM16_Init();

  HAL_COMP_Start(&hcomp2);
  HAL_COMP_Start(&hcomp4);
  HAL_COMP_Start(&hcomp6);

  HAL_DAC_Start(&hdac1, DAC_CHANNEL_2);
  HAL_DAC_Start(&hdac2, DAC_CHANNEL_1);

  HAL_DAC_SetValue(&hdac1, DAC_CHANNEL_2, DAC_ALIGN_12B_R, 4095);  // set the current for the COMP2,4 to trigger FLT_1
  HAL_DAC_SetValue(&hdac2, DAC_CHANNEL_1, DAC_ALIGN_12B_R, 4095);  // set the voltage for the COMP6 to trigger FLT_1

  RT_Init();      // initialize the RT9466, mainly sets ILIM
  configure_RT(CHG_CTRL1,0x10);

  start_HRTIM1(); // start HRTIM and enable outputs

  set_pwm(HRTIM_TIMERINDEX_TIMER_D, MIN_DUTY); // clear PWM registers needs to be done, otherwise power failure
  set_pwm(HRTIM_TIMERINDEX_TIMER_C, MIN_DUTY); // clear PWM registers

  HAL_TIM_Base_Start(&htim1);
  HAL_TIM_PWM_Start(&htim1, TIM_CHANNEL_4);

  HAL_TSC_Start_IT(&htscb);   // start the touch button controller

  HAL_ADC_Start(&hadc1);

  HAL_Delay(100); // measure current offset
  r.CW.ioff = r.CW.iavg;  // IOffsetCW - mA
  r.WW.ioff = r.WW.iavg;  // IOffsetWW - mA

  HAL_TIM_PWM_Start_DMA(&htim16, TIM_CHANNEL_1, write_buffer, LED_BUFFER_SIZE);

  otter.h = 0;
  otter.s = 1.0;
  otter.v = 1.0;
  while (1)
  {
    HAL_Delay(10);
    //otterStat = read_RT_register(0x11);
    //RT_adc_task();
    // WIP move to sk6812.c file, optimize

    if(moodlight && !t.slider.isTouched){
      HAL_GPIO_WritePin(GPIOA,SK6812_EN,0);
      for(int i = 0; i <= 5; i++){
        otter.h = (int)((i) + (HAL_GetTick()/600))%360;
        otter.s = 1.0;
        otter.v = 1.0;
        set_pixel(i,hsv2rgb(otter),write_buffer);
      }
    } else if (party && !t.slider.isTouched ){
      HAL_GPIO_WritePin(GPIOA,SK6812_EN,0);
      for(int i = 0; i <= 5; i++){
        otter.h = (int)((i*60) + (HAL_GetTick()/30))%360;
        otter.s = 1.0;
        otter.v = 1.0;
        set_pixel(i,hsv2rgb(otter),write_buffer);
      }
    }
    /*else if (!t.button.CBSwitch && t.slider.isTouched && t.button.state && ui.debounce >= UI_DEBOUNCE_VAL){

      HAL_GPIO_WritePin(GPIOA,SK6812_EN,0);
      for(int i = 0; i <= 5; i++){
        otter.h = 180.0;
        if((int)((ui.brightness/MAX_CURRENT)*6.0)>i){
          otter.v = 1.0;
        } else if((int)((ui.brightness/MAX_CURRENT)*6.0)>=i){
          otter.v = ((ui.brightness/MAX_CURRENT)*6.0)-(int)((ui.brightness/MAX_CURRENT)*6.0);
        } else {
          otter.v = 0.0;
        }
        otter.s = 0.5;
        set_pixel(((i+2)%6),hsv2rgb(otter),write_buffer);
      }
    } else if (t.button.CBSwitch && t.slider.isTouched  && t.button.state && ui.debounce >= UI_DEBOUNCE_VAL){
      HAL_GPIO_WritePin(GPIOA,SK6812_EN,0);
      for(int i = 0; i <= 5; i++){

        if(((int)(ui.color*6.0f))>i){
          otter_rgb.r = 0.5;
          otter_rgb.g = 0.7;
          otter_rgb.b = 1;
        }
        else if(((int)(ui.color*6.0f))>=i){
          colorOffset = (ui.color*6.0f)-((int)(ui.color*6.0f));
          otter_rgb.g = 0.5 + (0.5*(colorOffset));
          otter_rgb.r = 0.7 ;//+ -((0.5*(colorOffset)) * (0.5*(1.0-colorOffset)))*2;
          otter_rgb.b = 0.5 + (0.5*(colorOffset-2.0));
        }
        else {
          otter_rgb.r = 1;
          otter_rgb.g = 0.7;
          otter_rgb.b = 0.5;
        }
        set_pixel(((i+2)%6),otter_rgb,write_buffer);
      }
    }
    */else {
      HAL_GPIO_WritePin(GPIOA,SK6812_EN,1);
    }


    if(t.button.state || party || moodlight){
      standby = HAL_GetTick();
    } else {
      if(standby + STANDBY_TIME_CALC < HAL_GetTick()) stat.state = -1;
    }

    stat.vBat = FILT(ADC2VBAT(HAL_ADC_GetValue(&hadc1)),stat.vBat,0.95);
    HAL_ADC_Start(&hadc1);

    if ((stat.vBat > 1.5f && stat.vBat < 2.9f) || stat.state == -1) powerdown();
  }
}

HAL_HRTIM_RepetitionEventCallback(HRTIM_HandleTypeDef * hhrtim, uint32_t TimerIdx){
  boost_reg();
}

void boost_reg(void) {
  // Main current regulator
  stat.ledTemp = ntc_calc(HAL_ADCEx_InjectedGetValue(&hadc2, ADC_INJECTED_RANK_1));

  r.CW.iout = AMP(HAL_ADCEx_InjectedGetValue(&hadc2, ADC_INJECTED_RANK_2),SHUNT_GAIN) * 1000.0f;  // ISensCW - mA
  r.WW.iout = AMP(HAL_ADCEx_InjectedGetValue(&hadc2, ADC_INJECTED_RANK_3),SHUNT_GAIN) * 1000.0f;  // ISensWW - mA

  r.CW.iavg = FILT(r.CW.iavg, r.CW.iout, CURRENT_AVERAGING_FILTER); // Moving average filter for CW input current
  r.WW.iavg = FILT(r.WW.iavg, r.WW.iout, CURRENT_AVERAGING_FILTER); // Moving average filter for WW input current

  r.CW.error = r.CW.target - (r.CW.iavg - r.CW.ioff);  // Calculate CW-current error
  r.WW.error = r.WW.target - (r.WW.iavg - r.WW.ioff);  // Calculate WW-current error

  r.CW.duty += (r.Magiekonstante * r.CW.error);     // Simple I regulator for CW current
  r.CW.duty = CLAMP(r.CW.duty, MIN_DUTY, MAX_DUTY); // Clamp to duty cycle

  r.WW.duty += (r.Magiekonstante * r.WW.error);     // Simple I regulator for WW current
  r.WW.duty = CLAMP(r.WW.duty, MIN_DUTY, MAX_DUTY); // Clamp to duty cycle

  if (r.CW.target < CURRENT_CUTOFF) r.CW.duty = MIN_DUTY;
  if (r.WW.target < CURRENT_CUTOFF) r.WW.duty = MIN_DUTY;

  set_pwm(HRTIM_TIMERINDEX_TIMER_D, r.CW.duty);  // Update CW duty cycle
  set_pwm(HRTIM_TIMERINDEX_TIMER_C, r.WW.duty);  // Update WW duty cycle
}

void set_brightness(uint8_t chan, float brightness, float color, float max_value) {
  float target_tmp, color_tmp;

  if (chan)       color_tmp = (1.0f - color);   // set color temperature multiplicator from 0 to 1 for WW
  else if (!chan) color_tmp = color;            // and from 1 to 0 for CW

  target_tmp = CLAMP((brightness * color_tmp), 0.0f, max_value);  // calculate brightness accordingly and clamp it

  if (chan)       r.WW.target = gamma_calc(target_tmp);
  else if (!chan) r.CW.target = gamma_calc(target_tmp);
}

void TSC_task(void) {

  if (HAL_TSC_GroupGetStatus(&htscs, TSC_GROUP1_IDX) == TSC_GROUP_COMPLETED)
  {
    int16_t _tmp = t.slider.acquisitionValue[t.IdxBank];
    t.slider.acquisitionValue[t.IdxBank] = HAL_TSC_GroupGetValue(&htscs, TSC_GROUP1_IDX);
    if (t.IdxBank == 1) t.slider.acquisitionValue[t.IdxBank] = t.slider.acquisitionValue[t.IdxBank] * 2;    // outer channel has only half the strenght
    if (t.IdxBank == 0) t.slider.acquisitionValue[t.IdxBank] = t.slider.acquisitionValue[t.IdxBank] / 2;    // left channel has double the strenght
    t.slider.acquisitionValue[t.IdxBank] = t.slider.acquisitionValue[t.IdxBank] / 2;                        // limit the strenght
    if(ui.brightnessAvg >= 200 && ui.colorAvg >= 0.65){
      if (t.IdxBank == 0) t.slider.acquisitionValue[t.IdxBank] += 550;
      if (t.IdxBank == 2) t.slider.acquisitionValue[t.IdxBank] += 500;
    }
    t.slider.acquisitionValue[t.IdxBank] = t.slider.acquisitionValue[t.IdxBank] - t.slider.offsetValue[t.IdxBank];
    t.slider.acquisitionValue[t.IdxBank] = FILT(t.slider.acquisitionValue[t.IdxBank], _tmp, 0.8f);

    slider_task();

    HAL_TSC_IOConfig(&htscb, &IoConfigb);
    HAL_TSC_IODischarge(&htscb, ENABLE);
    __HAL_TSC_CLEAR_FLAG(&htscb, (TSC_FLAG_EOA | TSC_FLAG_MCE));
    HAL_TSC_Start_IT(&htscb);

  } else if (HAL_TSC_GroupGetStatus(&htscb, TSC_GROUP5_IDX) == TSC_GROUP_COMPLETED) {
    t.button.acquisitionValue[t.IdxBank] = HAL_TSC_GroupGetValue(&htscb, TSC_GROUP5_IDX);
    t.button.offsetValue[t.IdxBank] = FILT(t.button.offsetValue[t.IdxBank], t.button.acquisitionValue[t.IdxBank], 0.999);
    t.button.acquisitionValue[t.IdxBank] = t.button.acquisitionValue[t.IdxBank] - t.button.offsetValue[t.IdxBank];
    if(t.button.acquisitionValue[t.IdxBank] > 500) t.button.acquisitionValue[t.IdxBank] = 500;

    button_task();

    HAL_TSC_IOConfig(&htscs, &IoConfigs);
    HAL_TSC_IODischarge(&htscs, ENABLE);
    __HAL_TSC_CLEAR_FLAG(&htscs, (TSC_FLAG_EOA | TSC_FLAG_MCE));
    HAL_TSC_Start_IT(&htscs);
  } else {

    HAL_TSC_IOConfig(&htscb, &IoConfigb);
    HAL_TSC_IODischarge(&htscb, ENABLE);
    __HAL_TSC_CLEAR_FLAG(&htscb, (TSC_FLAG_EOA | TSC_FLAG_MCE));
    HAL_TSC_Start_IT(&htscb);
  }

  switch (t.IdxBank)
  {
  case 0:
    IoConfigb.ChannelIOs = TSC_GROUP5_IO2;
    IoConfigs.ChannelIOs = TSC_GROUP1_IO1;
    t.IdxBank = 1;
    break;
  case 1:
    IoConfigs.ChannelIOs = TSC_GROUP1_IO2;
    t.IdxBank = 2;
    break;
  case 2:
    IoConfigb.ChannelIOs = TSC_GROUP5_IO4;
    IoConfigs.ChannelIOs = TSC_GROUP1_IO3;
    t.IdxBank = 0;
    break;
  default:
    break;
  }

  UI_task();
}

void button_task(void) {
  uint8_t _powButton;
  t.button.acquisitionValue[0] = HAL_GPIO_ReadPin(GPIOB,GPIO_PIN_6);
  if (t.button.acquisitionValue[2] < BUTTON_THRESHOLD) {
    if(t.button.CBSwitch == 0 && t.button.isTouchedTime3 + 500 <= HAL_GetTick()){ //wip
      ui.brightnessLast[3] = 499;
    }
    t.button.CBSwitch = 0; // switch color or brightness selector
    t.button.isTouchedTime3 = HAL_GetTick();
    t.button.isTouchedTime2++;
  } else if (t.button.acquisitionValue[1] < BUTTON_THRESHOLD) {
    t.button.CBSwitch = 1;
    t.button.isTouchedTime2++;
  } else if (t.button.acquisitionValue[0] == 0 && t.button.acquisitionValue[1] > BUTTON_THRESHOLD && t.button.acquisitionValue[2] > BUTTON_THRESHOLD) {
    _powButton = 1;        // if the power button is pressed set to 1
    t.button.isTouchedTime++;
  } else {
    _powButton = 0;
    t.button.isTouchedTime = 0;
  }

  // "hard" Off state maschine //WIP tofix isTouchedTime does not trigger moodlight
  if (t.button.isTouchedTime > TURNOFF_TIME && _powButton) {
    stat.state = -1;// when the counter target is reached, turn off via richtek "shipping" mode
    t.button.isTouchedTime = 0;
  }

  // Enable moodlight

  if (t.button.isTouchedTime2 > TURNOFF_TIME && t.button.CBSwitch) {
    moodlight ^= 1;
    party = 0;
    t.button.isTouchedTime2 = 0;
  } else if (t.button.isTouchedTime2 > TURNOFF_TIME && !t.button.CBSwitch) {
    party ^= 1;
    moodlight = 0;
    t.button.isTouchedTime2 = 0;
  }


  // power button state maschine
  if (t.button.isReleased) {                       // power button state maschine start if button was released, waiting for the next press
    if (_powButton == 1 && t.button.state == 0) {  // if powerbutton is pressed and device is off, turn on and reset "is released flag"
      t.button.state = 1;
      t.button.isReleased = 0;
    } else if (_powButton == 1 && t.button.state == 1) {  // if powerbutton is pressed and device is on, turn off and reset "is released flag"
      t.button.state = 0;
      t.button.isReleased = 0;
      start_HRTIM1();                               // for now lets reset the flt state in the power off state
    }
  } else if (!t.button.isReleased && _powButton == 0) t.button.isReleased = 1; // set isReleased flag if powerbutton was released
}

void slider_task(void) {
  t.slider.isTouchedVal = MIN(MIN(t.slider.acquisitionValue[0], t.slider.acquisitionValue[1]), t.slider.acquisitionValue[2]); // Check intensity of touch
  t.slider.isTouchedValAvg = FILT(t.slider.isTouchedValAvg, t.slider.isTouchedVal, TOUCH_THRESHOLD_FILTER); // average/Lowpass filter the touch intesity

  if      (t.slider.isTouchedValAvg < IS_TOUCHED_ABS)   t.slider.isTouched = 1; // if delta is larger then x, touch down was detected
  else if (t.slider.isTouchedValAvg > IS_RELEASED_ABS)    t.slider.isTouched = 0; // std value, if no touch is present

  if (t.slider.isTouched ) {
    int16_t x = ((t.slider.acquisitionValue[1] + t.slider.acquisitionValue[2]) / 2) - t.slider.acquisitionValue[0];
    int16_t y = ((t.slider.acquisitionValue[1] + t.slider.acquisitionValue[0]) / 2) - t.slider.acquisitionValue[2];
    int16_t z = ((t.slider.acquisitionValue[2] + t.slider.acquisitionValue[0]) / 2) - t.slider.acquisitionValue[1];

    if      (x < y && x < z && y < z) t.slider.pos = 2 * TOUCH_SCALE - ((z * TOUCH_SCALE) / (y + z));
    else if (x < y && x < z && y > z) t.slider.pos = ((y * TOUCH_SCALE) / (y + z)) + TOUCH_SCALE;
    else if (z < y && z < x && x < y) t.slider.pos = 5 * TOUCH_SCALE - ((y * TOUCH_SCALE) / (y + x));
    else if (z < y && z < x && x > y) t.slider.pos = ((x * TOUCH_SCALE) / (y + x)) + 4 * TOUCH_SCALE;
    else if (y < x && y < z && z < x) t.slider.pos = 8 * TOUCH_SCALE - ((x * TOUCH_SCALE) / (x + z));
    else if (y < x && y < z && z > x) t.slider.pos = ((z * TOUCH_SCALE) / (x + z)) + 7 * TOUCH_SCALE;

    if (t.slider.pos >= t.slider.posLast + 50 || t.slider.pos <= t.slider.posLast - 50){
      uint16_t _tmp = t.slider.pos;
      t.slider.pos = t.slider.posLast;
      t.slider.posLast = _tmp;
    } else {
      t.slider.posLast = t.slider.pos;
    }

    t.slider.posAvg = FILT(t.slider.posAvg, t.slider.pos, SLIDER_FADING_FILTER);
  }
}

void UI_task(void) {
  uint8_t _enable = 1;

  if (t.button.state) {         // if lamp is turned "soft" on
    if (t.slider.isTouched) {   // check if slider is touched
      if (ui.debounce >= UI_DEBOUNCE_VAL) {  // "debounce" slider

        if (SLIDER_BEHAVIOR == REL) {
          if (ABS(t.slider.posAvg - ui.distanceOld) < 200) ui.distance += ui.distanceOld - t.slider.posAvg;        // calculate t.slider.pos delta
          ui.distanceOld = t.slider.posAvg;        // set ui.distanceOld to current t.slider.pos so the delta will be 0
        } else if (SLIDER_BEHAVIOR == AB){
          ui.distance = ((MAX_CURRENT - t.slider.posAvg) - 50 )*1.3;
        }

        ui.distance = CLAMP(ui.distance, 0.0f, MAX_CURRENT);  // clamp it to the maximum current

        if (t.button.CBSwitch == 0) ui.brightness = ui.distance;          // if color/brightness switch is 0 then change brightness
        if (t.button.CBSwitch == 1) ui.color = ui.distance / MAX_CURRENT; // if color/brightness switch is 1 then change the color - scale from 0 to 1

        if(ui.brightnessLast[0] != ui.brightness){
          for (int k = 4; k > 0; k--){
              ui.brightnessLast[k] = ui.brightnessLast[k-1];
          }
        }
        ui.brightnessLast[0] = ui.brightness;

        if(ui.colorLast[0] != ui.color){
          for (int k = 4; k > 0; k--){
              ui.colorLast[k] = ui.colorLast[k-1];
          }
        }
        ui.colorLast[0] = ui.color;

      } else{
         ui.debounce++;   // increase debounce counter until counter-target is reached

         for (int k = 4; k > 0; k--){
             ui.brightnessLast[k] = ui.brightnessLast[3];
         }

         for (int k = 4; k > 0; k--){
             ui.colorLast[k] =  ui.colorLast[3];
         }

      }

      if (t.button.CBSwitch == 0) ui.distance = ui.brightness;          // prevents jumps when switching between modes
      if (t.button.CBSwitch == 1) ui.distance = ui.color * MAX_CURRENT; // prevents jumps when switching between modes


    } else ui.debounce = 0;                 // clear douncer if slider is not touched
  } else if (!t.button.state) {
    _enable = 0;
  }  // if button state is 0 disable output

  if (_enable && (ui.colorAvg != ui.color || ui.brightnessAvg != ui.brightness)) {      // smooth out color value until target is reached and output is enabled
    ui.colorAvg = FILT(ui.colorAvg, ui.colorLast[3], COLOR_FADING_FILTER);                     // moving average filter with fixed constants for the color mixing
    ui.brightnessAvg = FILT(ui.brightnessAvg, ui.brightnessLast[3], 0.95f); // moving average filter with fixed constants for the brightness
    set_brightness(CHAN_CW, ui.brightnessAvg, ui.colorAvg, MAX_CURRENT);  // set CW brightness accordingly to output
    set_brightness(CHAN_WW, ui.brightnessAvg, ui.colorAvg, MAX_CURRENT);  // set WW brightness accordingly to output
  } else {                                                    // if output is not enabled - brightness and color are ignored here
    set_brightness(CHAN_CW, 0.0f, ui.colorAvg, MAX_CURRENT);  // set CW output to 0
    set_brightness(CHAN_WW, 0.0f, ui.colorAvg, MAX_CURRENT);  // set WW output to 0
  }

  LED_task();
}

void LED_task(void) {
  if (t.button.state == 1) {
    HAL_GPIO_WritePin(GPIOB, LED_Brightness, !t.button.CBSwitch); // set LED "Brightness"
    __HAL_TIM_SET_COMPARE(&htim1, TIM_CHANNEL_4, 4096);           // set LED "Power"
    HAL_GPIO_WritePin(GPIOA, LED_Color, t.button.CBSwitch);       // set LED "Color"
  } else {
    HAL_GPIO_WritePin(GPIOB, LED_Brightness, 0);                  // clear LED "Brightness"
    __HAL_TIM_SET_COMPARE(&htim1, TIM_CHANNEL_4, 512);            // clear LED "Power"
    HAL_GPIO_WritePin(GPIOA, LED_Color, 0);                       // clear LED "Color"
  }
}

void _Error_Handler(char * file, int line)
{
  while (1)
  {
    HAL_GPIO_WritePin(GPIOB, LED_Brightness, 0);                  // clear LED "Brightness"
    HAL_GPIO_WritePin(GPIOA, LED_Color, 0);                       // clear LED "Color"
    HAL_Delay(600);
    HAL_GPIO_WritePin(GPIOB, LED_Brightness, 1);                  // clear LED "Brightness"
    HAL_GPIO_WritePin(GPIOA, LED_Color, 1);                       // clear LED "Color"
    HAL_Delay(600);
  }
}

#ifdef USE_FULL_ASSERT

void assert_failed(uint8_t* file, uint32_t line)
{

}

#endif

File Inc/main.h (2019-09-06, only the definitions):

#define LED_Brightness GPIO_PIN_15
#define LED1_GPIO_Port GPIOB
#define ESP_EN GPIO_PIN_10
#define ESP_EN_GPIO_Port GPIOB
#define LED_Color GPIO_PIN_15
#define LED2_GPIO_Port GPIOA
#define LED_Power GPIO_PIN_11
#define LED3_GPIO_Port GPIOA
#define SK6812_EN GPIO_PIN_8
#define SK6812_EN_GPIO_Port GPIOA

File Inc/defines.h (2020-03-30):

/*
 * Enlightened-Otter  -  Stm32f334 based mobile worklight.
 * Copyright (C) 2019 Jan Henrik Hemsing
 *
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
 * You should have received a copy of the GNU General Public License along with
 * this program.  If not, see <http://www.gnu.org/licenses/>.
 */

#define DO_EXPAND(VAL)  VAL ## 1
#define EXPAND(VAL)     DO_EXPAND(VAL)

#define SCOPE_CHANNELS 	0 	// sets the number of (uart) scope channels to be set/transmitted, non defining SCOPE_CHANNELS will remove the function completly

#define MAX_CURRENT 499.0f 	// sets the maximum current

#define HRTIM_FREQUENCY_KHZ 500.0f 	// sets the frequency of the PWM output channels maximum frequency (8 bit PWM): 18Mhz (18000.0) SHOULD BE DIVIDABLE BY 2
 									// 250.2f,300.0f,350.0f,400.0f,450.0f,500.0f,550.0f,600.0f,650.1f,700.1f,750.0f,800.0f
#define REG_CNT 		10	 // sets the number of HRTIM passes to the next controller pass
#define KI 					0.4f // sets the KI constant for the current regulator - do not change unless you know what you're doing

#define MIN_DUTY 	0.007f 	// sets the minimum duty cycle that the regulation can reach, can be left at 0.002
#define MAX_DUTY 	0.83f 	// sets the maximum duty cycle that the regulation can reach, should not exceed a certain but by now uncertain value

#define CURRENT_AVERAGING_FILTER 	0.90f	// koeffizient of current averaging filter 0 = no averaging 1 = infinite averaging
#define COLOR_FADING_FILTER 		  0.90f	// koeffizient of color cross fading filter
#define TOUCH_THRESHOLD_FILTER    0.9f
#define SLIDER_FADING_FILTER		  0.98f

#define STANDBY_TIME      4     // turn off EO after 4 min idle
#define TURNOFF_TIME 		  60		// sets the time to count to before turning off
#define BUTTON_THRESHOLD  -800	// sets the threshold at which a button press has to be triggered
#define IS_TOUCHED_ABS    -200  // sets the threshold for a slider detection event
#define IS_RELEASED_ABS   -150 // sets the threshold for slider release

#define CURRENT_CUTOFF		0.6f 	// sets the threshold at which the boost will be turned off

#define SLIDER_BEHAVIOR		AB 	// 0 = AB = Absolute, 1 = REL = relative

#define SHUNT         0.22f
#define SHUNT_SERIE   1000
#define SHUNT_PULLUP  220000
#define AREF          2.9f
#define ARES          4096.0f
#define SHUNT_GAIN    19.3333f
#define BATT_PULLUP   220000.0f
#define BATT_PULLDOWN 47000.0f

#define FAULT_CURRENT		(int)(3900) 	// Overcurrent set to ~590mA
#define FAULT_VOLTAGE		(int)(2250) 	// Overvoltaeg set to 17V
/*
#if (EXPAND(SLIDER_BEHAVIOR) == 1)
#define TOUCH_SCALE 200.0f   	// sets the touch slider scale - I have No idea anymore how this works
#else
#define TOUCH_SCALE 62.5f   	// sets the touch slider scale - I have No idea anymore how this works
#endif
*/
#define TOUCH_SCALE     62.5f
#define UI_DEBOUNCE_VAL 4

// ############################################################# //
// Automatic calculated Values, please use the variables above

#define HRTIM_PERIOD      (int)(1.0/(HRTIM_FREQUENCY_KHZ*1000.0f)/0.000000000217f) // calculates the timer period value, therefore sets the frequency
#define STANDBY_TIME_CALC (uint32_t)(STANDBY_TIME*60*1000*2)
#define LED_BUFFER_SIZE   ((6*24) + 42)

// ############################################################# //
// I2C registers

#define RT_ADDRESS 			(0x53 << 1)	// std i2c address for the rt9466

#define CHG_CTRL1 				0x01	//
#define ENABLE_OTG_MASK 		0x11	// enables OTG, should be on by default
#define DISABLE_OTG_MASK 		0x10	// disables OTG, should be on by default
#define ENABLE_STAT_LED_MASK 	0x10	// Turn on status LED (default)
#define DISABLE_STAT_LED_MASK 	0x00	// turn off status LED

#define CHG_CTRL2 		0x02	//
#define TURNOFF_MASK 	0x83	// shuts down power immediately, can only be resetted by button press
#define IINLIM_MASK 	0x0B	// sets the input current limit to software register see CHG_CTRL3

#define CHG_CTRL3 		0x03	//
#define SET_ILIM_3A 	0xEB	// sets the input current limit to 3A

#define CHG_CTRL13		0x0D	//
#define ENABLE_UUG		0x52 	// Enables UUG_Fet, battery voltage is present on VMID
#define DISABLE_UUG		0x50 	// Disables UUG_Fet, no Battery voltage is present on VMID nor the OTG voltage is present on VBUS

#define CHG_CTRL16 		0x10	//
#define DISABLE_JEITA 	0x00	// Disable JEITA charger profile, idk maybe we dont want this
#define ENABLE_JEITA 	0x10	// Enable it again

#define CHG_IRQ3 		0x55
#define ADC_READY_MASK	0x01

#define CHG_STAT 		0x42	// Contains all the status bits
#define FASTCHARGE_MASK 0x20
#define CHG_MASK		0x40
#define CHG_DONE_MASK	0x80
#define ADC_DONE_MASK	0x01
// [7:6] 00 ready; 01 charge in progress; 10 charge done; 11 fault
// 5 	 0 precharge; 1 fastcharge
// 4	 0 no trickle charge; 1 trickle charge
// 3 	 0 not in boos mode; 1 in boost mode
// 2 	 0 boost VBUS OVP does not occur ; 1 boost VBUS OVP occurs
// 1  	 reserved
// 0 	 0 ADC idle; 1 ADC under conversion

#define ADC_DATA_H 	0x44	// ADC High byte value
#define ADC_DATA_L 	0x45	// ADC Low byte value
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

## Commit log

2018-07-17 added 3D files
    [nut.stl, shaft.stl, thread.scad]
2018-07-18 Added basic hrtim pwm functionality for channel D and C
2018-07-18 fixed hrtim clock source
    [defines.h, main.c]
2018-07-18 pwm frequency is now 350Khz
2018-07-19 fixed fault off for HRTIM
    [main.c]
2018-07-20 added over- current/voltage calculations
2018-07-22 fixed current calculation values
    [defines.h]
2018-07-23 fixed non working timer C
    [main.c]
2018-08-01 fixed period calculation in main
    [main.c]
2018-08-02 fixed overvoltage and overcurrent calculation
    [defines.h, main.c]
2018-08-03 fixed timer bug and changed test routine
    [main.c]
2018-08-07 added basic injected adc functionality (Not tested yet)
2018-08-08 added basic Injected ADC config, adc is now kind of working
2018-08-08 fixed basic ADC operation, seems to work now somehow, also changed consolescope to tabs
    [defines.h, main.c]
2018-08-08 fixed ADC injection
2018-08-09 changed ADC settings
2018-08-09 added current sensing test
2018-08-09 Added schematic
2018-08-09 added I regulator
2018-08-10 removed old ADC code
2018-08-10 improved regulator
2018-08-10 changed Voltage calculation to fixed constant
    [main.c]
2018-08-11 added LED pin descriptions
2018-08-13 removed PCB checklist
2018-08-13 added ADC EOC interrupt
2018-08-13 added ADC EOC interrupt and main regulation activity based on EOC interrupt
2018-08-14 changed LED pin names
2018-08-14 added TSC interrupt (maybe)
2018-08-15 calibrated TSC 5
2018-08-15 added basic button functionality
2018-08-16 fixed functions and moved stuff
    [main.c]
2018-08-16 added TSC interrupt routine
2018-08-16 TSC interrupt should work now
2018-08-16 updated 3D files for testing
    [shaft.stl, thread.scad]
2018-08-16 changed sizing
    [thread.scad]
2018-08-16 exported stl
    [shaft.stl]
2018-08-16 changed interface to relative movements and tested tsc interrupt, doesnt work
2018-08-16 changed spacing
    [shaft.stl, thread.scad]
2018-08-17 fixed regulator adc1 not fixed
    [main.c]
2018-08-17 fixed jumps in brightness and color
    [main.c]
2018-08-17 shortend voltage measurement
2018-08-17 changed regulator cycle time to 63
2018-08-18 changed parameters
    [thread.scad]
2018-08-19 added power button state maschine
2018-08-19 fixed led state
2018-08-19 added LED turnoff during off state
2018-08-19 added dim power led during turn off
2018-08-19 added TIM2 CH1 for pwm for the power led
2018-08-19 made led turnoff brightness settings global
2018-08-19 moved averaging filter coeffizient
2018-08-20 changed inductors, current can now go up to 400mA
2018-08-20 added basic gamma correction
    [main.c]
2018-08-20 changed print ruotine
2018-08-20 changed filter values
2018-08-21 update schematic
2018-08-21 added TSC interrupt
2018-08-21 TSC works now in interrupt mode, slider is off by 1 pad
2018-08-21 fixed off by one bug
    [init_functions.c, main.c]
2018-08-21 fixed TSC bug, Gate resistors had to be increased
    [main.c]
2018-08-22 FLT1 works now, was a logic error
    [defines.h, init_functions.c, main.c]
2018-08-22 gamma correction is now working
    [main.c]
2018-08-22 improved filter values
2018-08-22 added LED temperature measurement
2018-08-23 added LED_task
2018-08-23 fixed power failure error
    [main.c]
2018-08-24 chanegd parameters
    [thread.scad]
2018-08-24 added Hardware V1.1 Schematic
2018-08-24 added Gerber files
    [Main.GBL, Main.GBO, Main.GBP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]
2018-08-24 fixed missing part
    [thread.scad]
2018-08-24 added fixture
    [thread.scad]
2018-08-25 added Inlet
    [Insert.stl]
2018-08-26 chnaged parameters
    [Insert.stl, thread.scad]
2018-08-28 reverted gamma correction for testing
    [main.c]
2018-09-08 reduced button threshold
2018-09-08 added battery voltage display
2018-09-11 added advanced gamma correction
    [utils.c]
2018-09-11 removed buggy battery voltage display, added gamma correction
    [main.c]
2018-09-17 fixed touch slider scale
    [defines.h]
2018-09-18 moved adc sampling time
2018-09-29 added I2C dma mode
2018-09-29 fixed i2c receive bug
    [init_functions.c, utils.c]
2018-09-30 kind of shitty fixed i2c
    [defines.h, init_functions.c, main.c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]
2018-09-30 i2c is now not blocking and failed i2c does not cause a crash anymore
    [init_functions.c, utils.c]
2018-09-30 has now low battery turnoff
2018-09-30 fixed i2c
2018-12-19 added V2 moved V1.1 dokumentation
    [Main.GBL, Main.GBO, Main.GBP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]
2018-12-20 moved files
    [Main.GBL, Main.GBO, Main.GBP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]
2019-01-16 fixed touch for V2
    [main.c]
2019-01-18 fixed LED names
2019-01-18 moved 3D files
    [thread.scad]
2019-04-13 fixed pwm
2019-08-04 added Hardware V2.1, complete redesign in KiCAD
    [cpu.sch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]
2019-08-04 added schematic pdf
2019-09-06 updated firmware to Hardware V2.1, fixed controller
    [defines.h, init_functions.c, main.c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]
2019-09-06 fixed ADC
2019-09-06 updated values
    [cpu.sch, main.csv, main.kicad_pcb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]
2019-09-06 RT9466 ADC does not work properly, shutdown works now
    [main.c, utils.c]
2019-09-06 added pwm on led2
2019-09-06 fixed opamp
    [main.kicad_pcb, power.sch]
2019-09-08 added led functions, fixed current gain, added flt
    [defines.h, init_functions.c, main.c]
2019-09-08 fixed voltage divider for current measurement
    [main.kicad_pcb, power.sch]
2019-09-08 added touch ic, fixed sk6812
    [cpu.sch, main.kicad_pcb, main.sch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]
2019-09-08 routed board
    [main.kicad_pcb]
2019-09-08 enlarged pads
    [main.kicad_pcb, main.sch]
2019-09-08 drc done
    [main.kicad_pcb]
2019-09-08 exported gerber
    [main-B.Cu.gbl, main-B.Mask.gbs, main-B.Paste.gbp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]
2019-09-08 finished animations, battery indicator still missing, fixed hardware bugs
    [defines.h, init_functions.c, main.c]
2019-11-24 added LED PCB
2020-01-01 updated bom
    [main.csv]
2020-03-21 increased timer resolution by 32
2020-03-23 fixed values
    [cpu.sch, main.kicad_pcb, main.sch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]
2020-03-24 fixed mobile touch bug
    [defines.h, main.c]

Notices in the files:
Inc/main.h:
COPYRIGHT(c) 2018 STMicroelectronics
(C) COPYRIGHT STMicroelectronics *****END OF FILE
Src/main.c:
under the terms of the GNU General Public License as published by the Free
